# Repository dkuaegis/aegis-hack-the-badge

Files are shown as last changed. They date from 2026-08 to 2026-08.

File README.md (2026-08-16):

# Hack The Badge Ver.3

## Sponsored by

<p align="center">
  <a href="https://easyeda.com/">
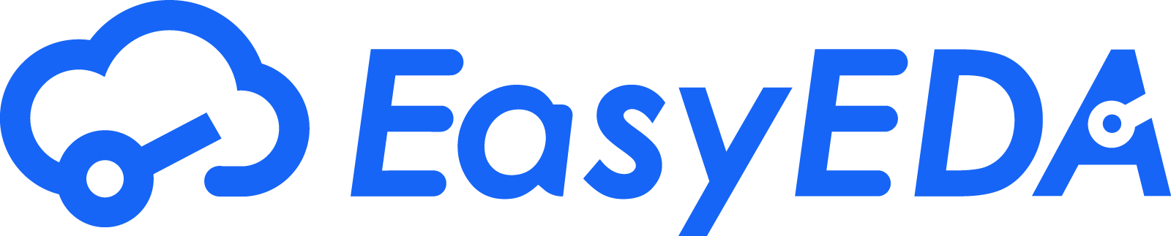
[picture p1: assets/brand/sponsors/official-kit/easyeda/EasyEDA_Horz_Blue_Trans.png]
EasyEDA
    
  </a>
  &nbsp;&nbsp;&nbsp;&nbsp;
  <a href="https://jlcpcb.com/">
    JLCPCB
  </a>
</p>

해당 프로젝트는 EasyEDA로 제작되었고 EasyEDA 측의 제작 지원을 받았습니다. <br>
PCB 제작은 JLCPCB 측의 지원을 받았습니다.

## 프로젝트 소개

`Hack The Badge Ver.3`는 정보보안 동아리 Aegis가 MSG CTF 본선
부스에서 운영하는 체험형 하드웨어 해킹 프로젝트입니다. ESP32-S3를
기반으로 OLED, 버튼, LED, USB Serial, UART, challenge pad, 부저를
하나의 PCB 배지에 구성해, 행사 배지와 해킹 문제 도구로 함께 사용할
수 있도록 제작했습니다.

## 제작 목적

참가자가 일반적인 소프트웨어 CTF를 넘어 실제 PCB의 입출력 장치와
통신 인터페이스를 직접 살펴보며 하드웨어 보안을 체험하도록 하는 것이
목표입니다. 문제 풀이 결과가 화면, LED, 소리로 즉시 반영되는 상호작용을
통해 하드웨어 해킹을 처음 접하는 참가자도 쉽게 몰입할 수 있도록
구성했습니다.

## 체험 활동

참가자는 배지를 USB로 연결한 뒤 다음 활동을 진행합니다.

- Serial 터미널에서 문제를 확인하고 FLAG를 제출합니다.
- OLED와 버튼으로 문제, 힌트, 미니게임을 이용합니다.
- UART와 challenge pad를 분석해 숨겨진 하드웨어 문제를 해결합니다.
- OLED, LED, 부저를 통해 문제 진행 상태와 완료 결과를 확인합니다.

## 현재 제작 리비전

- 리비전: Hack The Badge Ver.3
- MCU: ESP32-S3-WROOM-1-N8R8
- 디스플레이: HS96L03W2C03 0.96 inch I2C OLED, PCBA 이후 수작업 납땜
- 사용자 I/O: USB Serial, 3.3 V UART, 버튼 3개, 상태 LED 5개
- Challenge I/O: 1 kOhm 직렬 저항으로 보호되는 `C0`, `C1`, `C2` GPIO pad
- 관리자/디버그: 복구와 bring-up을 위한 후면 staff test pad
- 오디오: MOSFET으로 구동하는 passive buzzer
- PCB 스타일: 검정 solder mask, 흰색 silkscreen, Aegis 방패 외형

## 저장소 구조

```text
assets/brand/                         Aegis, MSG CTF, EasyEDA, JLCPCB 로고
docs/rev3/                            설계, 제작, 스폰서 관련 문서
hardware/design/rev3/kicad/           KiCad 호환 회로도, PCB, 라이브러리
hardware/design/rev3/reference/       BOM 메모, 데이터시트, 전기적 설계 메모
hardware/releases/rev3/jlcpcb/upload/ JLCPCB 업로드용 Gerber, BOM, CPL
hardware/releases/rev3/easyeda-pro/   EasyEDA Pro 프로젝트 패키지와 체크리스트
hardware/releases/rev3/jlcpcb/        제작 파일, 조립 파일, preview, 검증 리포트
archive/                              이전 설계/제작 이력
tools/                                문서 생성 보조 스크립트
firmware/                             ESP32-S3 문제/UI/관리자 펌웨어
```

펌웨어 빌드, 문제 교체, Serial 명령과 무선 관리자 사용법은
[`firmware/README.md`](firmware/README.md)를 참고하세요.

## 제작 산출물

JLCPCB 업로드 파일:

| 단계 | 파일 |
| --- | --- |
| PCB 제작 | `hardware/releases/rev3/jlcpcb/upload/hacking_badge_v3_jlcpcb_gerbers.zip` |
| PCBA BOM | `hardware/releases/rev3/jlcpcb/upload/hacking_badge_v3_jlcpcb_bom.csv` |
| PCBA CPL | `hardware/releases/rev3/jlcpcb/upload/hacking_badge_v3_jlcpcb_cpl.csv` |

EasyEDA Pro 프로젝트 패키지:

| 용도 | 파일 |
| --- | --- |
| EasyEDA Pro 실크 호환 프로젝트 | `hardware/releases/rev3/easyeda-pro/upload/hacking_badge_v3_easyeda_pro_silk_compat_import.zip` |
| EasyEDA Pro 프로젝트(KiCad 호환) | `hardware/releases/rev3/easyeda-pro/upload/hacking_badge_v3_easyeda_pro_kicad_import.zip` |
| EasyEDA Pro 프로젝트 아카이브 | `hardware/releases/rev3/easyeda-pro/reference/ProPrj_hack_the_badge_rev.3.epro2` |

## 3D Preview

홍보물 제작이나 웹/Blender preview에는 검정 PCB 색상이 보정된 GLB 파일을
사용하는 것을 권장합니다.

| 용도 | 파일 |
| --- | --- |
| 검정 PCB 홍보용 GLB | `hardware/releases/rev3/jlcpcb/preview/3d/hacking_badge_v3_full_assembly_black.glb` |
| 검정 PCB 3D export 묶음 | `hardware/releases/rev3/jlcpcb/preview/3d/hacking_badge_v3_3d_exports_black.zip` |
| 전체 3D export 묶음 | `hardware/releases/rev3/jlcpcb/preview/3d/hacking_badge_v3_3d_exports.zip` |

## 검증 상태

현재 확인된 상태:

- Schematic ERC: 0 errors, 0 warnings
- Schematic-to-PCB validation: PASS
- JLCPCB manufacturing validation: PASS
- Gerber ZIP SHA256:
  `b55b42de45568e995e8cb47bb18cfc09abd5469c50e1fb60852d323a703e96b1`

유용한 검증 명령:

```bash
/Applications/KiCad/KiCad.app/Contents/MacOS/kicad-cli sch erc \
  --format report \
  -o hardware/design/rev3/kicad/reports/erc-final.rpt \
  hardware/design/rev3/kicad/hacking_box_v2.kicad_sch

/Applications/KiCad/KiCad.app/Contents/Frameworks/Python.framework/Versions/3.9/bin/python3.9 \
  hardware/design/rev3/kicad/scripts/validate_schematic_against_pcb.py

/Applications/KiCad/KiCad.app/Contents/Frameworks/Python.framework/Versions/3.9/bin/python3.9 \
  hardware/design/rev3/kicad/scripts/validate_manufacturing.py
```

## 참고 사항

- KiCad 파일명은 초기 프로젝트/라이브러리 이름을 유지하기 위해
  `hacking_box_v2`를 사용합니다. 실제 제작 리비전은 Ver.3입니다.
- `OLED1`은 JLCPCB BOM/CPL에서 제외되어 있으며, 별도 구매 후 수작업으로
  납땜하는 기준입니다.
- JLCPCB SMT viewer에서 자동 placement alignment 알림이 뜨면 취소하고,
  기존 CPL 기준 배치가 유지되는지 확인합니다. 방패 형태의 custom outline
  때문에 false offset warning이 뜰 수 있습니다.
- Challenge pad는 3.3 V GPIO 전용입니다. 회로를 의도적으로 수정하지 않은
  상태에서 `VBUS`, `3V3`, `EN`, `BOOT` 단락을 문제 풀이 요소로 노출하지
  마세요.

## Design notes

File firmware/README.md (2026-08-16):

# Hack The Badge Rev.3 Firmware

ESP32-S3-WROOM-1-N8R8용 펌웨어입니다. 기존
[`Z3r0c0k3/hacking-box`](https://github.com/Z3r0c0k3/hacking-box) 최신
`main` 커밋 `4b0b2cd`의 Serial 문제 흐름과 영구 상태 저장 방식을 Rev.3 PCB에
맞게 다시 구현했습니다.

## 구현 기능

- USB CDC Serial(115200): 문제 설명, FLAG 제출, 상태 확인
- 128x64 OLED: 문제 보기/예시, 3버튼 메뉴, 반응속도 미니게임
- LED1-LED5: 4개 Serial 문제와 `Hidden Access` 풀이 상태
- NVS: 전원을 꺼도 풀이 상태 유지
- `Hidden Access`: 전면 challenge pad의 올바른 두 접점을 1.2초간 쇼트하면 해금
- Wi-Fi 관리자: 부팅 중 `LEFT + RIGHT`를 1.5초간 누른 경우에만 임시 AP/웹/API 활성화

관리자 AP와 웹 비밀번호는 부팅할 때마다 무작위로 생성되어 OLED와 Serial에
표시됩니다. `http://192.168.4.1`에 접속하고 사용자명 `admin`을 사용합니다.
일반 부팅에서는 무선 기능이 켜지지 않습니다.

운영자 확인용 기본 Hidden Access 조합은 **C1을 개방한 상태에서 C0-C2를
1.2초간 연결**하는 것입니다. 조합이나 유지 시간은 `logic.h`와 `main.cpp`의
`HIDDEN_HOLD_MS`에서 변경할 수 있습니다.

## 빌드와 업로드

PlatformIO에서 다음을 실행합니다.

```bash
cd firmware
pio run
pio run -t upload
pio device monitor
```

보드는 ESP32-S3 DevKitC 프로필, 8 MB flash, 8 MB octal PSRAM 설정을
사용합니다. USB CDC가 보이지 않으면 BOOT를 누른 채 리셋해 처음 한 번
업로드한 뒤 다시 연결하세요.

## 문제 교체

[`src/problems.h`](src/problems.h)의 `PROBLEMS` 배열만 수정합니다.

- `title`: OLED와 상태표에 표시할 짧은 ASCII 제목
- `answer`: Serial에서 비교할 정확한 FLAG
- `serialText`: Serial에 출력할 문제 설명
- `oledLines`: OLED에만 출력할 보기/예시 5줄(줄당 ASCII 16자 권장)

Rev.3 상태 LED가 5개이므로 기본 구성은 Serial 문제 4개 + Hidden Access 1개입니다.
문제 개수를 바꾸려면 LED 정책과 `static_assert`도 함께 검토해야 합니다.

미니게임 보상 힌트는 같은 파일의 `MINIGAME_REWARD_LINE_1/2`를 바꾸면 됩니다.

## Serial 명령

| 명령 | 기능 |
| --- | --- |
| `1`~`4` | 문제 선택 |
| `hint` | 선택한 문제의 OLED 보기 다시 표시 |
| `exit` | 문제 풀이 모드 종료 |
| `status` | 전체 풀이 상태 |
| `help` | 사용법 |
| `reset` | 풀이 상태 초기화 |
| `aegis` | 시작 배너 다시 표시 |

## 관리자 API

HTTP Basic 인증이 필요합니다.

| Method | Path | 기능 |
| --- | --- | --- |
| GET | `/api/status` | 풀이 상태 JSON |
| POST | `/api/solve?id=1` | 지정 문제 성공 처리(1~5) |
| POST | `/api/reset` | 전체 상태 초기화 |
| POST | `/api/reboot` | 재부팅 |

## 안전 및 핀 매핑

핀은 [`src/pins.h`](src/pins.h)에 있으며 PCB 회로 문서와 동일합니다. Hidden
Access 감지 중 C0는 LOW로만 구동되고 C1/C2는 pull-up 입력입니다. 펌웨어의
의도된 쇼트 대상은 보호 저항 뒤의 challenge pad뿐입니다. `3V3`, `VBUS`,
`EN`, `BOOT` 또는 GND를 임의로 쇼트하지 마세요.

OLED는 전체 1 KB framebuffer 대신 U8x8 text mode를 사용하고, Serial 입력도
고정 192바이트 버퍼를 사용해 동적 메모리 사용을 줄였습니다.

## 빠른 로직 검사

PlatformIO 없이도 상태 비트와 Hidden Access 판정 로직을 검사할 수 있습니다.

```bash
clang++ -std=c++17 -Ifirmware/src firmware/test/test_logic.cpp -o /tmp/badge-logic-test
/tmp/badge-logic-test
```

## Wokwi 통합 시뮬레이션

VS Code에서 `firmware` 폴더를 열고 PlatformIO로 한 번 빌드한 다음,
Command Palette의 `Wokwi: Start Simulator`를 실행합니다.

```bash
pio run
```

`diagram.json`은 Rev.3의 펌웨어 관찰 가능 회로를 다음과 같이 재현합니다.

- SSD1315와 명령어 호환되는 `board-ssd1306` OLED: GPIO4/5, I2C `0x3c`
- Left/OK/Right active-low 버튼: GPIO9/10/12, 키보드 ←/Space/→
- active-high 상태 LED 5개: GPIO13-17, 실회로와 같은 1k 직렬 저항
- 부저 드라이버 등가 출력: GPIO18
- challenge pad 직렬 저항 1k와 C0-C1/C0-C2 쇼트 스위치

Hidden Access는 `H`를 1.2초 이상 눌러 C0-C2를 연결하면 됩니다. `J`는
C0-C1을 연결하는 오답 조합입니다. 관리자 부팅은 Left와 Right 버튼을
Cmd-click해 둘 다 고정한 뒤 ESP32-S3 보드의 RST 버튼을 누릅니다.

Wokwi는 GPIO, I2C, 버튼, LED, 부저, USB CDC 편의 동작을 검사하며,
USB-C 전기 특성, 3.3V 전원, ESD, MOSFET 부하, RF와 실제 OLED 편차는
실물 보드에서 별도로 검사해야 합니다.

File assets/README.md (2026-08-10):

# Brand Assets

- `brand/aegis/`: Aegis 원본 SVG와 문서용 PNG
- `brand/msg-ctf/`: 후면 음각에 사용하는 MSG CTF 원본 PNG
- `brand/sponsors/jlcpcb-logo.svg`: 전면 실크에 사용하는 단색 sponsor SVG
- `brand/sponsors/official-kit/`: JLCPCB/EasyEDA가 제공한 원본 로고 패키지

PCB 생성 스크립트는 이 폴더의 원본을 직접 참조합니다.

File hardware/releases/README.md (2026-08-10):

# Hardware Releases

- `rev3/jlcpcb/`: 현재 생산에 사용하는 JLCPCB Rev.3 릴리스
- `rev3/jlcpcb/upload/`: JLCPCB 주문 화면에 직접 업로드하는 Gerber ZIP,
  BOM, CPL

다른 제조사 견적과 과거 출력은 `archive/manufacturing/`에 보관합니다.

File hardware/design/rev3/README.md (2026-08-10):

# Hardware Design Rev.3

- `kicad/`: 현재 편집 가능한 KiCad 프로젝트, 로컬 라이브러리와 검증 도구
- `reference/bom/`: BOM 초안과 부품 선정 근거
- `reference/datasheets/`: 설계에 사용한 부품 데이터시트
- `reference/electrical/`: 회로 설명과 넷리스트 문서

제조사 업로드 파일은 `../../releases/rev3/jlcpcb/upload/`에 있습니다.

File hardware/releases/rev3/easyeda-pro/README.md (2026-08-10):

# Hacking Badge Ver.3 EasyEDA Pro Package

This directory contains the EasyEDA Pro preparation package for sponsor/coupon
workflow.

## Upload / Import Files

| Purpose | File |
| --- | --- |
| Recommended EasyEDA Pro import package | `upload/hacking_badge_v3_easyeda_pro_silk_compat_import.zip` |
| Raw KiCad source import package | `upload/hacking_badge_v3_easyeda_pro_kicad_import.zip` |
| Previous EasyEDA Pro archive reference | `reference/ProPrj_hack_the_badge_rev.3.epro2` |

Use the silkscreen-compatible import package first when the goal is sponsor
review or coupon use in EasyEDA Pro. It is derived from the current production
KiCad design, but converts filled silkscreen polygons into dense line artwork
because EasyEDA Pro's KiCad importer can otherwise show complex filled logos as
hollow outlines. The raw KiCad import package is kept only as a reference for
format comparison. The `.epro2` file is kept as a reference/native archive
candidate, but it was generated before the final KiCad release checks and must
not be assumed to be identical without review.

## Import Procedure

1. Open EasyEDA Pro.
2. Use the start page import flow for KiCad files, or use the EasyEDA Pro Format
   Converter if direct import fails.
3. Select `upload/hacking_badge_v3_easyeda_pro_silk_compat_import.zip`.
4. After import, open both schematic and PCB.
5. Rebuild/refill copper zones only if EasyEDA Pro asks for it, then compare
   against the KiCad release previews and Gerbers.
6. Run EasyEDA Pro DRC/ERC before using any generated manufacturing output.

## Required Post-Import Checks

- Board outline remains the Aegis shield shape, approximately 84.05 x 100.05 mm.
- USB-C connector sits on the bottom edge with the intentional edge overhang.
- ESP32-S3 antenna keep-out is still clear.
- Front silkscreen includes `Aegis X MSG CTF`, `HACK THE BADGE Ver.3`,
  `Developed By @Z3r0c0k3_`, full Aegis logo, and sponsor mark.
- Rear silkscreen preserves the filled Aegis silhouette and MSG CTF negative
  mark.
- Filled logo areas may look lightly striped at extreme zoom because the
  EasyEDA-compatible package uses dense silkscreen lines instead of KiCad
  filled polygons.
- `C0`, `C1`, `C2` challenge pads route through 1 kOhm series resistors to
  ESP32-S3 GPIO6, GPIO7, GPIO8.
- OLED pin order remains `GND, VCC, SCL, SDA`.
- J1, U1, U2, D1, Q_BZ, LEDs, buzzer diode, and switches have correct rotation.
- Copper zones and clearances match the KiCad/JLCPCB manufacturing release.

## Important Warning

The routed KiCad project and the JLCPCB release package remain the production
source of truth until the EasyEDA Pro import is manually reviewed. EasyEDA Pro
can import KiCad files, but format conversion can change copper-zone results.
Do not manufacture from newly generated EasyEDA Pro Gerbers until visual review,
DRC/ERC, and pin/net checks pass.

## Checksums

See `SHA256SUMS.txt`.

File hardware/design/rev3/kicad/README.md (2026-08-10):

# Hacking Badge Ver.3 KiCad Project

This directory contains the routed production PCB, connected review
schematic, project-local symbols and footprints, 3D assets, and electrical
verification reports for the ESP32-S3 Hacking Badge Ver.3.

## Directory Layout

- Project root: editable KiCad project and local libraries only.
- `scripts/`: deterministic generation and validation scripts.
- `reports/`: current DRC, ERC, netlist, and validation reports.
- `exports/`: current human-readable schematic and 3D PDF exports.
- Historical PCB revisions, autorouter sessions, rescue files, and superseded
  renders live in `../../../../archive/design/rev3-development/` and are not
  used for production.

## Main Design Files

- `hacking_box_v2.kicad_sch`: connected one-page A3 production schematic.
- `hacking_box_v2.kicad_pcb`: routed two-layer production PCB.
- `hacking_box_v2.kicad_pro`: KiCad project settings.
- `exports/hacking_box_v2_schematic.pdf`: printable schematic.
- `hacking_box_v2-cache.lib`: project-local legacy symbol source.
- `sym-lib-table`: local symbol-library registration.
- `hacking_box_v2.pretty/`: local buzzer and OLED footprints.
- `hacking_box_v2.3dshapes/`: local OLED 3D model.
- `../reference/datasheets/HS96L03W2C03.pdf`: source module datasheet used for the
  OLED outline, mounting holes, pin order, and hand-solder pad review.

The notes-only schematic that preceded the connected capture is archived at
`../../../../archive/design/rev3-development/pcb-revisions/hacking_box_v2_notes_only_2026-07-28.kicad_sch`.

## Schematic Organization

The A3 sheet groups USB-C and power, ESP32-S3, OLED, five status LEDs, three
game controls, challenge pads, player UART, rear staff testpoints, and the
buzzer driver. Global net labels make each PCB net explicit without long
cross-sheet wires.

The schematic was reverse-captured from the finished PCB. It is electrically
equivalent to the PCB, but this revision did not originate through KiCad's
normal schematic-first association flow. Review symbol-footprint associations
before using **Update PCB from Schematic**.

## Verification

- Schematic ERC: 0 errors, 0 warnings.
- Schematic-to-PCB validation: PASS.
- Components: 60 in schematic and PCB.
- Named nets: 37 in schematic and PCB.
- Connected component-pin pairs: 149.
- Intentional no-connect pins: 20.
- PCB DRC: 0 error-level violations and 0 unconnected items.

Reports:

- `reports/erc-final.rpt`
- `reports/schematic-pcb-validation.txt`
- `reports/drc_report_jlcdfm_fixes.txt`

## Regeneration

Run `scripts/generate_production_schematic.py` with KiCad's bundled Python to
recreate the legacy capture and local symbol library from PCB pad/net data.
Open the generated `hacking_box_v2.sch` in KiCad and save it to refresh the
modern `.kicad_sch`.

Run `scripts/add_jlcpcb_sponsor_logo.py` with KiCad's bundled Python to rebuild
the front `Sponsored by` EasyEDA/JLCPCB sponsor mark in the left-center
silkscreen area. The script groups the generated logo polygons and restores the
lower-left decorative border that was previously interrupted by the old
JLCPCB-only mark.

Export an XML netlist, then run
`scripts/validate_schematic_against_pcb.py` with KiCad's bundled Python. The
validator compares references, values, named pin-to-net mappings, and
intentional no-connect pins.

## Manufacturing

The order artifacts are in `hardware/releases/rev3/jlcpcb/`; the three files
uploaded to JLCPCB are isolated in its `upload/` directory. `OLED1` is excluded
from the JLCPCB BOM/CPL and appears in `assembly/` as a separate manual list. Its
footprint uses 2.0 mm pads with a 1.1 mm nominal PTH drill for hand soldering.
The Gerber, drill, BOM, CPL, and validation reports were regenerated after
this change and the supplied JLCDFM findings. The final fabrication package
uses 0.80 mm plated USB-C slots, 0.20 mm minimum drills, 0.15 mm minimum
silkscreen strokes, and mask-subtracted silkscreen output.

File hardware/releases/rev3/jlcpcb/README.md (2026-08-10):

# Hacking Badge Ver.3 Manufacturing Package

This directory is the final revision 3 JLCPCB upload package.

## Upload These Files

| JLCPCB step | File |
| --- | --- |
| PCB fabrication | `upload/hacking_badge_v3_jlcpcb_gerbers.zip` |
| PCBA BOM | `upload/hacking_badge_v3_jlcpcb_bom.csv` |
| PCBA CPL | `upload/hacking_badge_v3_jlcpcb_cpl.csv` |

Recommended order options:

- Quantity: 5
- Layers: 2
- PCB thickness: 1.6 mm
- Solder mask: black
- Silkscreen: white
- PCBA: top side SMT only; `OLED1` is excluded and hand-soldered afterward

## Package Contents

- `upload/`: the three files uploaded directly to JLCPCB.
- `fabrication/gerber/`: uncompressed Gerber, drill, drill-map, and Gerber job files.
- `fabrication/hacking_badge_v3.ipc`: IPC-2581 exchange export.
- `assembly/hacking_badge_v3_assembly.glb`: complete visual assembly model.
- `assembly/hacking_badge_v3_assembly.step`: mechanical assembly export. The custom OLED
  VRML model may not be embedded in this STEP; use the GLB or PNG previews for
  complete visual review.
- `preview/`: top, bottom, and isometric KiCad renders.
- `reports/`: DRC, drill, board statistics, JLCDFM disposition, and automated
  package validation.
- `assembly/hacking_badge_v3_manual_assembly.csv`: locally sourced parts that are not
  uploaded to JLCPCB.

## Verified State

- KiCad electrical DRC: 0 errors and 0 unconnected items. Two source-layout
  warnings remain on the board-scale rear logo by design; the production
  Gerbers subtract solder-mask openings from silkscreen before plotting.
- JLCDFM hardening: 0.20/0.25 mm via drills, at least 0.20 mm via annular
  rings, 0.80 mm USB-C plated slots, 0.15 mm minimum silkscreen strokes,
  0.05 mm global solder-mask expansion, and 0.13 mm minimum mask web.
- Gerber ZIP: exact 12-file fabrication set.
- Board: 2 layers, 1.6 mm, approximately 84.05 x 100.05 mm.
- Assembly: 15 grouped BOM lines and 44 unique top-side placements.
- Buzzer circuit populated: SMD5020-ZK, AO3400A, 1N4148W, gate resistors, and
  local 10 uF capacitor.
- OLED installed manually after PCBA: locally sourced HS96L03W2C03, white
  0.96 inch 128x64 SSD1315 I2C module. The manual list recommends six modules
  for five boards so one spare is available.
- Game controls populated: `<-` on GPIO9, `OK` on GPIO10, and `->` on GPIO12.
- Front logo reproduces the complete circular source logo. Its original white
  regions print on F.SilkS and its black regions show through as black PCB.
- The front sponsor mark appears inside the left-center F.SilkS guide area as
  `Sponsored by`, `EasyEDA`, and `JLCPCB`; the previous lower-left JLCPCB-only
  mark was removed and the decorative border there was restored.
- Rear Aegis silhouette is filled with white B.SilkS at board scale. The
  30 mm MSG CTF mark is negative space that exposes the black solder mask.
- Rear staff testpoints and their labels are shifted 4 mm downward, clear of the
  logo artwork, and their local routes were revalidated after the move.

The detailed disposition of every item in the supplied PCB and SMT DFM reports
is recorded in `reports/jlcdfm_resolution.md`.

## Order Review

The CPL uses KiCad's manufacturing coordinate system, matching the Gerber and
official KiCad position export: X is unchanged and all top-side Y coordinates
are negative. The package validator rejects a CPL generated with the PCB
editor's downward-positive Y axis.

The CPL also contains verified per-package placement corrections for J1
(`C165948`), U1 (`C2913201`), U2 (`C6186`), D1 (`C2827654`), and Q_BZ
(`C20917`). The affected LCSC/EasyEDA origins or rotations do not coincide with
the KiCad footprint anchors. Do not replace these rows with the uncorrected
KiCad position-export values.

When JLCPCB shows the reminder `The system detects component that may be
offset from the PCB, does it try to automatically align it?`, select `Cancel`.
The custom shield outline and the intentional USB-C edge overhang can trigger
this false positive. Selecting `Ok` can translate or mirror the complete
placement set away from the PCB. If that happens, upload the original BOM and
CPL again; do not manually drag the scattered components into place.

Before payment, inspect every polarized or pin-1-sensitive part in the JLCPCB
placement preview, especially `U1`, `J1`, `D1`, `D_BZ`, `Q_BZ`, all LEDs, and
the tactile switches. Recheck LCSC stock because availability and PCBA class
can change.

The similar USB-C STEP model in the KiCad 3D view is visualization-only. The
fabrication footprint and BOM selection remain TYPE-C-31-M-12 (`C165948`).

The OLED module is excluded from both JLCPCB upload files. After PCBA, install
it on the front with pin order `GND, VCC, SCL, SDA` and connect VCC only to
3.3 V. The footprint uses 2.0 mm pads with a 1.1 mm nominal PTH drill for practical
hand soldering. If the module is supplied without pins, use a straight 1x4
2.54 mm male header.

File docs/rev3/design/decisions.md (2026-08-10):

# Hack The Badge / Hacking Box V2 Phase 1 Decision Log

Status: Phase 1 decision log for JLCPCB support preparation. Items marked as
"approved for Phase 1" are approved only as requirements for the next design
step. They are not final PCB fabrication approval.

## Approved For Phase 1

| ID | Decision | Reason |
| --- | --- | --- |
| D-001 | Prepare documentation before schematic and PCB work. | The project needs a clear support package before hardware design proceeds. |
| D-002 | Target a small-run event PCB for Hack The Badge / Hacking Box V2. | The device is for a CTF booth, not mass production. |
| D-003 | Use an ESP32-S3-WROOM module as the recommended MCU baseline. | It provides native USB, optional Wi-Fi/BLE, enough memory, and lower RF risk than a bare chip. |
| D-004 | Use USB-C as the default connector for power, serial, and recovery. | It is convenient for both participants and booth staff. |
| D-005 | Limit participant-facing interfaces to USB Serial, UART, and protected challenge GPIO pads. | This provides an intentional hacking surface while reducing accidental exposure of fragile signals. |
| D-006 | Design exposed digital interfaces for 3.3 V logic. | This matches ESP32-S3 and modern peripheral requirements. |
| D-007 | Include a 128x64 I2C OLED as the baseline display. | It can show logos, status, and challenge messages in a compact area. |
| D-008 | Include multiple status LEDs. | Participants and staff can quickly read challenge progress. |
| D-009 | Include three tactile switches as baseline inputs. | They can support left/OK/right navigation, mini-games, or an admin-unlock gesture. |
| D-010 | Treat Wi-Fi/BLE as staff-only unless separately approved for gameplay. | This helps prevent management features from becoming an unintended bypass. |
| D-011 | Exclude battery charging from Phase 1. | USB-only power is simpler, safer, and easier to review for the first PCB design. |
| D-012 | Prefer a 2-layer PCB and mostly single-side SMT assembly. | This keeps small-run fabrication and assembly cost manageable. |

## V1 Compatibility Decisions

| ID | Decision | Reason |
| --- | --- | --- |
| C-001 | Review V1 firmware before freezing the pin map. | The current repository does not include V1 firmware source, so exact compatibility cannot be verified yet. |
| C-002 | Plan V2 firmware as an ESP32-S3 port or rewrite. | Arduino Nano/ATmega328P binaries cannot run directly on ESP32-S3. |
| C-003 | Preserve participant-facing USB Serial behavior by default. | This is likely the main continuity point from the existing challenge flow. |
| C-004 | Preserve or port UART challenge behavior at 3.3 V. | UART is part of the intended hacking surface, but ESP32-S3 pins are not 5 V tolerant. |
| C-005 | Keep challenge state visible through LEDs and/or OLED. | Event staff and participants need quick visual state confirmation. |

## Open Decisions Requiring Approval

The following items must be resolved after V1 firmware review and before
schematic capture.

| ID | Area | Decision needed | Why it matters |
| --- | --- | --- | --- |
| O-001 | V1 firmware | Provide the actual V1 source, archive, or pin documentation. | Compatibility should be verified from code, not assumptions. |
| O-002 | MCU | Confirm the exact ESP32-S3-WROOM part number, flash size, and PSRAM size. | This affects BOM, firmware partitioning, price, and availability. |
| O-003 | Quantity | Confirm whether the first build is 5 units, 10 units, or another quantity. | Quantity affects unit price, spare strategy, and assembly choices. |
| O-004 | OLED assembly | Decide whether the OLED is included in PCBA or hand-soldered after assembly. | This affects BOM/CPL, footprint choice, manual work, and replacement strategy. |
| O-005 | Buzzer | Approve or remove the buzzer circuit. | It adds useful feedback but increases board area, BOM lines, and firmware work. |
| O-006 | Challenge pads | Finalize pad count, labels, protection, and intended solve path. | This defines the core hardware hacking experience. |
| O-007 | Button roles | Decide whether buttons are player controls, admin unlock, mini-game inputs, or a mix. | This affects labeling, placement, and firmware behavior. |
| O-008 | Wireless management | Define Wi-Fi/BLE mode, authentication, provisioning, and whether wireless remains enabled during attempts. | Management access must not become an unintended challenge bypass. |
| O-009 | Power budget | Confirm worst-case current for ESP32-S3 radio, OLED, LEDs, and buzzer. | This determines regulator choice and thermal margin. |
| O-010 | Protection | Decide whether USB fuse/PTC, extra ESD, or stronger GPIO protection is required. | The board will be handled directly by participants. |
| O-011 | Shape and artwork | Approve final outline, logo placement, silkscreen text, and event branding. | These affect manufacturability and sponsor-facing presentation. |
| O-012 | Staff recovery | Decide whether EN/BOOT are pads only or physical buttons. | This balances event recovery convenience against accidental participant access. |
| O-013 | Assembly vendor | Confirm JLCPCB as the first-run assembly vendor or select an alternative. | Part availability, PCBA process, and output formats depend on the vendor. |
| O-014 | Distribution model | Decide whether boards are reused, collected, or given to participants. | This affects durability expectations, labeling, and acceptable cost. |

## Risks To Resolve Before Schematic Capture

- V1 firmware is missing from this repository, so hardware compatibility
  requirements are not yet verified.
- ESP32-S3 uses 3.3 V logic; any V1 dependency on Arduino Nano 5 V behavior
  requires redesign, level shifting, or explicit removal.
- Participant-accessible pads need protection resistors and clear voltage
  labeling.
- Wi-Fi/BLE management requires authentication and a physical or procedural
  unlock policy.
- The exact OLED module pin order and availability must be confirmed before
  final footprint approval.
- Live JLCPCB stock, PCBA part class, and assembly cost should be rechecked
  immediately before final BOM approval.

## Phase 1 Exit Criteria

Phase 1 is complete when:

- The project owner has reviewed this decision log.
- The availability or absence of V1 firmware source has been explicitly
  acknowledged.
- The open decisions required for schematic capture have been approved.
- The proposed pin map has been accepted as a firmware-port target or revised
  based on V1 firmware evidence.

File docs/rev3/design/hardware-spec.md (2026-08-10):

# Hack The Badge / Hacking Box V2 Phase 1 Hardware Specification

Status: Phase 1 project description and hardware requirements draft. This
document is prepared for JLCPCB fabrication and PCBA support review. It is not a
schematic, PCB layout, Gerber package, BOM/CPL release, or production approval.

## Project Overview

Hack The Badge is a hardware hacking badge project for the Aegis booth at the
MSG CTF event. The board should look and feel like an event badge while also
serving as a small interactive challenge device. Participants connect to and
interact with the badge through USB Serial, UART, exposed challenge pads,
buttons, LEDs, and a small OLED display.

The goal of Hacking Box V2 Phase 1 is to define a manufacturable PCB baseline
that can replace or extend the existing V1 prototype while preserving the
participant-facing challenge flow as much as possible. This phase documents the
requirements and open questions that must be approved before schematic capture
and PCB layout begin.

## Why JLCPCB Support Is Needed

The project is moving from a prototype-style build toward a repeatable
small-run PCB suitable for event use. We are preparing to request support from
JLCPCB for:

- Reviewing the proposed hardware architecture before schematic capture.
- Selecting parts suitable for low-volume JLCPCB SMT assembly.
- Checking whether the participant-accessible interfaces are electrically safe.
- Reducing manual wiring and assembly errors compared with the V1 prototype.
- Confirming whether the planned OLED, USB-C, buttons, LEDs, and buzzer are
  practical for PCBA or should be handled as manual assembly.
- Preparing a clear requirements package before generating Gerbers, BOM, and
  CPL files.

Phase 1 does not create a schematic, PCB layout, Gerber ZIP, BOM, or CPL. These
documents are intended to align the project scope and approval items before the
next hardware design phase.

## Target Use Case

| Item | Requirement |
| --- | --- |
| Event role | CTF booth hardware hacking badge / Hacking Box |
| Users | Participants, booth staff, firmware maintainers |
| Expected quantity | Small run, assumed 5-10 units unless approved otherwise |
| Power | USB-powered by default |
| Participant interfaces | USB Serial, 3.3 V UART, intentional GPIO challenge pads |
| Staff interfaces | USB recovery/flashing, optional Wi-Fi/BLE management |
| Visual identity | Aegis / MSG CTF branding, OLED status, PCB silkscreen |
| Manufacturing target | 2-layer PCB, mostly single-side SMT assembly where practical |

## Recommended Hardware Architecture

| Function | Phase 1 baseline | Reason |
| --- | --- | --- |
| MCU | ESP32-S3-WROOM module | Native USB, optional Wi-Fi/BLE, enough memory, lower RF layout risk than a bare chip |
| Logic voltage | 3.3 V | Matches ESP32-S3 and modern OLED modules |
| USB | USB-C device port | Power, serial console, firmware upload, staff recovery |
| Display | 0.96 inch 128x64 I2C OLED | Compact logo, status, and challenge text display |
| Input | Three tactile switches | Left/OK/right controls, mini-game input, or admin-unlock gesture |
| Output | Five status LEDs | Clear challenge progress and solved-state indication |
| Audio | Passive buzzer with MOSFET driver, if approved | Audible feedback without directly loading an MCU GPIO |
| Challenge I/O | UART plus three protected GPIO pads | Intentional hardware hacking surface |
| Wireless | Staff-only Wi-Fi/BLE, if used | Reset, provisioning, and status monitoring without exposing management functions to players |

## Electrical Requirements

### USB And Power

- USB-C should be configured as a USB 2.0 device port.
- VBUS should feed a 3.3 V regulator with enough current and thermal margin for
  the ESP32-S3, OLED, LEDs, and optional buzzer.
- USB D+ and D- should include ESD protection and follow ESP32-S3 native USB
  routing recommendations.
- Staff recovery access for EN/reset and BOOT mode must be available.
- Battery charging is out of scope unless separately approved.

### Controller

- Prefer an ESP32-S3-WROOM module variant that is available through the selected
  assembly flow.
- Respect the ESP32-S3 module antenna keep-out area.
- Avoid using boot strapping pins for participant-facing challenge signals.
- Select a module with enough firmware headroom for the OLED UI, challenge
  logic, and optional staff management features.

### Display

- Use an SSD1306/SSD1315-compatible 128x64 I2C OLED.
- Treat the default I2C address as `0x3C` until the exact module datasheet is
  confirmed.
- If the OLED module is not suitable or economical for JLCPCB assembly, it may
  be hand-soldered after PCBA.
- Firmware should be able to show the Aegis / MSG CTF logo and challenge status
  on the display.

### Participant-Accessible Interfaces

- USB Serial remains the primary participant interface.
- Provide a separate 3.3 V UART TX/RX interface through labeled pads or a small
  header.
- Add series resistors or equivalent protection to exposed challenge GPIO pads.
- All exposed digital signals must be documented as 3.3 V only and not
  5 V tolerant.
- Keep I2C internal by default unless the final challenge design explicitly
  requires exposing it.

### Feedback Devices

- Status LEDs should be active-high unless V1 firmware review requires a
  different polarity.
- Buttons should be active-low with firmware pull-ups or hardware pull-ups.
- If a passive buzzer is used, it must be driven with PWM rather than a static
  high level.
- The buzzer should be driven through a MOSFET or transistor driver instead of
  directly from an MCU GPIO.

## V1 Firmware Compatibility Review

This repository does not currently include V1 firmware source files such as
Arduino `.ino`, C/C++ source, PlatformIO configuration, or a documented V1 pin
map. Therefore, Phase 1 cannot claim binary compatibility or source-level
compatibility with V1.

The inferred compatibility requirements are:

- Preserve the participant-facing USB Serial challenge workflow.
- If V1 used a UART challenge, port that behavior to a 3.3 V UART interface.
- Preserve visible challenge progress through multiple status LEDs.
- If V1 used physical button input, preserve the same participant-facing
  interaction using ESP32-S3 GPIO inputs.
- If V1 used a display, port the logo/status behavior to a 128x64 I2C OLED.
- Staff must be able to recover boards at the event using USB flashing, reset,
  and BOOT mode access.
- Because ESP32-S3 cannot run ATmega328P/Arduino Nano binaries, V2 firmware
  should be treated as a port or rewrite.

Before schematic capture, the actual V1 firmware repository or source archive
should be reviewed for:

- V1 pin assignments.
- Serial baud rate and command protocol.
- Startup, reset, and challenge state behavior.
- Timing-sensitive GPIO behavior.
- Display library and resolution assumptions.
- Any dependency on Arduino Nano 5 V electrical behavior.

## Mechanical And Visual Requirements

- Use a badge-like PCB outline, preferably inspired by the Aegis shield.
- Preferred visual direction: black solder mask with white silkscreen.
- The front side should clearly show the Hack The Badge, Aegis, and MSG CTF
  identity.
- USB-C should be placed on an accessible board edge with cable clearance.
- Participant pads should be reachable and identifiable, but the labeling
  should not reveal the complete challenge solution.
- Staff-only recovery pads should be separated from the primary participant
  interaction area.

## JLCPCB Review Questions

- Which ESP32-S3-WROOM module variant is recommended for availability and PCBA
  cost?
- Should the OLED module be included in PCBA or handled as manual assembly?
- Are the proposed USB-C receptacle, tactile switches, LEDs, and buzzer suitable
  for single-side SMT assembly?
- Is an input fuse/PTC recommended for a participant-handled USB-powered board?
- Are additional ESD or protection components recommended for exposed UART and
  challenge pads?
- Are there any design-for-manufacturing concerns with a shield-shaped outline
  and decorative silkscreen artwork?

## Phase 1 Deliverables

- `docs/rev3/design/hardware-spec.md`: project description and hardware requirements.
- `docs/rev3/design/decisions.md`: approved decisions, deferred decisions, and open items.
- `docs/rev3/design/pin-map.md`: proposed pin map and V1 firmware compatibility notes.

## Out Of Scope For Phase 1

- KiCad schematic creation.
- PCB layout.
- Gerber, BOM, or CPL generation.
- Final component purchase.
- Production order placement.
- Firmware port implementation.

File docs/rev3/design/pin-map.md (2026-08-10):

# Hack The Badge / Hacking Box V2 Phase 1 Pin Map

Status: Proposed firmware-facing pin map for review. This is not a frozen PCB
pinout. It must be checked against the V1 firmware before schematic capture.

## Pin Map Goals

- Keep USB Serial available for participants and firmware flashing.
- Provide UART and challenge GPIO pads as intentional hacking interfaces.
- Avoid ESP32-S3 boot strapping pins for normal participant challenge signals.
- Keep OLED, LEDs, buttons, and buzzer simple to port in firmware.
- Leave EN and BOOT access available for staff recovery.

## Proposed ESP32-S3 Assignment

| Function | Proposed ESP32-S3 signal | Direction | Electrical behavior | Notes |
| --- | --- | --- | --- | --- |
| USB D- | `GPIO19` | USB | Native USB | Effectively fixed for ESP32-S3 native USB |
| USB D+ | `GPIO20` | USB | Native USB | Effectively fixed for ESP32-S3 native USB |
| OLED SDA | `GPIO4` | I/O | 3.3 V I2C with pull-up | Confirm final OLED module pull-ups |
| OLED SCL | `GPIO5` | Output | 3.3 V I2C with pull-up | Assumed display address: `0x3C` |
| Challenge pad 0 | `GPIO6` | I/O | 3.3 V through series resistor | Expose only after challenge design approval |
| Challenge pad 1 | `GPIO7` | I/O | 3.3 V through series resistor | Expose only after challenge design approval |
| Challenge pad 2 | `GPIO8` | I/O | 3.3 V through series resistor | Expose only after challenge design approval |
| Left button | `GPIO9` | Input | Active-low with pull-up | Player control or menu navigation |
| OK button | `GPIO10` | Input | Active-low with pull-up | Confirm/action input |
| Right button | `GPIO12` | Input | Active-low with pull-up | Player control or admin-chord candidate |
| Status LED 1 | `GPIO13` | Output | Active-high | Initialize low at boot |
| Status LED 2 | `GPIO14` | Output | Active-high | Initialize low at boot |
| Status LED 3 | `GPIO15` | Output | Active-high | Initialize low at boot |
| Status LED 4 | `GPIO16` | Output | Active-high | Initialize low at boot |
| Status LED 5 | `GPIO17` | Output | Active-high | Initialize low at boot |
| Buzzer PWM | `GPIO18` | Output | MOSFET-driven PWM | Use only if buzzer is approved |
| Player UART TX | `GPIO43` | Output | 3.3 V through series resistor | Board transmits to participant equipment |
| Player UART RX | `GPIO44` | Input | 3.3 V through series resistor | Not 5 V tolerant |
| Boot mode | `GPIO0` | Input | Pull-up, staff access | Do not use as challenge GPIO |
| Reset / enable | `EN` | Input | Pull-up, staff access | Recovery/reset only |

## Participant-Facing Interfaces

| Interface | Signals | Voltage | Compatibility requirement |
| --- | --- | --- | --- |
| USB Serial | USB D+, USB D-, VBUS, GND | USB 5 V power, native USB data | Preserve the same user experience if V1 used a Serial command flow |
| UART pads | TX, RX, GND, optional 3V3 reference | 3.3 V logic | Port V1 UART challenge behavior to ESP32-S3 |
| Challenge pads | `GPIO6`, `GPIO7`, `GPIO8`, GND reference | 3.3 V GPIO | Final behavior must match the approved challenge design |
| Buttons | Left, OK, Right | Active-low 3.3 V | Preserve V1 physical interactions if present |

## Internal Interfaces

| Interface | Signals | Notes |
| --- | --- | --- |
| OLED | SDA, SCL, 3V3, GND | SSD1306/SSD1315-compatible 128x64 I2C OLED |
| Status LEDs | LED1-LED5 | Active-high recommended for simpler firmware logic |
| Buzzer | PWM output to driver | Passive buzzer requires PWM, not a static output |
| Wi-Fi/BLE | ESP32-S3 radio | Staff-only unless separately approved |

## Staff Recovery Interfaces

| Interface | Signals | Placement requirement |
| --- | --- | --- |
| USB flashing | USB-C | Accessible board edge with cable clearance |
| Boot mode | `GPIO0`, GND | Pad or button away from easy participant access |
| Reset | `EN`, GND | Staff-accessible pad or button |
| Debug bring-up | 3V3, GND, UART TX/RX | Useful for firmware porting and event repair |

## V1 Firmware Compatibility Notes

This repository does not currently include V1 firmware source. Once the V1
source or pin documentation is provided, review:

- Whether V1 assumes an Arduino Nano / ATmega328P pin map.
- Whether V1 depends on 5 V GPIO, analog input, EEPROM, timers, or interrupt
  pins.
- Whether V1 Serial behavior depends on USB CDC, UART baud rate, or both.
- Whether LEDs are active-high or active-low.
- Whether buttons require hardware pull-ups, pull-downs, or specific debounce
  timing.
- Whether any challenge depends on timing that may change on ESP32-S3.
- Whether display code assumes SSD1306, SSD1315, address `0x3C`, or a specific
  OLED module.

Because ESP32-S3 cannot run ATmega328P binaries, compatibility means preserving
the participant-visible behavior and challenge flow through a firmware port, not
reusing the old binary.

## Firmware Bring-Up Checklist

- Confirm USB CDC Serial connection.
- Initialize all LED pins low before showing state.
- Configure button pull-ups and debounce.
- Initialize I2C and scan for the OLED address.
- Confirm UART TX/RX orientation from the participant's perspective.
- Keep challenge GPIOs in a safe input state until firmware intentionally uses
  them.
- Keep the buzzer pin low until PWM is intentionally started.
- Confirm EN/BOOT recovery before event deployment.

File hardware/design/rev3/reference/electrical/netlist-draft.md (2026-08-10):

# Hacking Badge Ver.3 Netlist Record

Status: Human-readable summary of the final PCB nets. The KiCad PCB remains the
machine-readable source of truth.

## Power

| Net | Members |
| --- | --- |
| `VBUS` | USB-C VBUS, AMS1117 input, USB-side bulk/decoupling, VBUS test pad |
| `3V3` | AMS1117 output, ESP32-S3 supply, OLED supply, pull-ups, buzzer positive, 3V3 test pad |
| `GND` | USB shield/ground, ESP32 grounds, regulator ground, capacitor returns, switches, LEDs, UART ground, MOSFET source |

## USB

| Net | Members |
| --- | --- |
| `USB_D_N` | `J1.D-`, `D1`, `U1.GPIO19` |
| `USB_D_P` | `J1.D+`, `D1`, `U1.GPIO20` |
| `USB_CC1` | `J1.CC1`, `R1`; opposite resistor end to GND |
| `USB_CC2` | `J1.CC2`, `R2`; opposite resistor end to GND |

## Control And Display

| Net | Members |
| --- | --- |
| `EN` | `U1.EN`, `R_EN`, `C_EN`, EN test pad |
| `BOOT_GPIO0` | `U1.GPIO0`, `R_BOOT`, BOOT test pad |
| `GAME_LEFT` | `U1.GPIO9`, `SW_EN.1`; `SW_EN.2` to GND |
| `GAME_OK` | `U1.GPIO10`, `SW_BOOT.1`; `SW_BOOT.2` to GND |
| `GAME_RIGHT` | `U1.GPIO12`, `SW_ADMIN.1`; `SW_ADMIN.2` to GND |
| `OLED_SDA` | `U1.GPIO4`, OLED SDA, `R_SDA` |
| `OLED_SCL` | `U1.GPIO5`, OLED SCL, `R_SCL` |

## Status LEDs

| MCU net | GPIO | Series path |
| --- | --- | --- |
| `STATUS_LED_1_MCU` | `GPIO13` | `R_LED1` -> `STATUS_LED_1_A` -> `LED1` -> GND |
| `STATUS_LED_2_MCU` | `GPIO14` | `R_LED2` -> `STATUS_LED_2_A` -> `LED2` -> GND |
| `STATUS_LED_3_MCU` | `GPIO15` | `R_LED3` -> `STATUS_LED_3_A` -> `LED3` -> GND |
| `STATUS_LED_4_MCU` | `GPIO16` | `R_LED4` -> `STATUS_LED_4_A` -> `LED4` -> GND |
| `STATUS_LED_5_MCU` | `GPIO17` | `R_LED5` -> `STATUS_LED_5_A` -> `LED5` -> GND |

## UART And Challenge

| MCU net | GPIO | Series path |
| --- | --- | --- |
| `UART_TX_MCU` | `GPIO43` | `R_UART_TX` -> `PLAYER_UART_TX` |
| `UART_RX_MCU` | `GPIO44` | `R_UART_RX` -> `PLAYER_UART_RX` |
| `CHAL_0_MCU` | `GPIO6` | `R_CHAL0` -> `CHAL_0` |
| `CHAL_1_MCU` | `GPIO7` | `R_CHAL1` -> `CHAL_1` |
| `CHAL_2_MCU` | `GPIO8` | `R_CHAL2` -> `CHAL_2` |

## Buzzer

| Net | Members |
| --- | --- |
| `BUZZER_GPIO` | `U1.GPIO18`, `R_BZ.1` |
| `BUZZER_GATE` | `R_BZ.2`, `Q_BZ.G`, `R_BZ_PD.1`; `R_BZ_PD.2` to GND |
| `BUZZER_SW` | `BZ1.-`, `Q_BZ.D`, `D_BZ.A` |
| `3V3` | `BZ1.+`, `D_BZ.K`, `C9.1`; `C9.2` to GND |

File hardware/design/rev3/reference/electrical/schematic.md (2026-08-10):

# Hacking Badge Ver.3 Production Schematic

Status: Connected KiCad schematic reverse-captured from the routed production
PCB on 2026-07-28.

The editable schematic is
`hardware/design/rev3/kicad/hacking_box_v2.kicad_sch`. A printable A3 PDF is
available under `hardware/design/rev3/kicad/exports/` as
`hacking_box_v2_schematic.pdf`. The schematic contains
all 60 PCB references, all 37 named nets, and every intentional no-connect.

The routed and DRC-clean `hacking_box_v2.kicad_pcb` remains the manufacturing
source of truth for this revision. The schematic and PCB are checked by the
repository validator, but they were not created through KiCad's normal
schematic-first symbol-to-footprint association flow. Review associations
before using **Update PCB from Schematic**.

## USB And Power

| Ref | Part | Connection |
| --- | --- | --- |
| `J1` | TYPE-C-31-M-12, `C165948` | USB-C VBUS, GND, D+, D-, CC1, CC2 |
| `R1`, `R2` | 5.1 kohm, `C23186` | CC1/CC2 pulldown to GND |
| `D1` | USBLC6-2SC6, `C2827654` | ESD protection for D+ and D- |
| `U2` | AMS1117-3.3, `C6186` | VBUS to regulated 3V3 |
| `C1`, `C3`, `C4`, `C5`, `C7` | 10 uF, `C15850` | USB, regulator, and module bulk capacitance |
| `C2`, `C6`, `C8` | 100 nF, `C14663` | High-frequency decoupling |

USB data connects to the ESP32-S3 native USB pins:

- `USB_D_N` -> `GPIO19`
- `USB_D_P` -> `GPIO20`

The board is USB-powered. Battery charging and a battery power path are not
included.

## Controller

| Ref | Part | Notes |
| --- | --- | --- |
| `U1` | ESP32-S3-WROOM-1-N8R8, `C2913201` | Native USB, Wi-Fi/BLE, 8 MB flash and 8 MB PSRAM variant |
| `R_EN` | 10 kohm | EN pull-up |
| `C_EN` | 1 uF | EN reset timing |
| `R_BOOT` | 10 kohm | GPIO0 pull-up |

The ESP32-S3 module antenna faces the board edge. Its antenna keep-out excludes
copper, vias, and components.

## OLED

`OLED1` is the locally sourced `HS96L03W2C03`, a white 0.96 inch 128x64 I2C
module with an SSD1315 controller. It is excluded from the JLCPCB BOM/CPL and
hand-soldered after PCBA. The footprint follows the manufacturer datasheet and
uses 2.0 mm pads with a 1.1 mm nominal PTH drill for the four-pin header. The
default address is `0x3C`.

| Signal | ESP32-S3 pin | Supporting parts |
| --- | --- | --- |
| `OLED_SDA` | `GPIO4` | 10 kohm pull-up `R_SDA` |
| `OLED_SCL` | `GPIO5` | 10 kohm pull-up `R_SCL` |
| `3V3` | Power | Local 100 nF `C_OLED` |
| `GND` | Ground | Common ground plane |

## Status LEDs

All five indicators use `KT-0603R` red LEDs (`C2286`) and 1 kohm series
resistors (`C21190`). They are active high.

| LED | GPIO | MCU-side net | LED anode net |
| --- | --- | --- | --- |
| `LED1` | `GPIO13` | `STATUS_LED_1_MCU` | `STATUS_LED_1_A` |
| `LED2` | `GPIO14` | `STATUS_LED_2_MCU` | `STATUS_LED_2_A` |
| `LED3` | `GPIO15` | `STATUS_LED_3_MCU` | `STATUS_LED_3_A` |
| `LED4` | `GPIO16` | `STATUS_LED_4_MCU` | `STATUS_LED_4_A` |
| `LED5` | `GPIO17` | `STATUS_LED_5_MCU` | `STATUS_LED_5_A` |

Each path is `GPIO -> R_LEDn -> LEDn anode`; every LED cathode returns to GND.

## Buttons

| Ref | Signal | ESP32-S3 pin | Behavior |
| --- | --- | --- | --- |
| `SW_EN` | `GAME_LEFT` / `<-` | `GPIO9` | Active low, firmware pull-up |
| `SW_BOOT` | `GAME_OK` / `OK` | `GPIO10` | Active low, firmware pull-up |
| `SW_ADMIN` | `GAME_RIGHT` / `->` | `GPIO12` | Active low, firmware pull-up |

EN and GPIO0 are available on rear staff test pads for reset and boot recovery.
The three front buttons are normal GPIO inputs for post-solve mini-games.

## Buzzer Driver

The buzzer circuit is populated in the production BOM.

| Ref | Part | Connection |
| --- | --- | --- |
| `BZ1` | SMD5020-ZK, `C49246955` | Positive to 3V3, negative to `BUZZER_SW` |
| `Q_BZ` | AO3400A, `C20917` | N-channel low-side switch |
| `R_BZ` | 1 kohm | `BUZZER_GPIO` to `BUZZER_GATE` |
| `R_BZ_PD` | 10 kohm | Gate pulldown to GND |
| `D_BZ` | 1N4148W, `C917030` | Flyback clamp from `BUZZER_SW` to 3V3 |
| `C9` | 10 uF | Local 3V3 buzzer bulk capacitor |

`GPIO18` drives `BUZZER_GPIO`. Firmware should initialize it low, then use PWM
near the buzzer's nominal resonant frequency for tones.

## Player UART And Challenge Pads

| External net | ESP32-S3 pin | Protection |
| --- | --- | --- |
| `PLAYER_UART_TX` | `GPIO43` | 1 kohm `R_UART_TX` |
| `PLAYER_UART_RX` | `GPIO44` | 1 kohm `R_UART_RX` |
| `CHAL_0` | `GPIO6` | 1 kohm `R_CHAL0` |
| `CHAL_1` | `GPIO7` | 1 kohm `R_CHAL1` |
| `CHAL_2` | `GPIO8` | 1 kohm `R_CHAL2` |

All exposed logic is 3.3 V only.

## Verification

- KiCad schematic ERC: 0 errors, 0 warnings.
- Schematic-to-PCB validation: PASS.
- Components compared: 60.
- Named nets compared: 37.
- Connected component-pin pairs compared: 149.
- Intentional no-connect pins compared: 20.
- KiCad error-level DRC: 0 violations.
- KiCad unconnected check: 0 items.
- PCB stackup: two copper layers, 1.6 mm.
- JLCPCB BOM: 15 grouped lines.
- JLCPCB CPL: 44 unique top-side placements.
- Manual assembly list: `OLED1` only.
- Gerber package: 12 required fabrication files.

Validation artifacts:

- `hardware/design/rev3/kicad/reports/erc-final.rpt`
- `hardware/design/rev3/kicad/reports/schematic-pcb-validation.txt`
- `hardware/design/rev3/kicad/reports/hacking_box_v2_schematic.xml`

Regeneration tools:

- `hardware/design/rev3/kicad/scripts/generate_production_schematic.py`
  recreates the legacy capture and
  project-local symbol library from the PCB pad/net data.
- `hardware/design/rev3/kicad/scripts/validate_schematic_against_pcb.py`
  compares references, values,
  connected pins, net names, and intentional no-connects.

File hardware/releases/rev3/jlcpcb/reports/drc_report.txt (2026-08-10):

** Drc report for hacking_box_v2.kicad_pcb **
** Created on 2026-08-10T11:52:12 **
** Report includes: Errors, Warnings, Exclusions **

** Found 2 DRC violations **
[silk_edge_clearance]: Silkscreen clipped by board edge
    Rule: 기판 구성 제약 실크; warning
    @(24.3439 mm, 86.8013 mm): 세그먼트 (Edge.Cuts)
    @(72.7746 mm, 25.8337 mm): 다각형 (B.Silkscreen)
[silk_over_copper]: Silkscreen clipped by solder mask
    Local override; warning
    @(72.7746 mm, 25.8337 mm): 다각형 (B.Silkscreen)

** Found 0 unconnected pads **

** Found 0 Footprint errors **

** Ignored checks **
    - Footprint has no courtyard defined
    - Track endpoint not centered on via
    - Tuning profile track geometries
    - Footprint doesn't match symbol's footprint filters
    - Footprint component type doesn't match footprint pads

** End of Report **

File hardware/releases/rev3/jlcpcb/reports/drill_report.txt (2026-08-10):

Drill report for hacking_box_v2.kicad_pcb
Created on 2026-08-10T11:25:36

Copper Layer Stackup:
    =============================================================
    L1 :  F.Cu                      front
    L2 :  B.Cu                      back

Drill file 'hacking_box_v2-PTH.drl' contains
    plated through holes:
    =============================================================
    T1  0.200mm  0.0079"  (43 holes))
    T2  0.200mm  0.0079"  (12 holes))
    T3  0.250mm  0.0098"  (22 holes))
    T4  0.800mm  0.0315"  (4 holes)  (with 4 slots)
    T5  1.000mm  0.0394"  (4 holes))
    T6  1.100mm  0.0433"  (4 holes))

    Total plated holes count 89

Drill file 'hacking_box_v2-NPTH.drl' contains
    unplated through holes:
    =============================================================
    T1  0.900mm  0.0354"  (2 holes))
    T2  2.200mm  0.0866"  (4 holes))
    T3  2.700mm  0.1063"  (2 holes))

    Total unplated holes count 8

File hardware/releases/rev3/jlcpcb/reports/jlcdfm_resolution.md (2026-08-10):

# JLCDFM Resolution Record

This record maps the supplied PCB and SMT DFM reports to the final Rev.3 board
and manufacturing package generated on 2026-08-02.

## PCB Fabrication Checks

| Report item | Final disposition |
| --- | --- |
| Three sharp B.Cu trace corners | Replaced with short orthogonal/45-degree transitions. |
| 0.15 mm annular-ring warnings | Standard vias now use 0.60/0.20 mm or 0.65/0.25 mm copper/drill pairs. U1 thermal holes use 0.60/0.20 mm pads/drills. |
| Solder-mask openings split into multiple shapes | Duplicate USB-C mask/paste geometry was removed from pads B1, B4, B9, and B12. U1 thermal holes are tented. |
| Negative solder-mask expansion | Board-wide expansion is +0.05 mm. J1 has a -0.05 mm local correction, producing a net 1:1 opening for its fine-pitch pads rather than a negative opening. |
| Silkscreen-to-pad/hole danger and warnings | Gerber plotting subtracts solder-mask openings from both silkscreen layers. The C1 border was rerouted and nonessential J1/BZ1 outlines were moved to Fab. |
| 0.11 mm silkscreen lines | All plotted nonzero silkscreen apertures are at least 0.15 mm. |
| Four 0.60 mm plated-slot dangers | USB-C shell slots are now 0.80 mm wide and 1.70 mm long. |

## SMT Assembly Checks

| Report item | Final disposition |
| --- | --- |
| Through-hole alignment warning | USB-C locating pegs were enlarged from 0.65 mm to 0.90 mm; shell slots were widened to 0.80 mm. |
| Component clipped by board outline | Intentional for J1. The USB-C receptacle must overhang the lower edge for cable access. Do not auto-align the complete placement set in the JLCPCB viewer. |
| 0.02 mm pin-edge and lead/pad model findings | These are JLC component-model-to-footprint comparisons, not KiCad copper-clearance failures. The production footprints were retained because enlarging every flagged pad causes real copper-clearance violations. Recheck orientation and model alignment in the JLCPCB 3D viewer after upload. |

## Final Verification

- KiCad DRC: 0 errors, 0 unconnected pads.
- Remaining source warnings: two intentional rear-logo silkscreen checks.
- Production silkscreen: plotted with solder-mask subtraction enabled.
- Gerber archive: exactly 12 fabrication files.
- Drill output: minimum finished drill 0.20 mm; USB-C plated slots 0.80 mm.
- Schematic-to-PCB validation: PASS for 60 components, 37 nets, 149 connected pins, and 20 intentional no-connect pins.
- BOM/CPL validation: 15 grouped BOM lines and 44 unique top-side placements.

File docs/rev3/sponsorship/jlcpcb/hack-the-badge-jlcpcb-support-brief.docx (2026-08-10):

JLCPCB SUPPORT BRIEF

Hack The Badge / Hacking Box V2

Phase 1 hardware requirements based on the existing Arduino Hacking Badge project

Prepared for: JLCPCB fabrication and PCBA support review

Prepared by: Aegis / MSG CTF project team

Date: August 4, 2026

Status: Requirements draft; schematic and PCB layout are out of scope for Phase 1

Reference project: https://github.com/Z3r0c0k3/hacking-box

# Executive Summary

Hack The Badge is a CTF booth hardware hacking badge for the Aegis / MSG CTF event. The requested JLCPCB support is focused on reviewing the hardware concept before schematic capture, confirming PCBA feasibility, and identifying manufacturability or component-selection risks early.

This V2 effort is based on the existing Z3r0c0k3/hacking-box Arduino Hacking Badge project. The original project provides a serial shell-style challenge, multiple independent puzzles, LED feedback, and persistent solve state. V2 is intended to preserve the participant-visible challenge flow while moving to a repeatable ESP32-S3-based PCB suitable for a small event run.

## Visual Reference

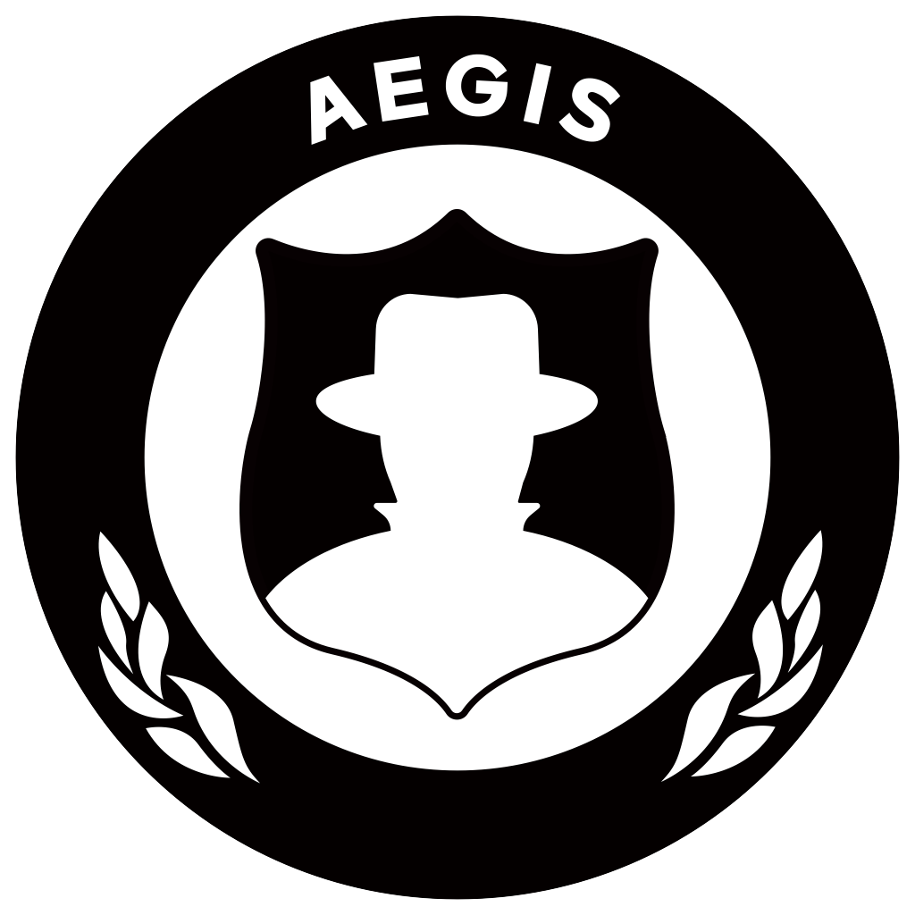
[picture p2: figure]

Figure 1. Example Aegis ring artwork rendered from black-white-ring.svg for badge identity reference.

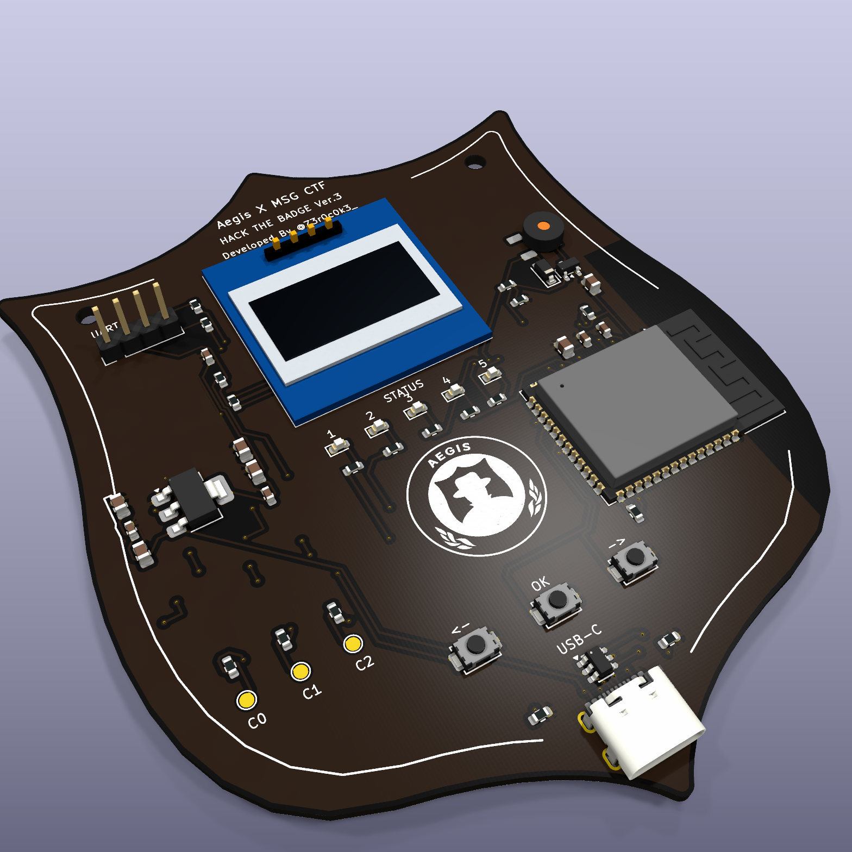
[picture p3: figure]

Figure 2. Existing local badge render used as a visual direction reference only; this brief does not release a new PCB design.

# Based On The Existing Hacking Box Project

The public reference project is Z3r0c0k3/hacking-box on GitHub. Its README describes an Arduino Hacking Badge that mimics the kind of badge hacking experience distributed at larger CTF finals. The repository contains example, old, and template badge firmware folders, and the README identifies Arduino IDE, C/C++, EEPROM, and PROGMEM as the technical foundation.

- Four independent puzzle slots are described in the reference project.
- Each solved puzzle maps to LED feedback, with additional LED animation when all puzzles are solved.
- A shell-like serial monitor interface lets participants start the game, select problems, check status, reset progress, clear the screen, and exit a problem.
- The README documents 4800 baud serial monitor setup and an Arduino Uno/Nano-style hardware baseline.
- Large challenge text and ASCII art are stored in program memory using PROGMEM, while solve state is persisted using EEPROM.

# Support Requested From JLCPCB

- Review the proposed architecture before schematic capture and PCB layout.
- Recommend JLCPCB-available parts for low-volume SMT assembly.
- Advise whether the OLED module should be assembled by JLCPCB or hand-soldered after PCBA.
- Review USB-C, ESD, input protection, exposed UART/GPIO pads, buttons, LEDs, and optional buzzer for PCBA practicality.
- Identify DFM issues related to a badge-shaped PCB outline and decorative silkscreen artwork.
- Help confirm which decisions must be frozen before Gerber, BOM, and CPL generation.

# Target Hardware Baseline

Function | Phase 1 baseline | Reason
MCU | ESP32-S3-WROOM module | Native USB, optional Wi-Fi/BLE, more memory, and lower RF risk than a bare chip.
Logic voltage | 3.3 V | Matches ESP32-S3 and modern peripheral modules.
USB | USB-C device port | Power, serial console, firmware upload, and staff recovery.
Display | 0.96 inch 128x64 I2C OLED | Compact logo, status, and challenge text display.
Input | Three tactile switches | Left/OK/right controls, mini-game input, or admin-unlock gesture.
Output | Five status LEDs | Clear challenge progress and solved-state indication.
Audio | Passive buzzer with driver, if approved | Optional audible feedback without directly loading MCU GPIO.
Challenge I/O | UART plus protected GPIO pads | Intentional hardware hacking surface for participants.

# Compatibility Requirements

V2 should be treated as a firmware port or rewrite, not as a direct binary-compatible replacement for the Arduino Nano / ATmega328P reference implementation. The participant-visible behavior should remain familiar.

- Preserve the USB Serial shell-style challenge workflow.
- Preserve the puzzle selection model and status commands where practical.
- Map solved-state feedback to multiple LEDs, with room for an all-solved animation.
- Replace EEPROM persistence with ESP32-S3 non-volatile storage while preserving visible behavior.
- Review any V1 dependency on 5 V Arduino electrical behavior before exposing signals on a 3.3 V board.
- Keep staff recovery practical through USB flashing plus EN/reset and BOOT access.

# Proposed ESP32-S3 Pin Map

Function | Signal | Behavior | Notes
USB D- | GPIO19 | Native USB | Fixed for ESP32-S3 USB use.
USB D+ | GPIO20 | Native USB | Fixed for ESP32-S3 USB use.
OLED SDA | GPIO4 | 3.3 V I2C | Confirm final OLED pull-ups.
OLED SCL | GPIO5 | 3.3 V I2C | Assume display address 0x3C until confirmed.
Challenge 0 | GPIO6 | 3.3 V through series resistor | Expose only after challenge approval.
Challenge 1 | GPIO7 | 3.3 V through series resistor | Expose only after challenge approval.
Challenge 2 | GPIO8 | 3.3 V through series resistor | Expose only after challenge approval.
Left / OK / Right | GPIO9 / GPIO10 / GPIO12 | Active-low inputs | Use pull-ups and debounce.
Status LEDs | GPIO13-GPIO17 | Active-high outputs | Initialize low at boot.
Buzzer PWM | GPIO18 | MOSFET-driven PWM | Only if buzzer is approved.
Player UART TX/RX | GPIO43 / GPIO44 | 3.3 V through series resistors | Not 5 V tolerant.
Boot / reset | GPIO0 / EN | Staff recovery | Do not use as challenge GPIO.

# Open Decisions Before Schematic Capture

ID | Decision needed | Why it matters
O-001 | Confirm exact ESP32-S3-WROOM module variant. | Affects BOM, firmware partitioning, availability, and price.
O-002 | Confirm first-run quantity. | Affects unit price, spare strategy, and assembly options.
O-003 | Decide whether OLED is PCBA-installed or hand-soldered. | Affects BOM/CPL, footprint, and replacement workflow.
O-004 | Approve or remove the buzzer. | Adds feedback but increases board area and firmware work.
O-005 | Finalize challenge pad behavior and labels. | Defines the core hardware hacking experience.
O-006 | Define Wi-Fi/BLE management policy. | Management access must not become an unintended bypass.
O-007 | Decide protection level for USB and exposed GPIO/UART. | Participant handling increases electrical abuse risk.
O-008 | Approve badge shape and silkscreen artwork. | Impacts DFM, branding, and support review.

# Questions For JLCPCB Review

- Which ESP32-S3-WROOM module variant is recommended for current PCBA availability and cost?
- Should the OLED module be included in PCBA or handled as manual assembly?
- Are the proposed USB-C receptacle, tactile switches, LEDs, and passive buzzer suitable for single-side SMT assembly?
- Is an input fuse/PTC recommended for a participant-handled USB-powered board?
- Are additional ESD or protection components recommended for exposed UART and challenge pads?
- Are there DFM concerns with a shield-shaped outline and decorative black/white silkscreen artwork?

# Phase 1 Scope Boundary

This brief intentionally stops before schematic capture. The next phase should begin only after the open decisions above are approved and the V1 firmware behavior has been reviewed against the proposed ESP32-S3 pin map.

- No new schematic is released by this document.
- No new PCB layout is released by this document.
- No Gerber, BOM, CPL, or production order package is released by this document.
- No firmware port is implemented by this document.

# References

Existing project: https://github.com/Z3r0c0k3/hacking-box

Artwork source: black-white-ring.svg, provided Aegis ring artwork source

Local planning documents: docs/hardware-spec.md, docs/decisions.md, docs/pin-map.md

Phase 1 requirements draft

Hack The Badge / Hacking Box V2 - JLCPCB Support Brief

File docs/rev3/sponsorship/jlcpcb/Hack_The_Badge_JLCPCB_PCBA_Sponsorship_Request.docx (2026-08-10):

PCBA SPONSORSHIP REQUEST

Hack The Badge

Request for JLCPCB sponsorship of approximately 10 fully assembled PCBA units for MSG CTF

Requester: Aegis Security Team / MSG CTF

Request type: PCB fabrication, component procurement, SMT assembly, and delivery support

Requested quantity: Approximately 10 completed units

Delivery destination: Republic of Korea

Schedule request: Preferably within 7 days; absolute maximum 14 days after production approval

Design status: Circuit and PCB design completed; production files are available for review

# Request Summary

Hack The Badge is an interactive cybersecurity badge project operated by the Aegis Security Team for the MSG CTF finals booth. Participants connect to the badge over USB Serial and solve cybersecurity challenges embedded in the badge experience.

We are requesting JLCPCB sponsorship support for approximately 10 fully assembled PCBA units. In this document, completed units means assembled PCBA boards ready for project-side firmware loading and event preparation. This request does not ask JLCPCB to provide an enclosure, retail packaging, or firmware programming unless those services are separately offered and confirmed.

Item | Request / current status
Requested support | PCB fabrication, parts, component procurement, SMT assembly, and delivery support as available from JLCPCB.
Quantity | Approximately 10 completed PCBA units.
Timing | Please confirm whether completion and delivery to South Korea is possible within 7 days if feasible, or within 14 days at the latest.
Design status | Circuit and PCB design are completed. This is a production feasibility and urgent schedule request, not a pre-design review.
Destination | Republic of Korea.

## Project Visuals


Visual references: Aegis badge artwork and current Hack The Badge PCB render.

# Production Files Available For Review

The current project folder includes JLCPCB-oriented manufacturing outputs. These files can be provided for immediate review. The attached manufacturing package is available for immediate review. The requested sponsorship production quantity is approximately 10 units.

File / artifact | Status | Notes
Gerber ZIP | Available for immediate review | JLCPCB fabrication package is present in the project folder.
JLCPCB BOM CSV | Available for immediate review | Current SMT assembly BOM is present; live stock and pricing should be rechecked by JLCPCB.
JLCPCB CPL CSV | Available for immediate review | Current component placement file is present for review.
Manufacturing validation | Available for immediate review | Local validation report is present and records the available package state.
Manual assembly list | Available for immediate review | OLED1 is listed separately in the current package; please confirm whether JLCPCB can support it for completed PCBA units.

# Hardware Scope

The badge is based on an ESP32-S3-WROOM class MCU and is designed as a USB-powered interactive CTF device. The main participant interface is USB Serial, with additional intentional challenge pads for UART/GPIO interaction.

Subsystem | Included in the design
Controller | ESP32-S3-WROOM series module
USB and power | USB-C device connector and required power/protection circuitry.
User interface | OLED display, tactile switches, and LEDs.
Challenge interface | UART/GPIO challenge pads and required protection components.
Assembly target | Fully assembled PCBA boards. Please confirm whether OLED sourcing/placement can be included by JLCPCB.

# Requested Sponsorship Scope Confirmation

Please confirm which parts of the production and delivery scope JLCPCB may be able to sponsor or discount. Partial sponsorship is still useful if full coverage is not available.

Scope area | Confirmation requested from JLCPCB
PCB fabrication | Can JLCPCB sponsor or discount the PCB fabrication cost for approximately 10 units?
Component cost | Can JLCPCB sponsor or discount the electronic component cost?
Component procurement | Can JLCPCB procure all listed PCBA components, or identify parts requiring substitution/approval?
SMT assembly | Can JLCPCB sponsor or discount SMT assembly for the requested quantity?
OLED / non-SMT handling | Can JLCPCB support the OLED as part of completed PCBA units, or should it remain outside JLCPCB assembly?
Shipping | Can JLCPCB sponsor, discount, or expedite shipping of the completed PCBA units to South Korea?

# Urgent Schedule Confirmation

The project is intended for use at the MSG CTF finals booth. Please confirm the fastest realistic schedule after file review and production approval. We are specifically asking whether completed PCBA units can be fabricated, assembled, and shipped to South Korea within the following windows.

Schedule window | Requested confirmation
Preferred | Completion and delivery to South Korea within 7 days if feasible.
Maximum acceptable | Completion and delivery to South Korea within 14 days at the latest.
If not feasible | Please provide the earliest realistic production and delivery schedule and identify the bottleneck.

# Review Questions For JLCPCB

- Can JLCPCB support approximately 10 completed PCBA units for this Hack The Badge project?
- Can the available Gerber, BOM, and CPL files be reviewed immediately for production feasibility?
- Which cost areas can JLCPCB sponsor or discount: PCB fabrication, parts, procurement, SMT assembly, or shipping?
- Is the 7-day preferred schedule possible, including shipment to South Korea? If not, is 14 days possible?
- Are there any components that require substitution, stock confirmation, or special handling before production approval?
- Can JLCPCB include the OLED in the completed PCBA scope, or should the OLED remain a separate project-side assembly step?

# References

Existing project background: https://github.com/Z3r0c0k3/hacking-box

Attached manufacturing package: Gerber, BOM, CPL, and manufacturing validation files

Primary files for review: hacking_badge_v3_jlcpcb_gerbers.zip, hacking_badge_v3_jlcpcb_bom.csv, hacking_badge_v3_jlcpcb_cpl.csv

PCBA sponsorship request

Hack The Badge - JLCPCB PCBA Sponsorship Request

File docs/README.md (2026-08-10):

# Documentation

- `rev3/design/`: 현재 하드웨어 요구사항, 결정 기록과 핀맵
- `rev3/manufacturing/`: Rev.3 조립 및 주문 계획
- `rev3/sponsorship/jlcpcb/`: JLCPCB 후원 요청 DOCX/PDF
- `archive/rev2/`: 생산에 사용하지 않는 Ver.2 초기 설계안

실제 생산 파일은 `hardware/releases/rev3/jlcpcb/`에 있습니다.

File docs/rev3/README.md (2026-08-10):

# Rev.3 Documentation

- `design/`: 현재 사양, 결정 기록과 핀맵
- `manufacturing/`: JLCPCB 조립 및 주문 계획
- `sponsorship/jlcpcb/`: JLCPCB 후원 요청 문서

과거 Ver.2 문서는 `../archive/rev2/`에 있습니다.

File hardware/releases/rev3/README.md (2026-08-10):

# Hardware Release Rev.3

`jlcpcb/`가 현재 생산 릴리스입니다. 주문에 직접 사용하는 파일은
`jlcpcb/upload/`에만 있으며 나머지 하위 폴더는 fabrication 원본, 조립
자료, 프리뷰와 검증 보고서입니다.

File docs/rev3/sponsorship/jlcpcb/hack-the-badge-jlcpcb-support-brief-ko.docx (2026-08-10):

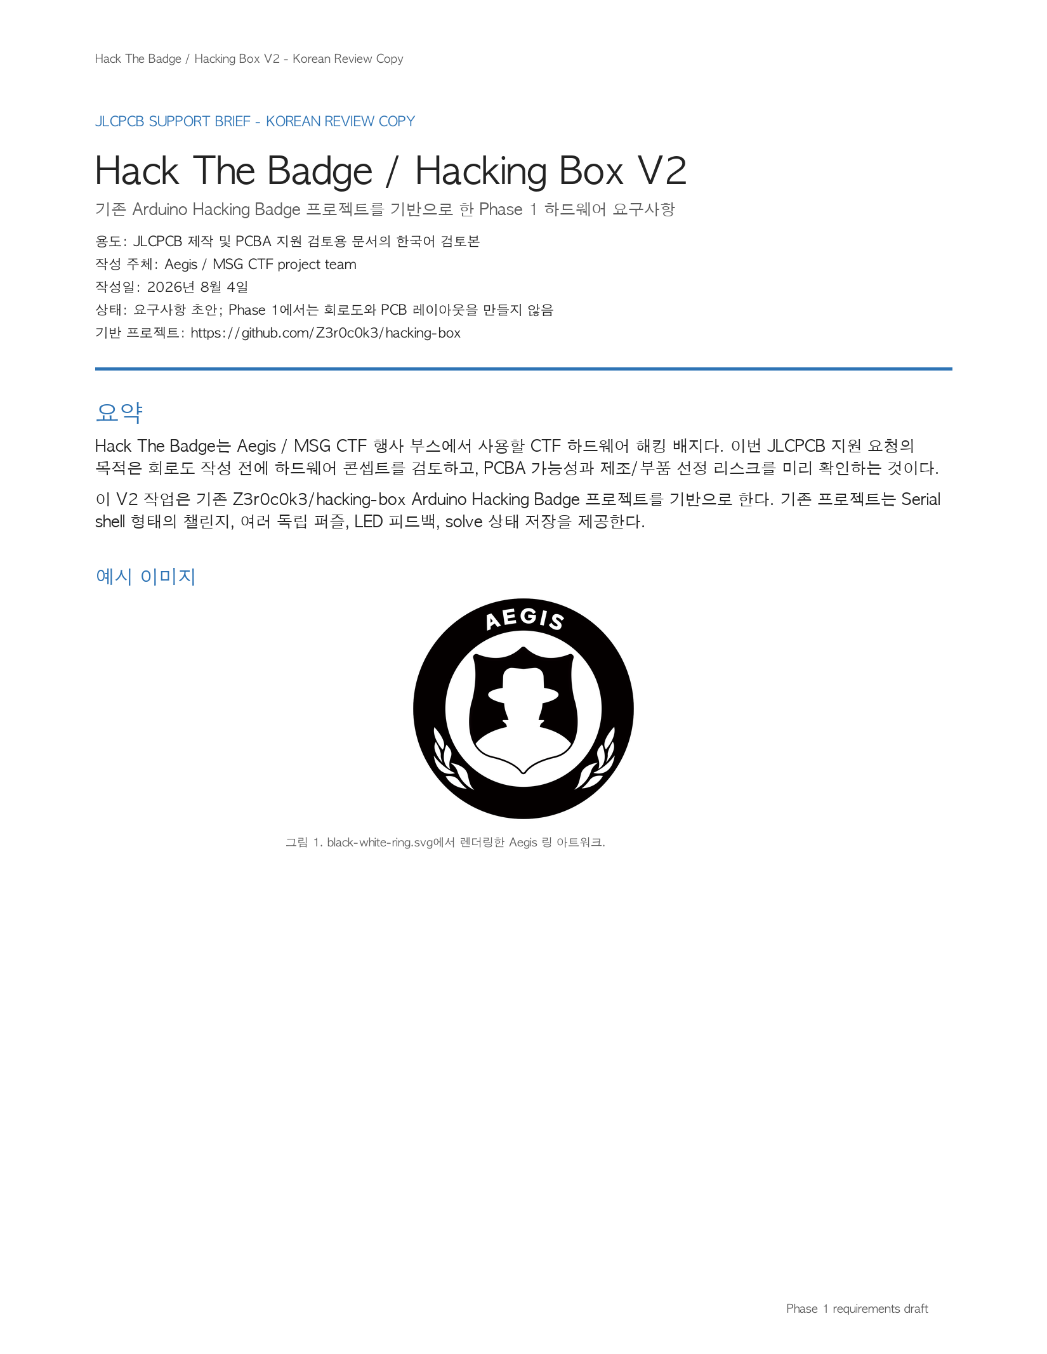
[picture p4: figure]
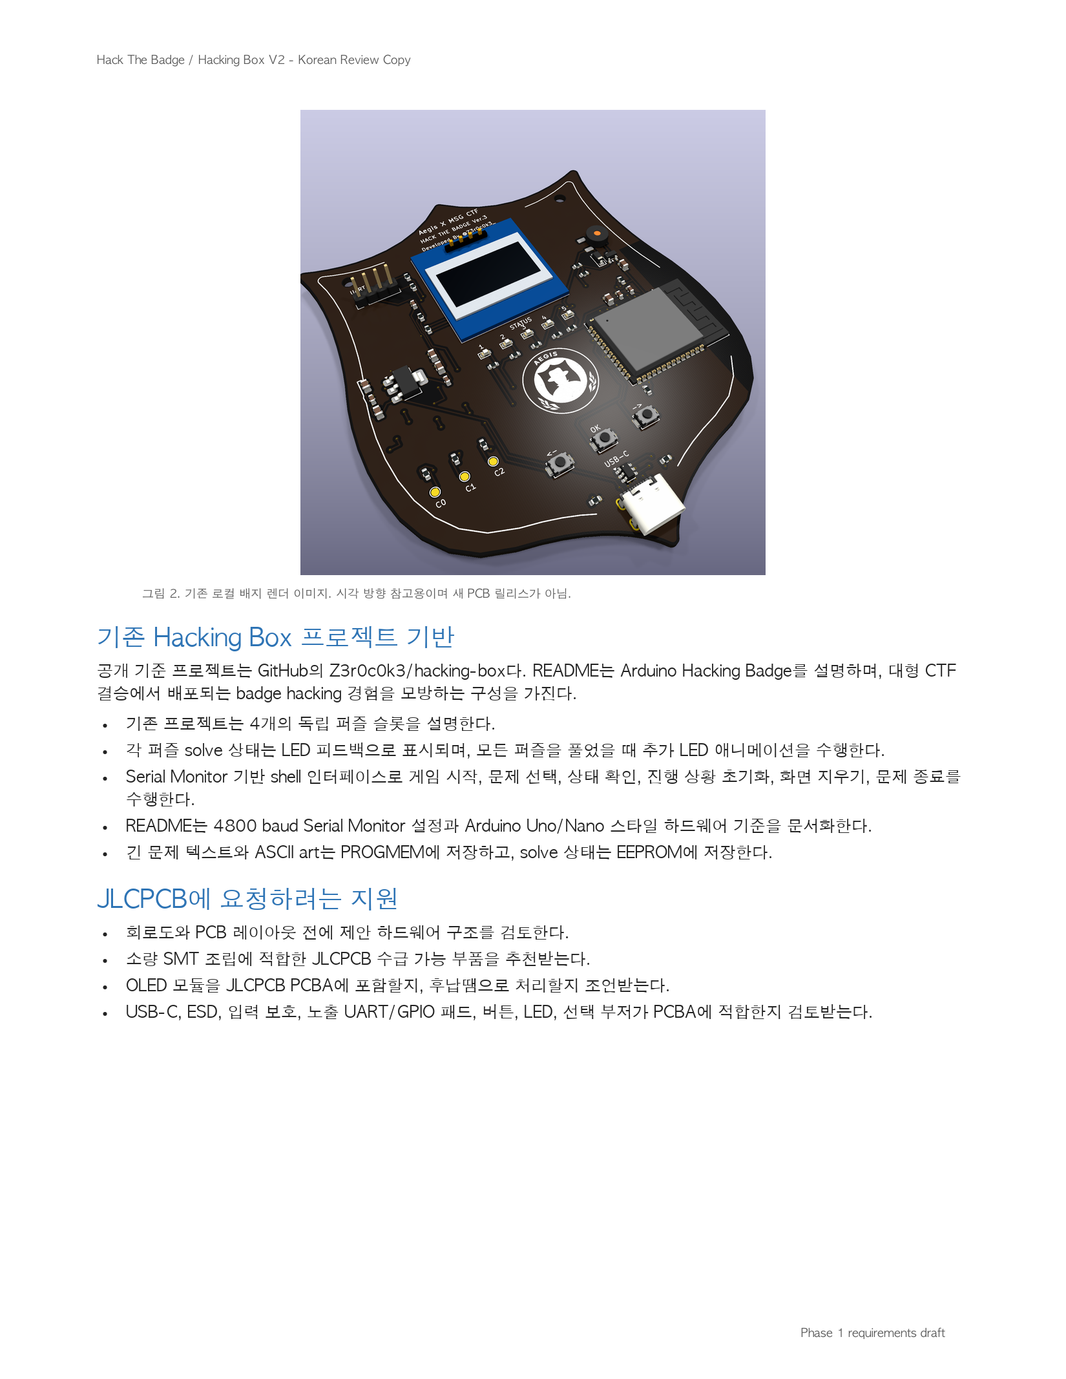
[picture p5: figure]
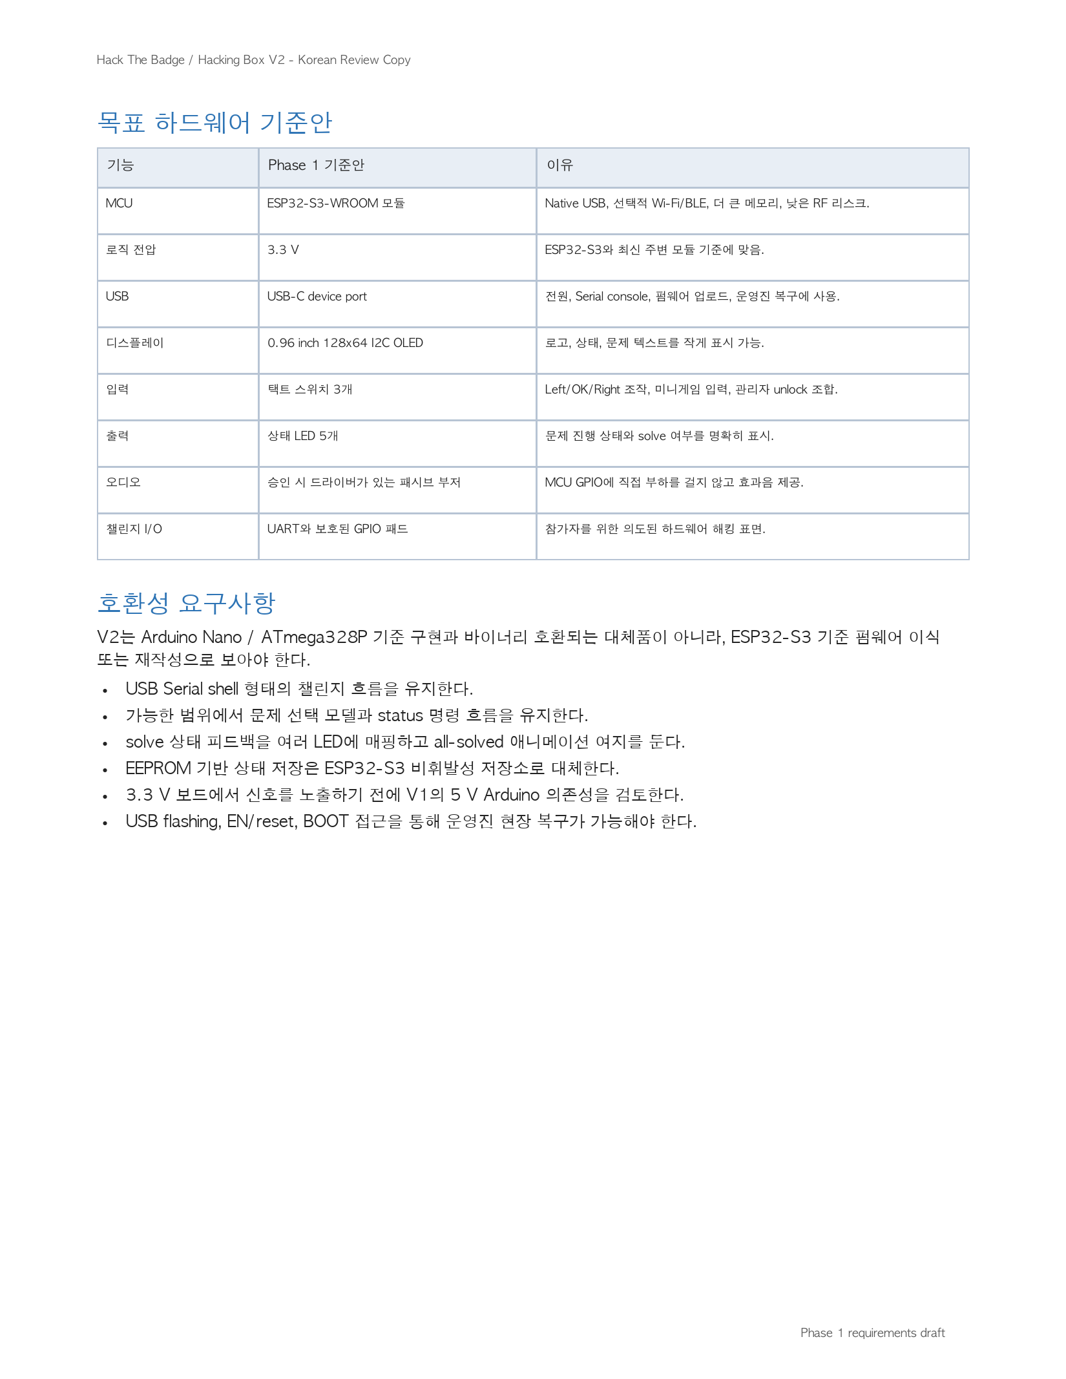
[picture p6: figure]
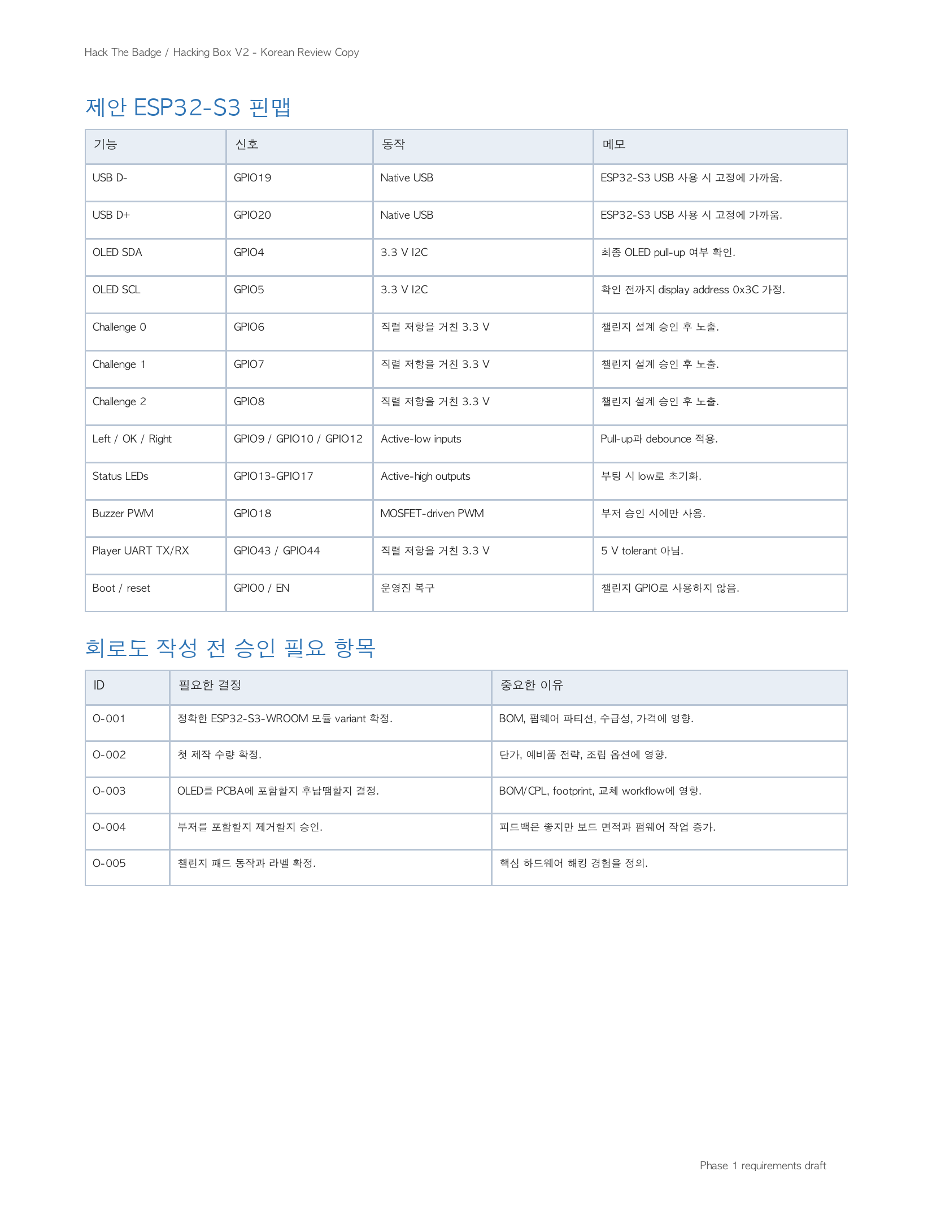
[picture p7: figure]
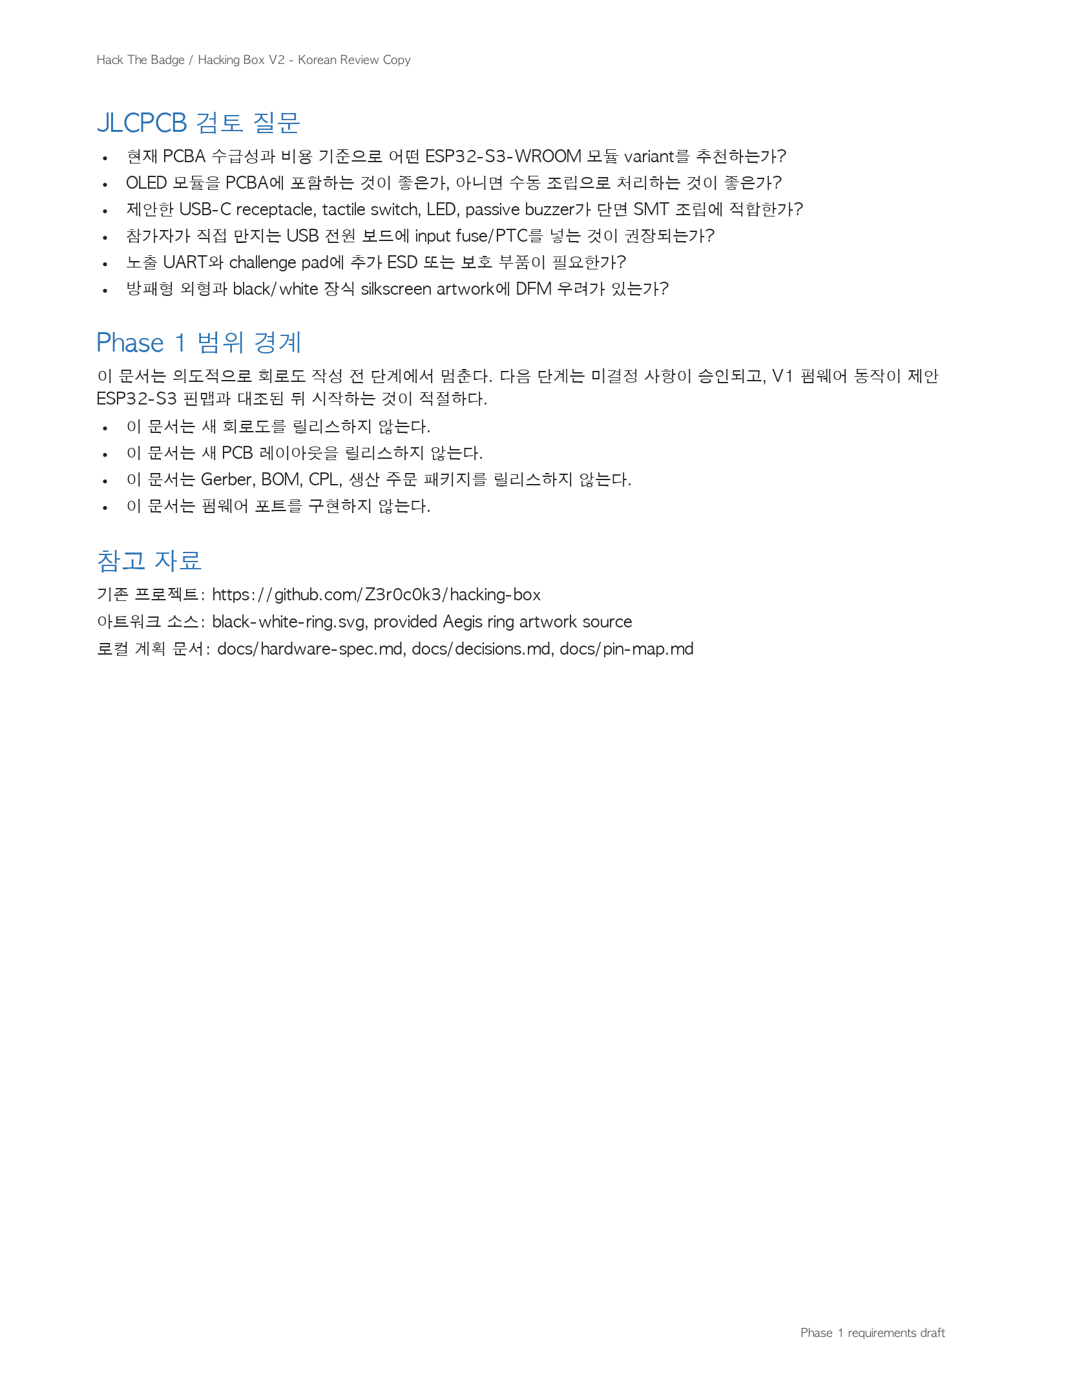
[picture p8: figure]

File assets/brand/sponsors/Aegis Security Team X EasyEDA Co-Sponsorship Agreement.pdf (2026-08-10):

## Co-Sponsorship Agreement

Party B’s Institution Name: __________________________________________

Party B’s Address: __________________________________________________

Contact Email: _____________________________________________________

Campaign Project: __________________________________________________

Campaign Period: _________________________________________________

Party A: EasyEDA

Party A’s Address: Futian District, Shenzhen, Guangdong, China

Contact Email: dom@easyeda.com

Party A agrees to provide sponsorship for Party B's campaign project as stated above, in accordance

with the terms and conditions set forth herein.

The specific amount of sponsorship will be evaluated based on the innovation, difficulty,

and practical significance of the project (a schematic diagram and PCB design are

required).

The sponsorship will be in the form of PCB coupons; no cash support will be provided.

## 1. Sponsorship Description

## 3. TERM

## 5. PartyB’s Obligations

## 4. PartyA's Obligations

## 2. CONFIRMATION AND EFFECTIVENESS

Provide the PCB design tool EasyEDA to address software usage issues.

Provide 100 USD JLCPCB coupons

The term of the sponsorship is for the duration of the event as stated above, unless otherwise

extended or terminated in writing by mutual agreement.

This Agreement shall become effective upon receipt of a written confirmation from Party B

through WhatsApp or email, acknowledging acceptance of the terms outlined herein. The lack of

a physical signature shall not affect the validity and enforce ability of this Agreement.

PCB Silkscreen Logo: Add both the EasyEDA and JLCPCB logos on the PCB badge silkscreen

layer.

GitHub README: Add our logos to your GitHub project's README.md file along with

hyperlinks to our official websites.

Photos & Event Feedback: Share high-resolution photos of the physical PCB badges and

around 10 event photos with us, authorizing us to use them for social media promotion.

OSHWLab Article Post: After the event, write and publish a recap article in the Article section

on OSHWLab.

7.

## 6. Notes

## INTELLECTUAL PROPERTY

## 8. Liability for Breach of Contract

## 9. GOVERNING LAW AND DISPUTE RESOLUTION

1. Party B will promote EasyEDA as a sponsor but retains the right to provide honest opinions and

educational comparisons.

2. The team leader confirms that all photos provided have been legally obtained with proper

portrait rights authorization. Should any disputes arise due to authorization defects, the team

leader shall bear all legal responsibilities and compensations.

If Party B fails to fulfill the obligations agreed upon in the contract, and fails to cure such breach

within [ 7 ] days of receiving notice from Party A, Party A has the right to terminate this

Agreement and cancel the sponsorship at any time. In the event of termination due to Party B's

breach, Party A reserves the right to publicize such breach and consider Party B for inclusion in its

internal blacklist. Any losses incurred will be borne by Party B. If Party A suffers losses as a result,

Party B shall bear the corresponding compensation liability, provided that Party B's total cumulative

liability under this Agreement shall not exceed USD 100 (the total value of the sponsorship coupon),

except in cases of fraud or willful misconduct. It is expressly agreed that the team leader signs solely

as an authorized representative of Party B and shall bear no personal liability.

This Agreement shall be governed by and construed in accordance with the laws of the People's

Republic of China. Any matters not covered in this contract or any disputes arising during the

All intellectual property rights related to Party A's software, branding, logos, documents, or

materials provided shall remain the property of Party A. Party B is granted a limited, non-exclusive,

non-transferable license to use such intellectual properties solely for the purpose of this

sponsorship.

performance of this contract shall be resolved through friendly negotiation between the two parties.

If negotiation fails, both parties agree to submit the case to the jurisdiction of the People's Court in

the location of Party A.

This Agreement constitutes the entire understanding between the parties and supersedes all prior

negotiations, understandings, and agreements between them. This Agreement may only be

amended in writing form like WhatsApp or email by both parties.

## 10. ENTIRE AGREEMENT

This Agreement will take effect after Party B replies and confirms.

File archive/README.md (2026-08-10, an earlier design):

# Archive

현재 생산에 사용하지 않는 개발 기록과 제조사 견적을 보관합니다.

- `design/rev3-development/`: 과거 PCB 리비전, autorouter 세션, 구조 복구
  파일, 구형 렌더와 검사 보고서
- `manufacturing/rev3/nextpcb-quote-20260802/`: 2026-08-02 NextPCB 견적용
  BOM과 Centroid 출력

최종 주문에는 이 폴더의 파일을 사용하지 않습니다. 현재 JLCPCB 릴리스는
`hardware/releases/rev3/jlcpcb/`에 있습니다.

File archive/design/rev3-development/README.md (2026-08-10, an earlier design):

# Rev.3 Development Archive

현재 생산에 사용하지 않는 Rev.3 개발 중간 산출물입니다.

- `pcb-revisions/`: 날짜와 작업 단계별 PCB 스냅샷
- `autoroute/`: Specctra DSN/SES와 중간 DRC 보고서
- `placement/`: 초기 배치 및 centroid 초안
- `legacy-exports/`: 구형 렌더와 3D 출력
- `legacy-reports/`: 과거 DRC 보고서
- `legacy-schematic/`, `rescue-backup/`: KiCad 구조 복구 자료
- `kicad-history/`: KiCad 내부 history의 마지막 작업 트리
- `kicad-history.bundle`: 중첩 저장소를 제거하기 전에 보존한 전체 Git 이력

이력 복원 예시:

```sh
git clone kicad-history.bundle restored-kicad-history
```

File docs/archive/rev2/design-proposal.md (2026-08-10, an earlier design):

# Hacking Box V2-A Design Proposal

> Historical proposal: superseded by the ESP32-S3 Hacking Badge Ver.3
> production files in `hardware/releases/rev3/jlcpcb/`. Do not use the tentative
> GPIO, regulator, or buzzer-DNP entries below for fabrication or firmware.

Status: Pre-schematic design proposal. No schematic or PCB file has been
created.

## Goal

Design a small assembled booth board for the MSG CTF finals Aegis experience
zone. The board should support the "badge hacking" concept, show Aegis branding
on a small display or PCB artwork, and be practical to build as about 10 units
through JLCPCB assembly.

## Recommended Baseline

V2-A should move from an Arduino Nano-compatible ATmega328P design to an
ESP32-S3-WROOM module based design.

Rationale:

- More SRAM and CPU headroom for display UI and challenge logic.
- Native USB Serial/JTAG on `GPIO19` and `GPIO20`, reducing the need for a
  separate USB-to-serial bridge.
- Wi-Fi/BLE can support booth reset, scoring, hints, or hidden challenge paths.
- A module reduces RF layout risk compared with a bare ESP32-S3 chip.
- For 10 assembled boards, the ESP32-S3 module cost is noticeable but feasible
  if the design actually uses USB, display, and/or wireless features.

The fallback architecture is RP2350 if wireless is not useful. ATmega328P should
remain a compatibility reference for the old Hacking-Box firmware, not the
preferred V2-A target.

## Proposed Feature Set

| Feature | V2-A Proposal | Notes |
| --- | --- | --- |
| MCU | ESP32-S3-WROOM module | Prefer JLCPCB/LCSC stocked module variant. |
| Logic voltage | 3.3 V | Native for ESP32-S3 and most modern displays. |
| USB | USB-C device port | Power, firmware upload, serial console, and staff recovery. |
| Display | 128x64 I2C OLED connector or module footprint | Start with logo/status UI; avoid color TFT in first spin. |
| User input | 2-3 tactile buttons | Menu/action/reset-like challenge interactions. |
| Status output | 3-5 challenge status LEDs plus optional RGB LED | Show problem progress, solve state, and booth-visible feedback. |
| Audio | Optional small buzzer footprint | Useful for feedback; can be DNP if budget/space is tight. |
| Player interface | USB Serial plus exposed UART pads | Player-facing access should stay wired and challenge-scoped. |
| Admin interface | Wi-Fi/BLE management channel | Staff-only status, reset, provisioning, and event control. |
| Challenge pads | Exposed labeled UART/GPIO/test pads | Intentional hacking surface with series resistors where useful. |
| Recovery | USB boot/reflash plus EN and BOOT buttons/pads | Staff must be able to recover boards quickly. |
| Artwork | Aegis shield outline plus `Aegis x MSG CTF` | Black solder mask with white silkscreen as the first-spin visual direction. |
| Power | USB 5 V input to 3.3 V regulator | Battery is not included in V2-A unless separately approved. |

## Block Diagram

```mermaid
flowchart LR
  USB["USB-C\npower + native USB"] --> ESD["USB ESD\nand CC resistors"]
  ESD --> ESP["ESP32-S3-WROOM\nmodule"]
  USB --> REG["3.3 V regulator"]
  REG --> ESP
  REG --> OLED["I2C OLED\nlogo/status"]
  ESP --> OLED
  ESP --> BTN["Buttons"]
  ESP --> LED["3-5 status LEDs\noptional RGB"]
  ESP --> BUZ["Optional buzzer"]
  ESP --> PAD["Player access\nUSB Serial + UART"]
  ESP --> ADM["Admin access\nWi-Fi / BLE"]
  ESP --> ART["Aegis x MSG CTF\nPCB artwork"]
```

## Board Concept

- Aegis shield-inspired board outline, roughly palm size.
- Black solder mask and white silkscreen are the target visual stackup.
- Top side: OLED near upper center, Aegis logo/artwork visible, buttons reachable
  with one hand.
- USB-C on an edge with enough mechanical clearance for repeated cable use.
- ESP32-S3-WROOM placed near a board edge with antenna keep-out respected.
- Challenge pads grouped and labeled clearly enough for participants, but not so
  verbose that the board gives away the solution.
- Staff recovery pads/buttons placed away from the main participant interaction
  area.
- Prefer single-sided SMT assembly for cost control.
- Keep the shield outline manufacturable with straight or gently segmented
  edges; avoid overly detailed logo curves on the first spin.

## Proposed Electrical Architecture

### USB And Power

- USB-C receptacle configured as a USB 2.0 device.
- `VBUS` feeds a 3.3 V regulator.
- USB D- and D+ connect to ESP32-S3 `GPIO19` and `GPIO20`.
- Add USB ESD protection and follow Espressif USB routing guidance.
- Include `EN` reset and `GPIO0` boot access for recovery.

### ESP32-S3 Module

- Use ESP32-S3-WROOM module rather than bare ESP32-S3 chip.
- Avoid assigning normal features to strapping pins unless deliberately designed:
  `GPIO0`, `GPIO3`, `GPIO45`, and `GPIO46`.
- Avoid flash/PSRAM-reserved pins for module variants that use embedded
  flash/PSRAM.
- Respect module antenna keep-out.

### Display

- First-spin recommendation: 128x64 I2C OLED.
- Put the Aegis logo bitmap in firmware assets.
- If using a connector, make it easy to hand-solder the OLED after JLCPCB
  assembly.
- If using an assembled module/part, confirm JLCPCB availability before locking
  the footprint.

### Challenge Interface

- Expose a small set of intentional challenge pads:
  - UART TX/RX or alternate serial challenge port.
  - Several GPIO pads with current-limiting or series resistors.
  - Ground and 3.3 V reference pads.
- Do not expose raw USB, regulator feedback, or fragile module pins as the main
  challenge surface.
- Player-facing firmware should expose only the intended USB Serial and UART
  challenge commands.
- I2C should remain internal by default because the OLED shares that bus; expose
  it only if the challenge explicitly needs I2C.

### Admin Wireless Management

- ESP32-S3 Wi-Fi/BLE can provide a staff-only management path.
- Candidate admin actions:
  - Read board ID, firmware version, power state if available, and current
    challenge state.
  - Reset challenge progress.
  - Put a board into demo, idle, or player mode.
  - Push simple hints/status messages to the OLED.
  - Trigger a staff recovery mode before USB reflashing.
- Keep admin commands separate from the USB Serial/UART command parser.
- Require an admin unlock mechanism, such as a per-board token, shared event
  secret, or physical staff button long-press.
- Prefer disabling or hiding wireless management during active player attempts
  unless the event flow needs live monitoring.
- OTA updates are possible but should not be required for first-spin booth
  recovery; USB recovery should remain available.

## Tentative V2-A Pin Plan

This is not final. It is a starting point for schematic capture after approval.

| Signal | ESP32-S3 GPIO | Purpose | Notes |
| --- | --- | --- | --- |
| `USB_D-` | `GPIO19` | Native USB D- | Fixed by ESP32-S3 USB guidance. |
| `USB_D+` | `GPIO20` | Native USB D+ | Fixed by ESP32-S3 USB guidance. |
| `BOOT` | `GPIO0` | Download boot strap | Button or pad; do not use as challenge GPIO. |
| `EN` | `EN` | Reset/chip enable | Button or pad for staff recovery. |
| `OLED_SDA` | `GPIO4` | I2C display data | 3.3 V pull-ups. |
| `OLED_SCL` | `GPIO5` | I2C display clock | 3.3 V pull-ups. |
| `BTN_A` | `GPIO10` | Deferred user/challenge button | DNP in cost-first first spin unless V1 requires it. |
| `BTN_B` | `GPIO11` | Deferred user/challenge button | DNP in cost-first first spin unless V1 requires it. |
| `STATUS_LED_0` | `GPIO13` | Challenge status LED | Current-limited; stage/progress indicator. |
| `STATUS_LED_1` | `GPIO14` | Challenge status LED | Current-limited; stage/progress indicator. |
| `STATUS_LED_2` | `GPIO15` | Challenge status LED | Current-limited; stage/progress indicator. |
| `STATUS_LED_3` | `GPIO16` | Challenge status LED | Current-limited; stage/progress indicator. |
| `STATUS_LED_4` | `GPIO17` | Challenge status LED | Current-limited; stage/progress indicator. |
| `BUZZER` | `GPIO18` | Deferred PWM output | DNP in cost-first first spin. |
| `CHAL_0` | `GPIO6` | Challenge pad | Add 1 kOhm series resistor. |
| `CHAL_1` | `GPIO7` | Challenge pad | Add 1 kOhm series resistor. |
| `CHAL_2` | `GPIO8` | Challenge pad | Add 1 kOhm series resistor. |
| `UART_TX` | `GPIO43` | Player serial TX | Exposed pad through 1 kOhm series resistor. |
| `UART_RX` | `GPIO44` | Player serial RX | Exposed pad through 1 kOhm series resistor. |
| `ADMIN_UNLOCK` | `GPIO12` | Physical admin unlock | Hidden active-low button. |

## Cost Control Rules

- Use single-sided SMT unless the board outline or display forces otherwise.
- Keep unique Extended parts low.
- Prefer JLCPCB Basic resistors/capacitors.
- Consider hand-soldering the display module and any large decorative connector.
- Avoid unnecessary USB-to-serial bridge if native USB is used.
- Avoid battery charging in the first spin unless the event flow requires it.

## Remaining Items Before Final Schematic/PCB Release

- ESP32-S3-WROOM-1-N8R8 (`C2913201`) is the current cost-first controller
  baseline.
- USB-only power is the current first-spin baseline.
- OLED is a hand-soldered 0.96 inch SSD1306-compatible I2C module via 4-pin
  connector/pads.
- Wi-Fi/BLE is staff/admin management only by default.
- Decide challenge pad count and intended solve path.
- Status LED count is approved as 5 indicators.
- Approximate board outline is now a rounder Aegis shield draft; final outline
  still needs review after real footprints are placed.
- Confirm whether the old Hacking-Box firmware will be ported or rewritten.

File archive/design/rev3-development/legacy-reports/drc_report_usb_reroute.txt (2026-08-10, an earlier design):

** Drc report for hacking_box_v2.kicad_pcb **
** Created on 2026-08-02T21:22:35 **
** Report includes: Errors, Warnings, Exclusions **

** Found 45 DRC violations **
[silk_edge_clearance]: Silkscreen clipped by board edge
    Rule: 기판 구성 제약 실크; warning
    @(24.3439 mm, 86.8013 mm): 세그먼트 (Edge.Cuts)
    @(72.7746 mm, 25.8337 mm): 다각형 (B.Silkscreen)
[silk_edge_clearance]: Silkscreen clipped by board edge
    Rule: 기판 구성 제약 실크; warning
    @(56.7933 mm, 104.7603 mm): 세그먼트 (Edge.Cuts)
    @(57.8000 mm, 104.5000 mm): 세그먼트 of J1 on F.Silkscreen
[silk_edge_clearance]: Silkscreen clipped by board edge
    Rule: 기판 구성 제약 실크; warning
    @(58.4273 mm, 106.0771 mm): 세그먼트 (Edge.Cuts)
    @(57.8000 mm, 106.4000 mm): 세그먼트 of J1 on F.Silkscreen
[silk_edge_clearance]: Silkscreen clipped by board edge
    Rule: 기판 구성 제약 실크; warning
    @(66.5665 mm, 106.0733 mm): 세그먼트 (Edge.Cuts)
    @(67.2000 mm, 104.5000 mm): 세그먼트 of J1 on F.Silkscreen
[text_height]: 텍스트 높이가 범위를 벗어남 (보드의 최대 실크 텍스트 높이 제한 최소 높이 0.8000 mm; 실제 0.5800 mm)
    Rule: 보드의 최대 실크 텍스트 높이 제한; warning
    @(30.0000 mm, 83.0000 mm): PCB 텍스트 'C0' (F.Silkscreen)
[text_height]: 텍스트 높이가 범위를 벗어남 (보드의 최대 실크 텍스트 높이 제한 최소 높이 0.8000 mm; 실제 0.5800 mm)
    Rule: 보드의 최대 실크 텍스트 높이 제한; warning
    @(36.0000 mm, 83.0000 mm): PCB 텍스트 'C1' (F.Silkscreen)
[text_height]: 텍스트 높이가 범위를 벗어남 (보드의 최대 실크 텍스트 높이 제한 최소 높이 0.8000 mm; 실제 0.5800 mm)
    Rule: 보드의 최대 실크 텍스트 높이 제한; warning
    @(42.0000 mm, 83.0000 mm): PCB 텍스트 'C2' (F.Silkscreen)
[text_height]: 텍스트 높이가 범위를 벗어남 (보드의 최대 실크 텍스트 높이 제한 최소 높이 0.8000 mm; 실제 0.5800 mm)
    Rule: 보드의 최대 실크 텍스트 높이 제한; warning
    @(52.0000 mm, 55.9000 mm): PCB 텍스트 '1' (F.Silkscreen)
[text_height]: 텍스트 높이가 범위를 벗어남 (보드의 최대 실크 텍스트 높이 제한 최소 높이 0.8000 mm; 실제 0.5800 mm)
    Rule: 보드의 최대 실크 텍스트 높이 제한; warning
    @(57.2500 mm, 55.9000 mm): PCB 텍스트 '2' (F.Silkscreen)
[text_height]: 텍스트 높이가 범위를 벗어남 (보드의 최대 실크 텍스트 높이 제한 최소 높이 0.8000 mm; 실제 0.5800 mm)
    Rule: 보드의 최대 실크 텍스트 높이 제한; warning
    @(62.5000 mm, 55.9000 mm): PCB 텍스트 '3' (F.Silkscreen)
[text_height]: 텍스트 높이가 범위를 벗어남 (보드의 최대 실크 텍스트 높이 제한 최소 높이 0.8000 mm; 실제 0.5800 mm)
    Rule: 보드의 최대 실크 텍스트 높이 제한; warning
    @(67.7500 mm, 55.9000 mm): PCB 텍스트 '4' (F.Silkscreen)
[text_height]: 텍스트 높이가 범위를 벗어남 (보드의 최대 실크 텍스트 높이 제한 최소 높이 0.8000 mm; 실제 0.5800 mm)
    Rule: 보드의 최대 실크 텍스트 높이 제한; warning
    @(73.0000 mm, 55.9000 mm): PCB 텍스트 '5' (F.Silkscreen)
[text_height]: 텍스트 높이가 범위를 벗어남 (보드의 최대 실크 텍스트 높이 제한 최소 높이 0.8000 mm; 실제 0.5800 mm)
    Rule: 보드의 최대 실크 텍스트 높이 제한; warning
    @(62.5000 mm, 23.2000 mm): PCB 텍스트 'Developed By @Z3r0c0k3_' (F.Silkscreen)
[text_height]: 텍스트 높이가 범위를 벗어남 (보드의 최대 실크 텍스트 높이 제한 최소 높이 0.8000 mm; 실제 0.7200 mm)
    Rule: 보드의 최대 실크 텍스트 높이 제한; warning
    @(34.5000 mm, 27.5000 mm): PCB 텍스트 'UART' (F.Silkscreen)
[text_height]: 텍스트 높이가 범위를 벗어남 (보드의 최대 실크 텍스트 높이 제한 최소 높이 0.8000 mm; 실제 0.7200 mm)
    Rule: 보드의 최대 실크 텍스트 높이 제한; warning
    @(62.5000 mm, 54.7000 mm): PCB 텍스트 'STATUS' (F.Silkscreen)
[text_height]: 텍스트 높이가 범위를 벗어남 (보드의 최대 실크 텍스트 높이 제한 최소 높이 0.8000 mm; 실제 0.7200 mm)
    Rule: 보드의 최대 실크 텍스트 높이 제한; warning
    @(62.5000 mm, 91.8000 mm): PCB 텍스트 'USB-C' (F.Silkscreen)
[text_height]: 텍스트 높이가 범위를 벗어남 (보드의 최대 실크 텍스트 높이 제한 최소 높이 0.8000 mm; 실제 0.5400 mm)
    Rule: 보드의 최대 실크 텍스트 높이 제한; warning
    @(28.0000 mm, 54.7000 mm): PCB 텍스트 '3V3' (B.Silkscreen)
[text_height]: 텍스트 높이가 범위를 벗어남 (보드의 최대 실크 텍스트 높이 제한 최소 높이 0.8000 mm; 실제 0.5400 mm)
    Rule: 보드의 최대 실크 텍스트 높이 제한; warning
    @(28.0000 mm, 61.7000 mm): PCB 텍스트 'EN' (B.Silkscreen)
[text_height]: 텍스트 높이가 범위를 벗어남 (보드의 최대 실크 텍스트 높이 제한 최소 높이 0.8000 mm; 실제 0.5400 mm)
    Rule: 보드의 최대 실크 텍스트 높이 제한; warning
    @(28.0000 mm, 68.7000 mm): PCB 텍스트 'RX' (B.Silkscreen)
[text_height]: 텍스트 높이가 범위를 벗어남 (보드의 최대 실크 텍스트 높이 제한 최소 높이 0.8000 mm; 실제 0.5400 mm)
    Rule: 보드의 최대 실크 텍스트 높이 제한; warning
    @(34.0000 mm, 54.7000 mm): PCB 텍스트 'GND' (B.Silkscreen)
[text_height]: 텍스트 높이가 범위를 벗어남 (보드의 최대 실크 텍스트 높이 제한 최소 높이 0.8000 mm; 실제 0.5400 mm)
    Rule: 보드의 최대 실크 텍스트 높이 제한; warning
    @(34.0000 mm, 61.7000 mm): PCB 텍스트 'BOOT' (B.Silkscreen)
[text_height]: 텍스트 높이가 범위를 벗어남 (보드의 최대 실크 텍스트 높이 제한 최소 높이 0.8000 mm; 실제 0.5400 mm)
    Rule: 보드의 최대 실크 텍스트 높이 제한; warning
    @(34.0000 mm, 68.7000 mm): PCB 텍스트 'SCL' (B.Silkscreen)
[text_height]: 텍스트 높이가 범위를 벗어남 (보드의 최대 실크 텍스트 높이 제한 최소 높이 0.8000 mm; 실제 0.5400 mm)
    Rule: 보드의 최대 실크 텍스트 높이 제한; warning
    @(40.0000 mm, 54.7000 mm): PCB 텍스트 '5V' (B.Silkscreen)
[text_height]: 텍스트 높이가 범위를 벗어남 (보드의 최대 실크 텍스트 높이 제한 최소 높이 0.8000 mm; 실제 0.5400 mm)
    Rule: 보드의 최대 실크 텍스트 높이 제한; warning
    @(40.0000 mm, 61.7000 mm): PCB 텍스트 'TX' (B.Silkscreen)
[text_height]: 텍스트 높이가 범위를 벗어남 (보드의 최대 실크 텍스트 높이 제한 최소 높이 0.8000 mm; 실제 0.5400 mm)
    Rule: 보드의 최대 실크 텍스트 높이 제한; warning
    @(40.0000 mm, 68.7000 mm): PCB 텍스트 'SDA' (B.Silkscreen)
[silk_over_copper]: Silkscreen clipped by solder mask
    Local override; warning
    @(27.0073 mm, 51.3192 mm): 세그먼트 (F.Silkscreen)
    @(27.0000 mm, 52.0500 mm): 패드 2 [GND]의 C1 위F.Cu
[silk_over_copper]: Silkscreen clipped by solder mask
    Local override; warning
    @(27.0073 mm, 51.3192 mm): 세그먼트 (F.Silkscreen)
    @(27.0000 mm, 53.9500 mm): 패드 1 [VBUS]의 C1 위F.Cu
[silk_over_copper]: Silkscreen clipped by solder mask
    Local override; warning
    @(26.3802 mm, 53.7190 mm): 세그먼트 (F.Silkscreen)
    @(27.0000 mm, 53.9500 mm): 패드 1 [VBUS]의 C1 위F.Cu
[silk_over_copper]: Silkscreen clipped by solder mask
    Local override; warning
    @(87.3750 mm, 38.8750 mm): 직사각형 of BZ1 on F.Silkscreen
    @(91.9475 mm, 43.2500 mm): 패드 2 [BUZZER_SW]의 BZ1 위F.Cu
[silk_over_copper]: Silkscreen clipped by solder mask
    Local override; warning
    @(87.3750 mm, 38.8750 mm): 직사각형 of BZ1 on F.Silkscreen
    @(88.0525 mm, 43.2500 mm): 패드 1 [3V3]의 BZ1 위F.Cu
[silk_over_copper]: Silkscreen clipped by solder mask
    Local override; warning
    @(87.3750 mm, 38.8750 mm): 직사각형 of BZ1 on F.Silkscreen
    @(88.0525 mm, 39.7500 mm): 패드 3 [<no net>]의 BZ1 위F.Cu
[silk_over_copper]: Silkscreen clipped by solder mask
    Local override; warning
    @(72.7746 mm, 25.8337 mm): 다각형 (B.Silkscreen)
    @(50.8500 mm, 50.9000 mm): OLED1의 NPTH 패드
[silk_over_copper]: Silkscreen clipped by solder mask
    Local override; warning
    @(72.7746 mm, 25.8337 mm): 다각형 (B.Silkscreen)
    @(50.8500 mm, 27.1000 mm): OLED1의 NPTH 패드
[silk_over_copper]: Silkscreen clipped by solder mask
    Local override; warning
    @(72.7746 mm, 25.8337 mm): 다각형 (B.Silkscreen)
    @(58.6900 mm, 27.6400 mm): 1의 PTH 패드[GND]OLED1
[silk_over_copper]: Silkscreen clipped by solder mask
    Local override; warning
    @(72.7746 mm, 25.8337 mm): 다각형 (B.Silkscreen)
    @(74.1500 mm, 27.1000 mm): OLED1의 NPTH 패드
[silk_over_copper]: Silkscreen clipped by solder mask
    Local override; warning
    @(72.7746 mm, 25.8337 mm): 다각형 (B.Silkscreen)
    @(74.1500 mm, 50.9000 mm): OLED1의 NPTH 패드
[silk_over_copper]: Silkscreen clipped by solder mask
    Local override; warning
    @(72.7746 mm, 25.8337 mm): 다각형 (B.Silkscreen)
    @(61.2300 mm, 27.6400 mm): 2의 PTH 패드[3V3]OLED1
[silk_over_copper]: Silkscreen clipped by solder mask
    Local override; warning
    @(72.7746 mm, 25.8337 mm): 다각형 (B.Silkscreen)
    @(63.7700 mm, 27.6400 mm): 3의 PTH 패드[OLED_SCL]OLED1
[silk_over_copper]: Silkscreen clipped by solder mask
    Local override; warning
    @(72.7746 mm, 25.8337 mm): 다각형 (B.Silkscreen)
    @(66.3100 mm, 27.6400 mm): 4의 PTH 패드[OLED_SDA]OLED1
[silk_over_copper]: Silkscreen clipped by solder mask
    Local override; warning
    @(72.7746 mm, 25.8337 mm): 다각형 (B.Silkscreen)
    @(59.6100 mm, 99.9000 mm): J1의 NPTH 패드
[silk_over_copper]: Silkscreen clipped by solder mask
    Local override; warning
    @(72.7746 mm, 25.8337 mm): 다각형 (B.Silkscreen)
    @(58.1800 mm, 99.3700 mm): SH의 PTH 패드[GND]J1
[silk_over_copper]: Silkscreen clipped by solder mask
    Local override; warning
    @(72.7746 mm, 25.8337 mm): 다각형 (B.Silkscreen)
    @(58.1800 mm, 103.5500 mm): SH의 PTH 패드[GND]J1
[silk_over_copper]: Silkscreen clipped by solder mask
    Local override; warning
    @(72.7746 mm, 25.8337 mm): 다각형 (B.Silkscreen)
    @(65.3900 mm, 99.9000 mm): J1의 NPTH 패드
[silk_over_copper]: Silkscreen clipped by solder mask
    Local override; warning
    @(72.7746 mm, 25.8337 mm): 다각형 (B.Silkscreen)
    @(66.8200 mm, 99.3700 mm): SH의 PTH 패드[GND]J1
[silk_over_copper]: Silkscreen clipped by solder mask
    Local override; warning
    @(72.7746 mm, 25.8337 mm): 다각형 (B.Silkscreen)
    @(66.8200 mm, 103.5500 mm): SH의 PTH 패드[GND]J1

** Found 0 unconnected pads **

** Found 0 Footprint errors **

** Ignored checks **
    - Footprint has no courtyard defined
    - Track endpoint not centered on via
    - Tuning profile track geometries
    - Footprint doesn't match symbol's footprint filters
    - Footprint component type doesn't match footprint pads

** End of Report **

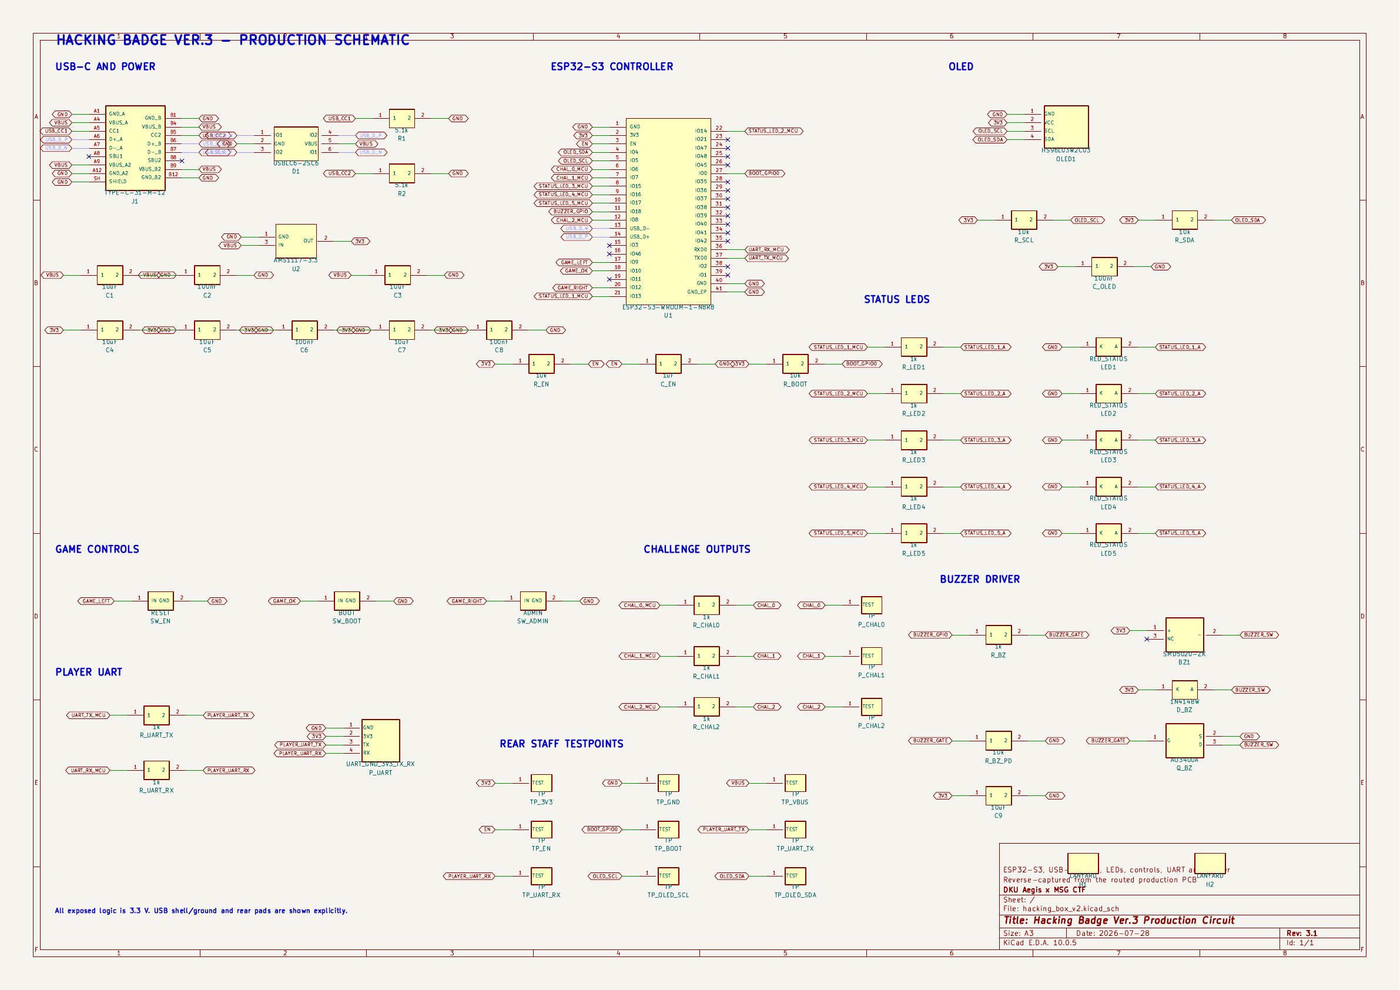
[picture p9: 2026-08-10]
hardware/design/rev3/kicad/exports/hacking_box_v2_schematic.png

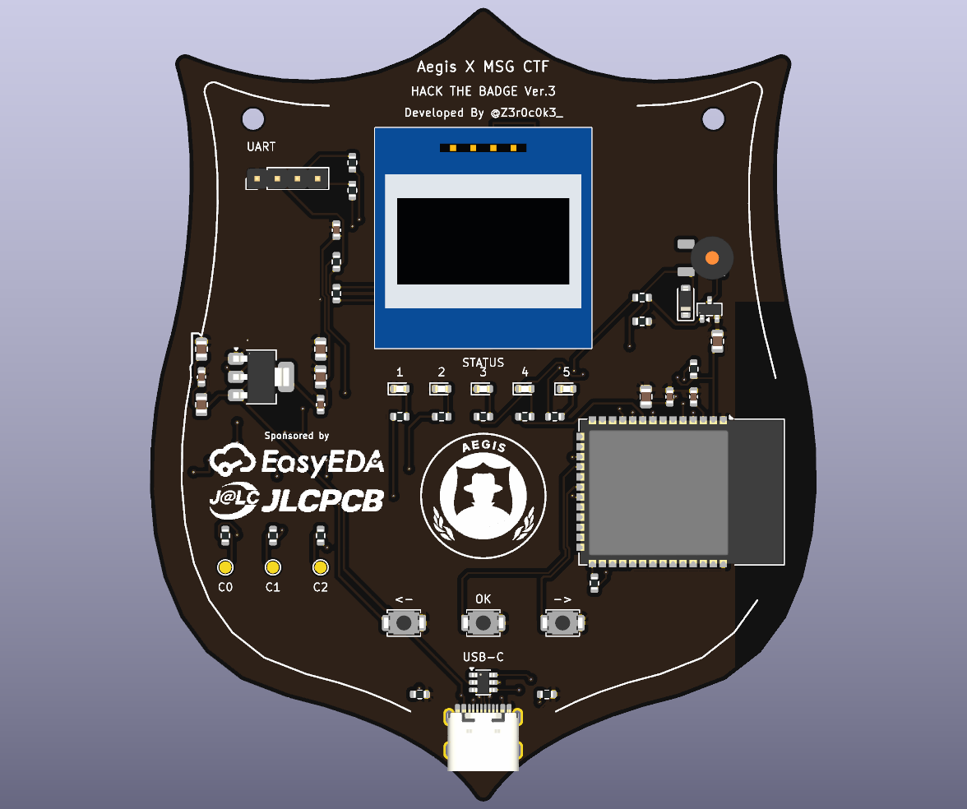
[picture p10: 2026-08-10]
hardware/releases/rev3/jlcpcb/preview/final_preview_top.png

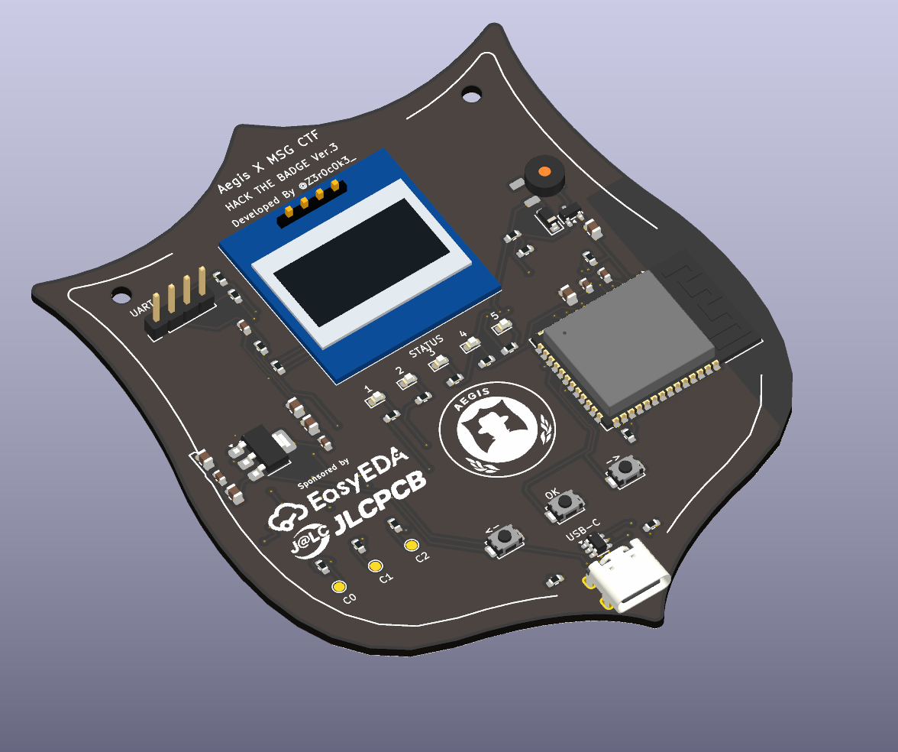
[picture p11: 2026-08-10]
hardware/releases/rev3/jlcpcb/preview/final_preview_iso.png

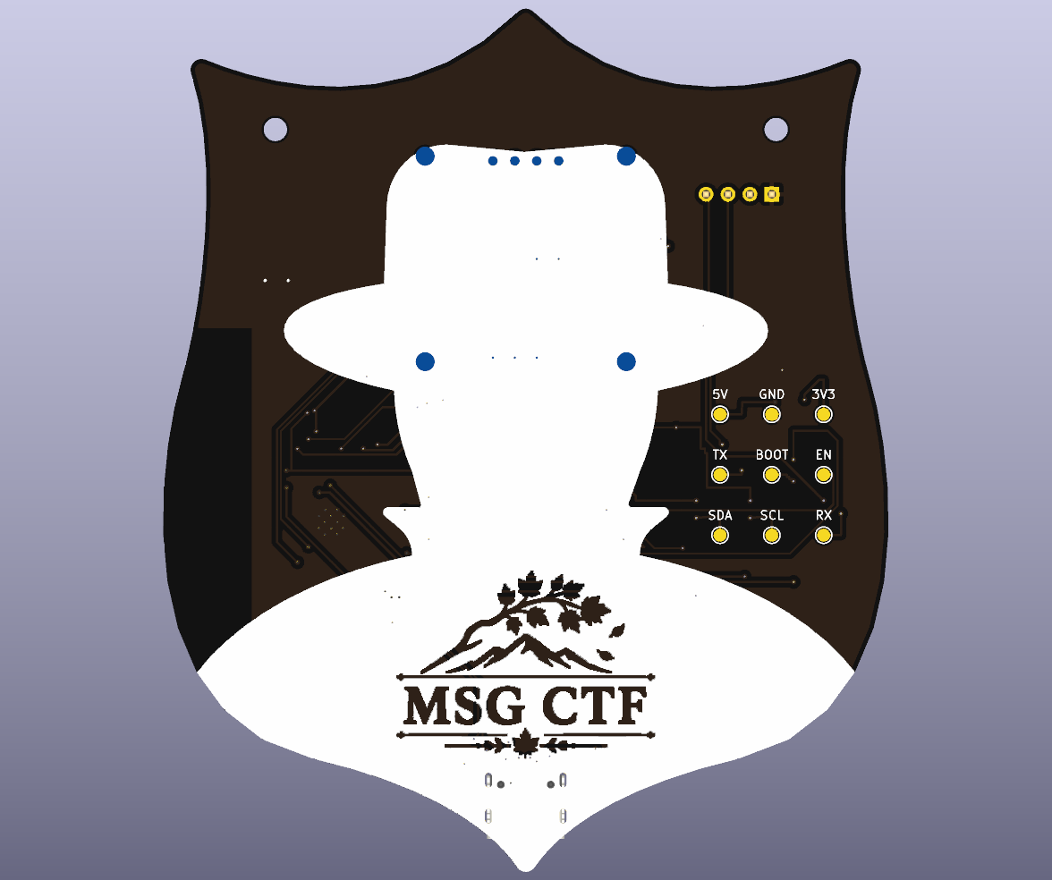
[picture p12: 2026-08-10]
hardware/releases/rev3/jlcpcb/preview/final_preview_bottom.png

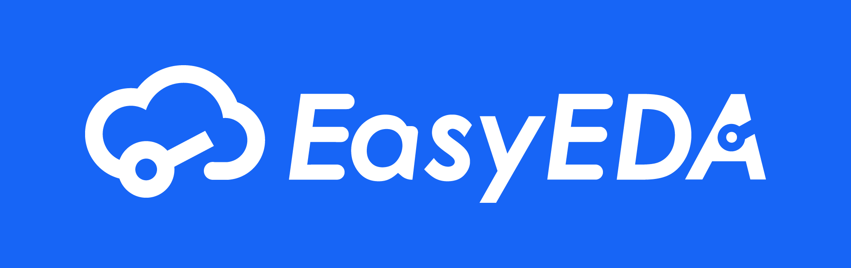
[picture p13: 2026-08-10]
assets/brand/sponsors/official-kit/easyeda/EasyEDA_Horz_W_BlueBG.png

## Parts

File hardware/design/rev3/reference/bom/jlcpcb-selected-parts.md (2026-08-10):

# JLCPCB Selected Parts

Status: Revision 3 production BOM baseline. Recheck stock in the live quote.

| Function | Selected part | LCSC part | Assembly |
| --- | --- | --- | --- |
| MCU/radio | ESP32-S3-WROOM-1-N8R8 | C2913201 | JLCPCB SMT |
| USB-C | TYPE-C-31-M-12 | C165948 | JLCPCB SMT |
| USB ESD | USBLC6-2SC6 | C2827654 | JLCPCB SMT |
| 3.3 V regulator | AMS1117-3.3 | C6186 | JLCPCB SMT |
| Passive buzzer | SMD5020-ZK | C49246955 | JLCPCB SMT |
| Buzzer MOSFET | AO3400A | C20917 | JLCPCB SMT |
| Flyback diode | 1N4148W | C917030 | JLCPCB SMT |
| Status LED | KT-0603R red | C2286 | JLCPCB SMT |
| Tactile switch | TS-1088-AR02016 | C720477 | JLCPCB SMT |
| 5.1 kohm 0603 | 0603WAF5101T5E | C23186 | JLCPCB SMT |
| 10 kohm 0603 | 0603WAF1002T5E | C25804 | JLCPCB SMT |
| 1 kohm 0603 | 0603WAF1001T5E | C21190 | JLCPCB SMT |
| 10 uF 0805 | CL21A106KAYNNNE | C15850 | JLCPCB SMT |
| 100 nF 0603 | CC0603KRX7R9BB104 | C14663 | JLCPCB SMT |
| 1 uF 0603 | CL10A105KB8NNNC | C15849 | JLCPCB SMT |

The production upload BOM is
`hardware/releases/rev3/jlcpcb/upload/hacking_badge_v3_jlcpcb_bom.csv`.

## Manual Assembly

| Function | Selected part | Source | Assembly |
| --- | --- | --- | --- |
| OLED | HS96L03W2C03, 0.96 inch white SSD1315 I2C | DeviceMart item 15963242 | Hand solder after PCBA |

Order five modules for five boards; six are recommended to keep one spare.
Use a straight 1x4 2.54 mm male header if the module is supplied without one.
Install from the front with pin order `GND, VCC, SCL, SDA`; VCC is 3.3 V only.

## Button Use

`SW_EN`, `SW_BOOT`, and `SW_ADMIN` are populated as the `<-`, `OK`, and `->`
game controls. Their legacy reference names are retained only to avoid
unnecessary CPL/reference churn.

## Intentionally Not Populated

- Dedicated reset and boot push buttons; use the rear EN/BOOT test pads.
- USB input PTC/fuse.
The buzzer and its driver are populated, not DNP.

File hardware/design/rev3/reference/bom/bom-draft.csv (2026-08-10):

Reference | Quantity | Value | Package | Assembly | LCSC/JLCPCB Part | Status | Notes
U1 | 1 | ESP32-S3-WROOM-1-N8R8 | ESP32-S3-WROOM-1 | JLCPCB | C2913201 | Production | Keep antenna at board edge
U2 | 1 | AMS1117-3.3 | SOT-223 | JLCPCB | C6186 | Production | 3.3 V regulator
J1 | 1 | TYPE-C-31-M-12 | USB-C 16P | JLCPCB | C165948 | Production | USB2 device port
D1 | 1 | USBLC6-2SC6 | SOT-23-6 | JLCPCB | C2827654 | Production | USB D+/D- ESD
BZ1 | 1 | SMD5020-ZK | SMD 5.3x5.3mm | JLCPCB | C49246955 | Production | 3 V passive buzzer
Q_BZ | 1 | AO3400A | SOT-23 | JLCPCB | C20917 | Production | Buzzer low-side MOSFET
D_BZ | 1 | 1N4148W | SOD-123 | JLCPCB | C917030 | Production | Buzzer flyback diode
C1 C3 C4 C5 C7 C9 | 6 | 10uF | 0805 | JLCPCB | C15850 | Production | Bulk capacitors
C2 C6 C8 C_OLED | 4 | 100nF | 0603 | JLCPCB | C14663 | Production | Decoupling capacitors
C_EN | 1 | 1uF | 0603 | JLCPCB | C15849 | Production | EN timing capacitor
R1 R2 | 2 | 5.1k | 0603 | JLCPCB | C23186 | Production | USB-C CC pulldowns
R_BOOT R_BZ_PD R_EN R_SCL R_SDA | 5 | 10k | 0603 | JLCPCB | C25804 | Production | Pull-up and pulldown resistors
R_BZ R_CHAL0 R_CHAL1 R_CHAL2 R_LED1 R_LED2 R_LED3 R_LED4 R_LED5 R_UART_RX R_UART_TX | 11 | 1k | 0603 | JLCPCB | C21190 | Production | LED and exposed-signal series resistors
LED1 LED2 LED3 LED4 LED5 | 5 | KT-0603R red | LED 0603 | JLCPCB | C2286 | Production | Status indicators
SW_ADMIN SW_BOOT SW_EN | 3 | TS-1088-AR02016 | SMD 4x3mm | JLCPCB | C720477 | Production | Left OK and right game controls
OLED1 | 1 | HS96L03W2C03 0.96in white SSD1315 I2C OLED | 27.3x27.8mm module | Hand solder | DeviceMart 15963242 | Manual | Pin order GND VCC SCL SDA; add straight 1x4 2.54mm header if required

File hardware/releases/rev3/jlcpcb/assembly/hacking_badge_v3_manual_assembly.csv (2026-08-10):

Designator | Qty per board | Qty for 5 boards | Recommended order qty | Part | Supplier | Supplier item | Assembly | Notes
OLED1 | 1 | 5 | 6 | HS96L03W2C03 | DeviceMart | 15963242 | Hand solder | Pin 1 GND, 2 VCC, 3 SCL, 4 SDA; use a straight 1x4 2.54mm male header if the module ships without one

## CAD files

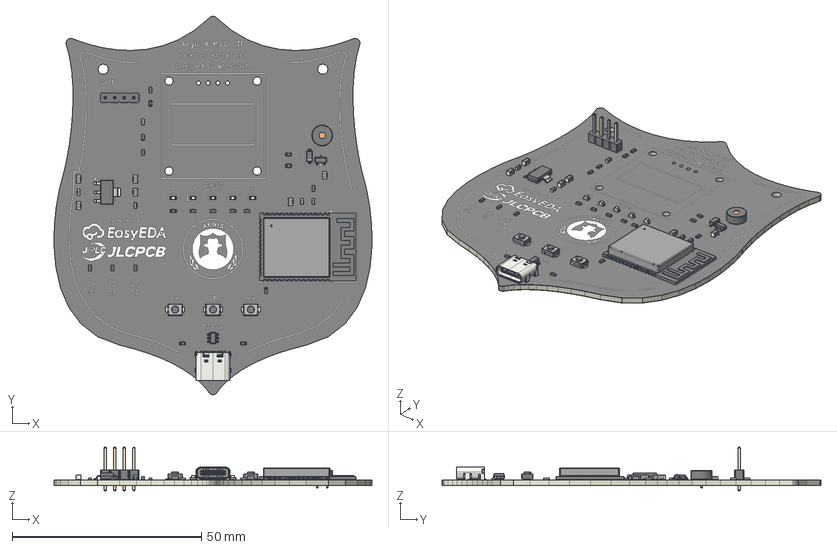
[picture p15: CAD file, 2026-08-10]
hardware/releases/rev3/jlcpcb/assembly/hacking_badge_v3_assembly.step
84.0 x 100.0 x 11.5 mm
PinHeader_1x04_P254mm_Vertical
C_0603_1608Metric x 5
C_0805_2012Metric x 6
SOT-223
R_0603_1608Metric x 18
SW_SPST_TS-1088-xR020 x 3
LED_0603_1608Metric x 5
D_SOD-123
MagneticBuzzer_Kingstate_KCG0601
ESP32-S3-WROOM-1
USB_C_Receptacle_16P_TopMnt_Horizontal_GCT_USB4105-xx-A
SOT-23
SOT-23-6
hacking_box_v2_silkscreen x 2
hacking_box_v2_soldermask x 2
hacking_box_v2_PCB

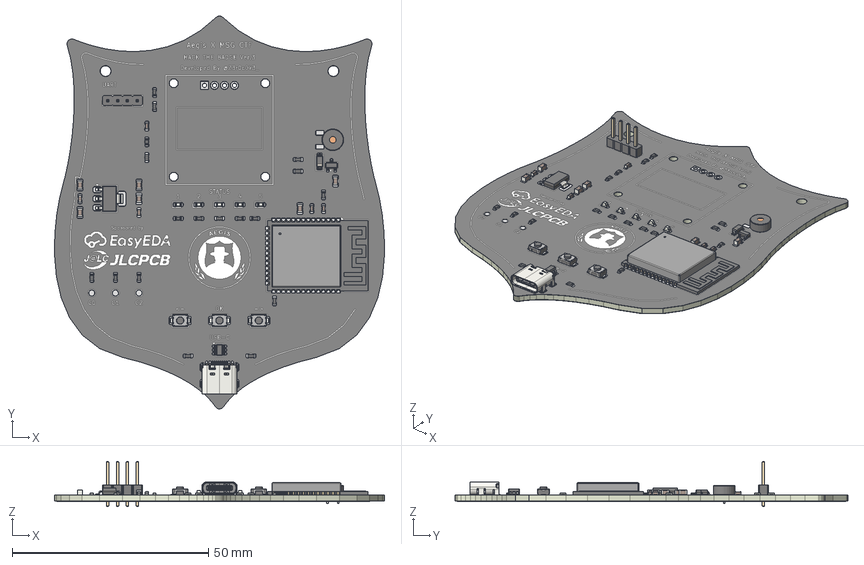
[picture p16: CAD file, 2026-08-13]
hardware/releases/rev3/jlcpcb/preview/3d/hacking_badge_v3_full_assembly.step
84.0 x 100.0 x 11.5 mm
PinHeader_1x04_P254mm_Vertical
C_0603_1608Metric x 5
C_0805_2012Metric x 6
SOT-223
R_0603_1608Metric x 18
SW_SPST_TS-1088-xR020 x 3
LED_0603_1608Metric x 5
D_SOD-123
MagneticBuzzer_Kingstate_KCG0601
ESP32-S3-WROOM-1
USB_C_Receptacle_16P_TopMnt_Horizontal_GCT_USB4105-xx-A
SOT-23
SOT-23-6
hacking_box_v2_copper
hacking_box_v2_pad
hacking_box_v2_via
hacking_box_v2_silkscreen x 2
hacking_box_v2_soldermask x 2
hacking_box_v2_PCB

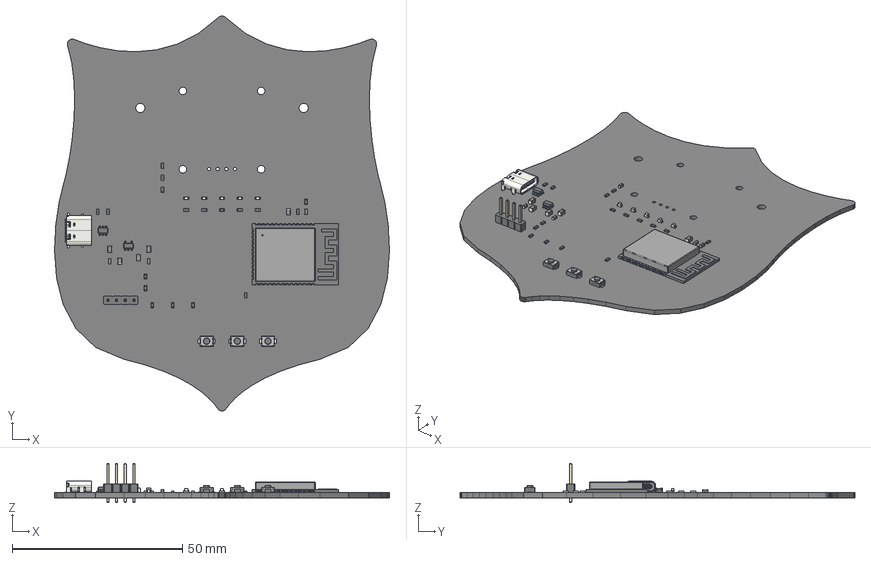
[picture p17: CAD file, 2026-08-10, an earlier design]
archive/design/rev3-development/legacy-exports/hacking_box_v2_assembly_clean.step
98.4 x 116.0 x 11.5 mm
PinHeader_1x04_P254mm_Vertical
C_0603_1608Metric x 5
USB_C_Receptacle_16P_TopMnt_Horizontal_GCT_USB4105-xx-A
R_0603_1608Metric x 16
SW_SPST_TS-1088-xR020 x 3
ESP32-S3-WROOM-1
LED_0603_1608Metric x 5
C_0805_2012Metric x 5
SOT-23-5
SOT-23-6
hacking_box_v2_PCB

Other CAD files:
archive/design/rev3-development/legacy-exports/hacking_box_v2_assembly.step

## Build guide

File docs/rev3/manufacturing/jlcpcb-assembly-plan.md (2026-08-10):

# JLCPCB Assembly Plan

Status: Revision 3 production package prepared for a five-board quote.

## Order Settings

| Setting | Value |
| --- | --- |
| Quantity | 5 |
| Layers | 2 |
| Thickness | 1.6 mm |
| Solder mask | Black |
| Silkscreen | White |
| Assembly side | Top |
| OLED | Excluded from PCBA; DeviceMart `HS96L03W2C03` hand-soldered after assembly |

## Upload Files

- PCB: `hardware/releases/rev3/jlcpcb/upload/hacking_badge_v3_jlcpcb_gerbers.zip`
- BOM: `hardware/releases/rev3/jlcpcb/upload/hacking_badge_v3_jlcpcb_bom.csv`
- CPL: `hardware/releases/rev3/jlcpcb/upload/hacking_badge_v3_jlcpcb_cpl.csv`
- Manual parts list: `hardware/releases/rev3/jlcpcb/assembly/hacking_badge_v3_manual_assembly.csv`

## Assembly Scope

JLCPCB places 44 top-side references, including the ESP32-S3 module, USB-C
connector, ESD device, AMS1117 regulator, five LEDs, three game buttons, the
complete buzzer driver, and all passive support parts. `OLED1` is intentionally
excluded from both assembly uploads and is installed manually after PCBA.

## Pre-Order Review

- Confirm all 44 CPL placements are on the top side.
- Inspect USB-C, diodes, LEDs, MOSFET, ESP32-S3, and buttons for rotation/pin-1.
- Confirm `C2913201`, `C165948`, `C2827654`, `C6186`, `C49246955`, `C20917`,
  and `C917030` are available in the live parts picker.
- Confirm `OLED1` does not appear in the JLCPCB BOM, CPL, or placement preview.
- Source at least five `HS96L03W2C03` modules locally; six are recommended to
  leave one spare. Add a straight 1x4 2.54 mm male header if it is not supplied.
- Verify the ESP32 antenna end faces the board edge.
- Check black solder mask and white silkscreen in the Gerber preview.
- Confirm the rear logo is intentionally interrupted by solder-mask openings
  around pads and holes.
- Review the final quote before ordering; stock and Extended-part fees change.

## Validation

- Electrical DRC: 0 errors, 0 unconnected.
- Gerber archive: exact 12-file fabrication set.
- Stackup metadata: 2 layers, 1.6 mm.
- Board profile: approximately 84.05 x 100.05 mm.
- BOM/CPL reference match: 44 unique top-side placements.
- Manual assembly list: `OLED1` only, one per board.

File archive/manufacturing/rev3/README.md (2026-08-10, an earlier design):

# Rev.3 Manufacturing Archive

- `nextpcb-quote-20260802/`: 2026-08-02 NextPCB 견적 검토 자료

현재 생산에는 `hardware/releases/rev3/jlcpcb/`를 사용합니다.

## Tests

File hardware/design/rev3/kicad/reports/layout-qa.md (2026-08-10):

# Hacking Badge Ver.3 Design QA

Date: 2026-08-02

## PCB Status

- Aegis shield outline: approximately 84.05 x 100.05 mm.
- Stackup: two copper layers, 1.6 mm FR-4.
- Footprints: 60 total, 51 front and 9 rear.
- Routed tracks/vias: 577 board track items.
- Copper zones: 11.
- KiCad error-level DRC: 0 violations.
- Unconnected board items: 0.
- ESP32 antenna keep-out: implemented at the right board edge.
- OLED: `HS96L03W2C03`, four-pin `GND, VCC, SCL, SDA` module; datasheet body
  and mounting pattern retained, with 2.0 mm/1.1 mm hand-solder header pads.
- Production exports: Gerbers, drill, BOM, and CPL validated in
  `hardware/releases/rev3/jlcpcb/`.
- JLCPCB assembly set: 15 grouped BOM lines and 44 top-side placements.
- Manual assembly set: `OLED1` only, one per board.

## Schematic Status

- Connected A3 KiCad schematic generated from the production PCB.
- Functional blocks: USB/power, controller, OLED, status LEDs, controls,
  challenge outputs, UART, testpoints, and buzzer.
- KiCad ERC: 0 errors, 0 warnings.
- PCB/schematic component references: 60/60, exact match.
- PCB/schematic named nets: 37/37, exact match.
- Connected component-pin pairs: 149, exact match.
- Intentional no-connect pins: 20, exact match.
- PDF render inspected after grid and net-label direction corrections.

## Final DRC

- KiCad DRC: 0 errors and 0 unconnected items.
- Remaining source warnings: two intentional clearances from the board-scale
  rear silkscreen logo. Production Gerbers subtract mask openings from silk.
- JLCDFM geometry: 0.20/0.25 mm via drills, 0.20 mm annular rings, 0.80 mm
  plated USB-C slots, and at least 0.15 mm plotted silkscreen strokes.
- Report: `drc_report_jlcdfm_fixes.txt`.

## Workflow Note

The PCB remains the Rev.3 manufacturing source of truth. The schematic is an
electrically exact reverse capture, verified by
`scripts/validate_schematic_against_pcb.py`, but symbol-footprint associations
must be reviewed before pushing schematic changes back into the PCB.

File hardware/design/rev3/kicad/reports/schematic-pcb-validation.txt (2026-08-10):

Hacking Badge V3 schematic-to-PCB validation
================================================
Result: PASS
PCB components: 60
Schematic components: 60
PCB named nets: 37
Schematic named nets: 37
Connected component-pin pairs checked: 149
Intentional no-connect pins checked: 20

Checks
------
Reference set: PASS
Component values: PASS
Named pin-to-net mapping: PASS
Intentional no-connect mapping: PASS

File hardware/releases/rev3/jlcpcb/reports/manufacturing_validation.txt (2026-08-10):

PASS
- Gerber ZIP contains exactly 12 required files.
- Gerber job: 2 layers, 84.05 x 100.05 mm, 1.6 mm thick.
- Board profile Gerber has profile metadata and end marker.
- PTH and NPTH Excellon files contain valid headers/end markers.
- Drill report confirms 0.20 mm minimum drills and four 0.80 mm slots.
- Front and rear plotted silkscreen apertures are at least 0.15 mm.
- Front silkscreen contains the grouped EasyEDA/JLCPCB sponsor mark.
- Final DRC has no electrical, copper, drill, slot, or mask errors.
- J1, U1, U2, D1, and Q_BZ use verified LCSC placement corrections.
- Assembly package: 15 BOM lines, 44 unique top-side placements.
- Manual assembly list contains hand-soldered OLED1.

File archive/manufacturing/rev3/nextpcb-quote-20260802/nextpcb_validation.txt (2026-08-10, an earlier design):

PASS
Board: hardware/kicad/hacking_box_v2/hacking_box_v2.kicad_pcb
BOM rows: 16 total (15 populated groups + 1 OLED DNP)
Assembled designators: 44
Centroid placements: 44
Assembly sides: Top only
BOM/centroid populated designators: exact match
OLED1: BOM DNP; excluded from centroid
Workbook formula errors: none
BOM inspect bytes: 3315
Centroid inspect bytes: 2568
Coordinate units: millimeters
Rotation: degrees counter-clockwise, normalized to 0-359

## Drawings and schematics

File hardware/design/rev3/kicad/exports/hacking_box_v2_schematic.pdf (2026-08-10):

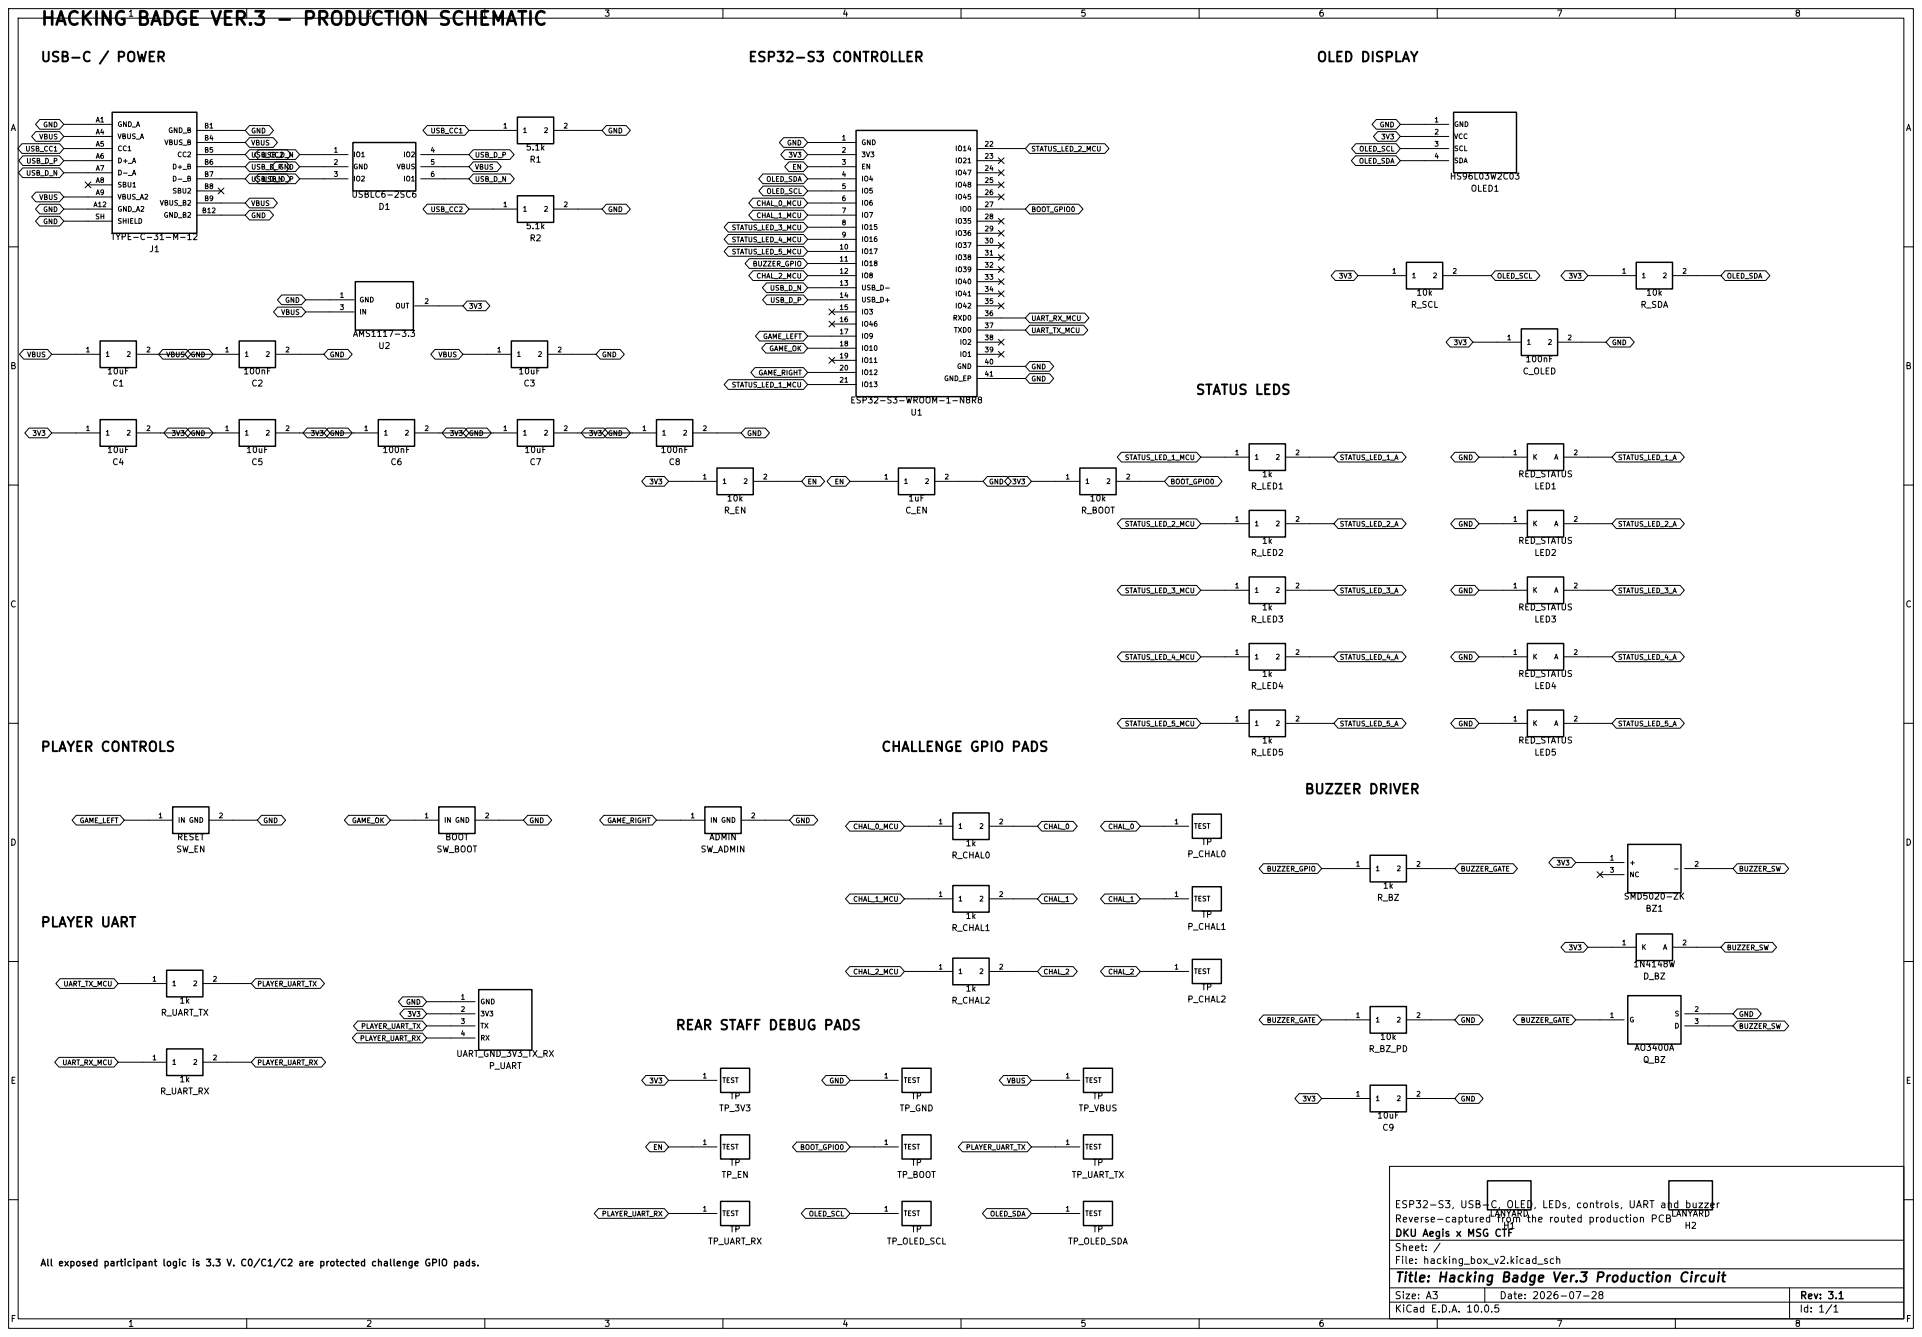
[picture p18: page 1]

HACKING BADGE VER.3 - PRODUCTION SCHEMATIC

ESP32-S3, USB-C, OLED, LEDs, controls, UART and buzzer GND 1
3V3 PLAYER_UART_RX

REAR STAFF DEBUG PADS
BOOT_GPIO0 GND OLED_SCL

Reverse-captured from the routed production PCB
DKU Aegis x MSG CTF
Sheet: /
File: hacking_box_v2.kicad_sch
Title: Hacking Badge Ver.3 Production Circuit

All exposed participant logic is 3.3 V. C0/C1/C2 are protected challenge GPIO pads.

Size: A3 | Rev: 3.1 | F Date: 2026-07-28
KiCad E.D.A. 10.0.5 | Id: 1/1

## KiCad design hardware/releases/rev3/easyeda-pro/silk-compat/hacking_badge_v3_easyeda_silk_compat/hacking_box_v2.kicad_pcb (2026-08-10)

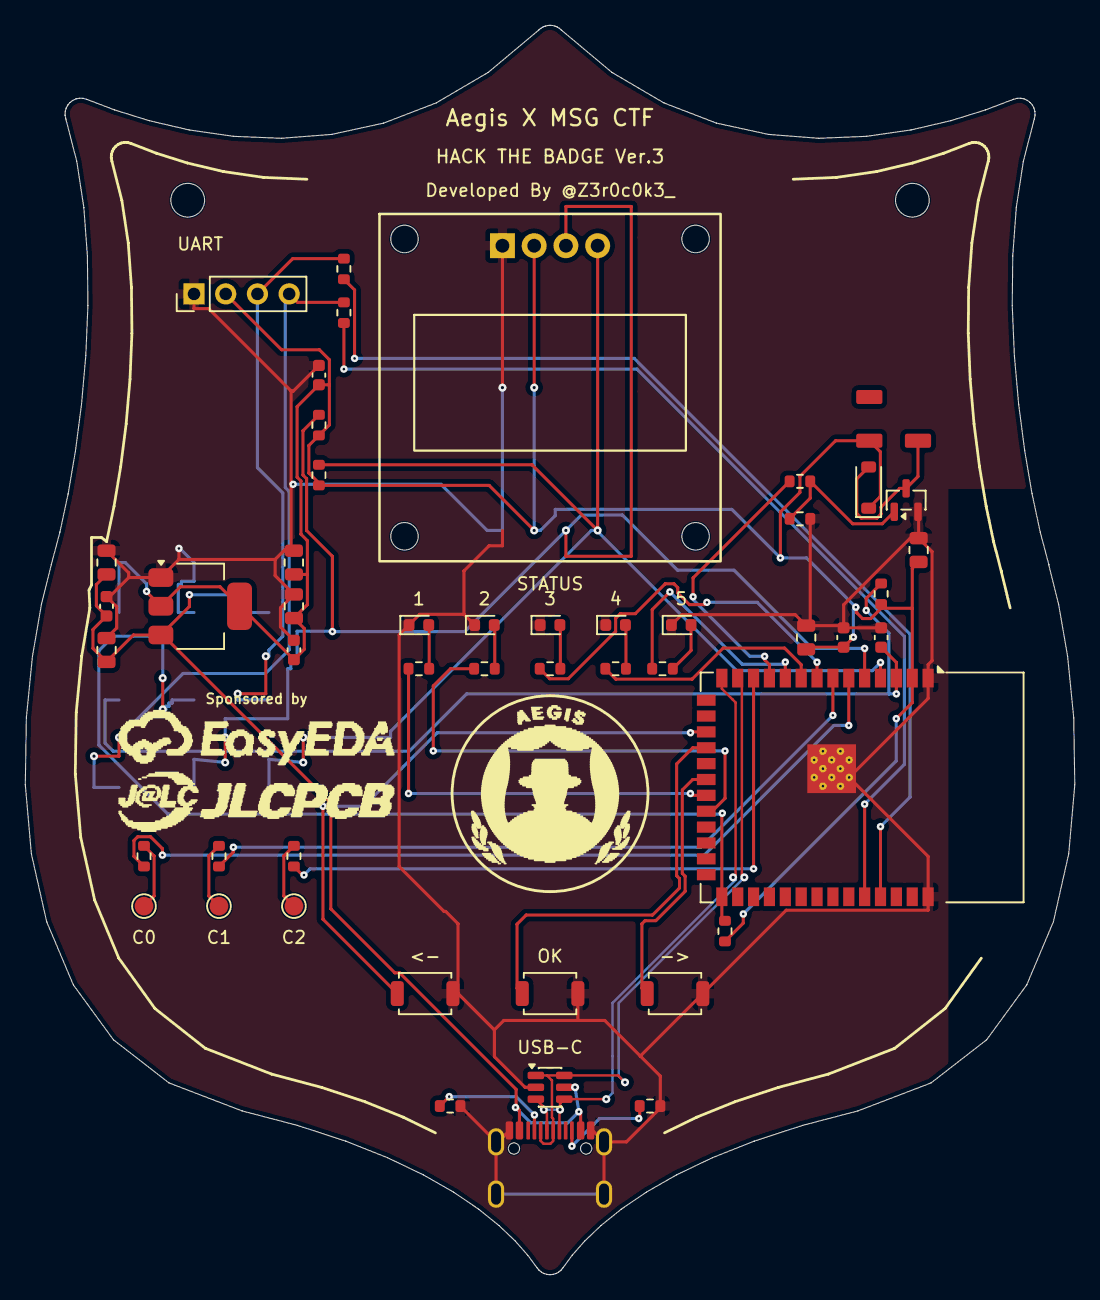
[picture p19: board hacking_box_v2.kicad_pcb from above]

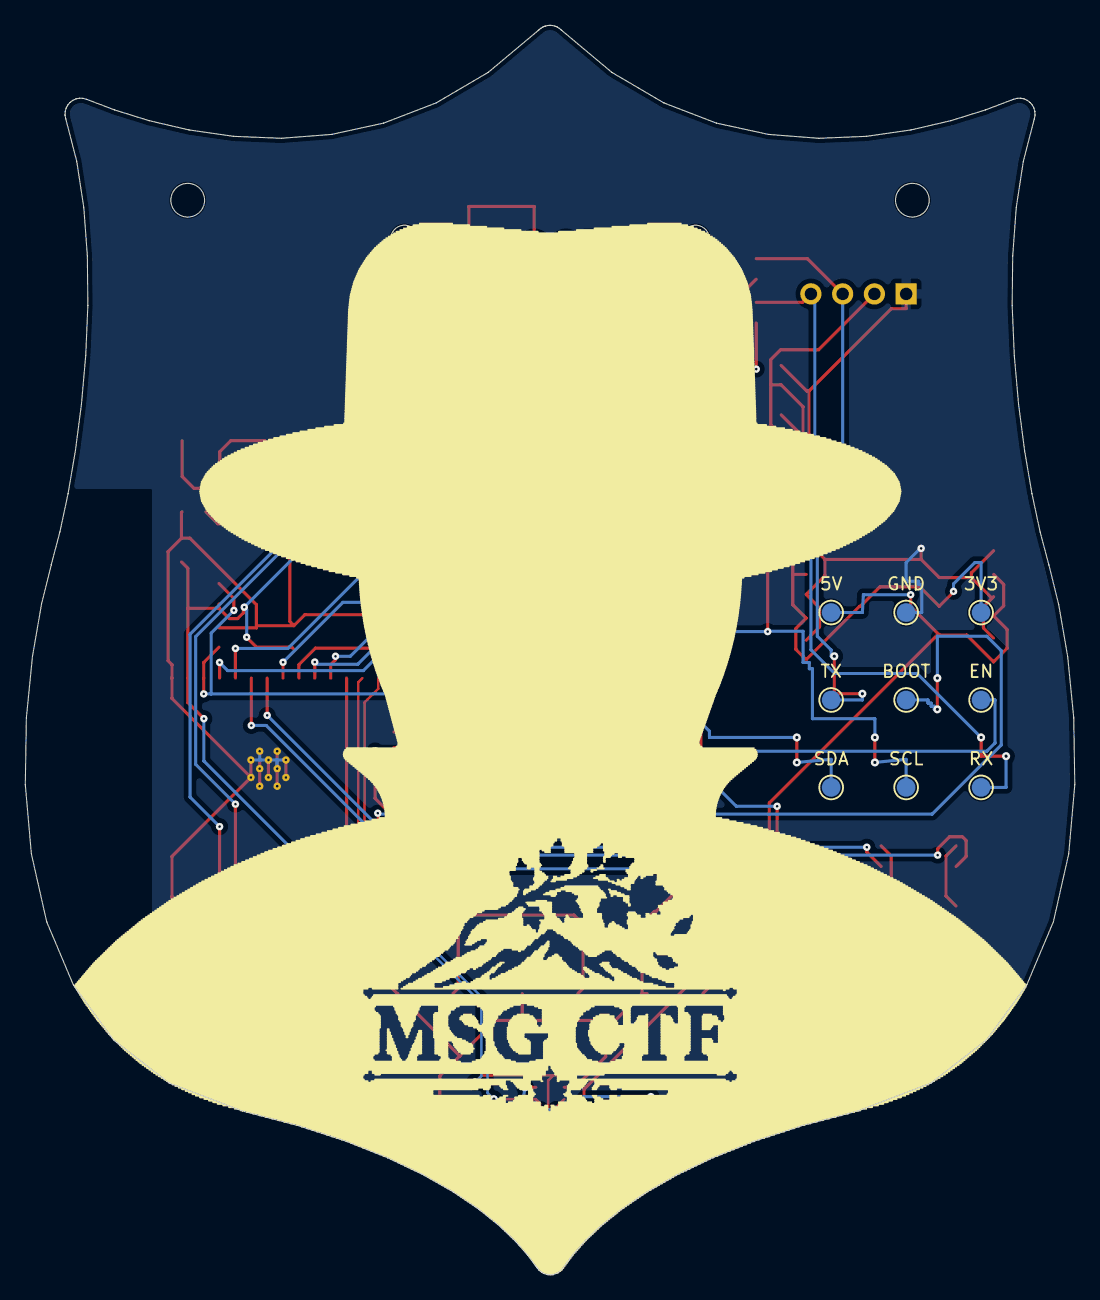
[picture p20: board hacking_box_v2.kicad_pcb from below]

Board: 2 copper layers, 84.0 x 100.0 mm, 60 parts (9 on the bottom side), 37 nets.

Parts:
BZ1: SMD5020-ZK; Buzzer_SMD5020_ZK
C1, C3, C4, C5, C7, C9: 10uF; C_0805_2012Metric
C2, C6, C8: 100nF; C_0603_1608Metric
C_EN: 1uF; C_0603_1608Metric
C_OLED: 100nF; C_0603_1608Metric
D1: USBLC6-2SC6; SOT-23-6
D_BZ: 1N4148W; D_SOD-123
H1, H2: LANYARD; MountingHole_2.7mm
J1: TYPE-C-31-M-12; USB_C_Receptacle_HRO_TYPE-C-31-M-12
LED1, LED2, LED3, LED4, LED5: RED_STATUS; LED_0603_1608Metric
OLED1: HS96L03W2C03; OLED_HS96L03W2C03
P_CHAL0, P_CHAL1, P_CHAL2: TP; TestPoint_Pad_D1.5mm
P_UART: UART_GND_3V3_TX_RX; PinHeader_1x04_P2.54mm_Vertical
Q_BZ: AO3400A; SOT-23
R1, R2: 5.1k; R_0603_1608Metric
R_BOOT: 10k; R_0603_1608Metric
R_BZ: 1k; R_0603_1608Metric
R_BZ_PD: 10k; R_0603_1608Metric
R_CHAL0, R_CHAL1, R_CHAL2: 1k; R_0603_1608Metric
R_EN: 10k; R_0603_1608Metric
R_LED1, R_LED2, R_LED3, R_LED4, R_LED5: 1k; R_0603_1608Metric
R_SCL: 10k; R_0603_1608Metric
R_SDA: 10k; R_0603_1608Metric
R_UART_RX: 1k; R_0603_1608Metric
R_UART_TX: 1k; R_0603_1608Metric
SW_ADMIN: ADMIN; SW_SPST_TS-1088-xR020
SW_BOOT: BOOT; SW_SPST_TS-1088-xR020
SW_EN: RESET; SW_SPST_TS-1088-xR020
TP_3V3: TP; TestPoint_Pad_D1.5mm
TP_BOOT: TP; TestPoint_Pad_D1.5mm
TP_EN: TP; TestPoint_Pad_D1.5mm
TP_GND: TP; TestPoint_Pad_D1.5mm
TP_OLED_SCL: TP; TestPoint_Pad_D1.5mm
TP_OLED_SDA: TP; TestPoint_Pad_D1.5mm
TP_UART_RX: TP; TestPoint_Pad_D1.5mm
TP_UART_TX: TP; TestPoint_Pad_D1.5mm
TP_VBUS: TP; TestPoint_Pad_D1.5mm
U1: ESP32-S3-WROOM-1-N8R8; ESP32-S3-WROOM-1
U2: AMS1117-3.3; SOT-223-3_TabPin2

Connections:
3V3: BZ1.1, C4.1, C5.1, C6.1, C7.1, C8.1, C9.1, C_OLED.1, D_BZ.1, OLED1.2, P_UART.2, R_BOOT.1, R_EN.1, R_SCL.1, R_SDA.1, TP_3V3.1, U1.2, U2.2
BOOT_GPIO0: R_BOOT.2, TP_BOOT.1, U1.27
BUZZER_GATE: Q_BZ.1, R_BZ.2, R_BZ_PD.1
BUZZER_GPIO: R_BZ.1, U1.11
BUZZER_SW: BZ1.2, D_BZ.2, Q_BZ.3
CHAL_0: P_CHAL0.1, R_CHAL0.2
CHAL_0_MCU: R_CHAL0.1, U1.6
CHAL_1: P_CHAL1.1, R_CHAL1.2
CHAL_1_MCU: R_CHAL1.1, U1.7
CHAL_2: P_CHAL2.1, R_CHAL2.2
CHAL_2_MCU: R_CHAL2.1, U1.12
EN: C_EN.1, R_EN.2, TP_EN.1, U1.3
GAME_LEFT: SW_EN.1, U1.17
GAME_OK: SW_BOOT.1, U1.18
GAME_RIGHT: SW_ADMIN.1, U1.20
GND: C1.2, C2.2, C3.2, C4.2, C5.2, C6.2, C7.2, C8.2, C9.2, C_EN.2, C_OLED.2, D1.2, J1.A1, J1.A12, J1.B1, J1.B12, J1.SH, LED1.1, LED2.1, LED3.1, LED4.1, LED5.1, OLED1.1, P_UART.1, Q_BZ.2, R1.2, R2.2, R_BZ_PD.2, SW_ADMIN.2, SW_BOOT.2, SW_EN.2, TP_GND.1, U1.1, U1.40, U1.41, U2.1
OLED_SCL: OLED1.3, R_SCL.2, TP_OLED_SCL.1, U1.5
OLED_SDA: OLED1.4, R_SDA.2, TP_OLED_SDA.1, U1.4
PLAYER_UART_RX: P_UART.4, R_UART_RX.2, TP_UART_RX.1
PLAYER_UART_TX: P_UART.3, R_UART_TX.2, TP_UART_TX.1
STATUS_LED_1_A: LED1.2, R_LED1.2
STATUS_LED_1_MCU: R_LED1.1, U1.21
STATUS_LED_2_A: LED2.2, R_LED2.2
STATUS_LED_2_MCU: R_LED2.1, U1.22
STATUS_LED_3_A: LED3.2, R_LED3.2
STATUS_LED_3_MCU: R_LED3.1, U1.8
STATUS_LED_4_A: LED4.2, R_LED4.2
STATUS_LED_4_MCU: R_LED4.1, U1.9
STATUS_LED_5_A: LED5.2, R_LED5.2
STATUS_LED_5_MCU: R_LED5.1, U1.10
UART_RX_MCU: R_UART_RX.1, U1.36
UART_TX_MCU: R_UART_TX.1, U1.37
USB_CC1: J1.A5, R1.1
USB_CC2: J1.B5, R2.1
USB_D_N: D1.1, D1.6, J1.A7, J1.B7, U1.13
USB_D_P: D1.3, D1.4, J1.A6, J1.B6, U1.14
VBUS: C1.1, C2.1, C3.1, D1.5, J1.A4, J1.A9, J1.B4, J1.B9, TP_VBUS.1, U2.3

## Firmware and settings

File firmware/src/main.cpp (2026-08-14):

#include <Arduino.h>
#include <Preferences.h>
#include <U8x8lib.h>
#include <WebServer.h>
#include <WiFi.h>

#include "logic.h"
#include "pins.h"
#include "problems.h"

namespace {
constexpr uint32_t SERIAL_BAUD = 115200;
constexpr uint32_t BUTTON_DEBOUNCE_MS = 30;
constexpr uint32_t HIDDEN_HOLD_MS = 1200;
constexpr uint32_t ADMIN_BOOT_HOLD_MS = 1500;
constexpr uint16_t REACTION_REWARD_MS = 300;
constexpr char START_COMMAND[] = "aegis";
constexpr char ADMIN_USER[] = "admin";

Preferences preferences;
WebServer server(80);
U8X8_SSD1315_128X64_NONAME_HW_I2C oled(U8X8_PIN_NONE, Pins::OLED_SCL,
                                       Pins::OLED_SDA);

uint8_t solvedMask = 0;
int8_t activeProblem = -1;
uint8_t menuItem = 0;
uint8_t browserProblem = 0;
bool adminEnabled = false;
uint32_t hiddenSince = 0;
char wifiSsid[20] = {};
char wifiPassword[13] = {};
char webPassword[13] = {};
char serialLine[192] = {};
uint8_t serialLength = 0;

enum class Screen : uint8_t { Home, Problems, Hint, Status, Game };
enum class GamePhase : uint8_t { Waiting, Go, Result, TooSoon };
Screen screen = Screen::Home;
GamePhase gamePhase = GamePhase::Waiting;
uint32_t gameAt = 0;
uint16_t lastReactionMs = 0;

struct Button {
  uint8_t pin;
  bool stable = false;
  bool raw = false;
  bool pressed = false;
  uint32_t changedAt = 0;

  explicit Button(uint8_t buttonPin) : pin(buttonPin) {}

  void begin() {
    pinMode(pin, INPUT_PULLUP);
    stable = raw = digitalRead(pin) == LOW;
  }

  void update(uint32_t now) {
    pressed = false;
    const bool next = digitalRead(pin) == LOW;
    if (next != raw) {
      raw = next;
      changedAt = now;
    }
    if (raw != stable && now - changedAt >= BUTTON_DEBOUNCE_MS) {
      stable = raw;
      pressed = stable;
    }
  }
};

Button left{Pins::BUTTON_LEFT};
Button ok{Pins::BUTTON_OK};
Button right{Pins::BUTTON_RIGHT};

void line(uint8_t row, const char *text) {
  oled.clearLine(row);
  oled.drawString(0, row, text);
}

uint8_t solvedCount() {
  uint8_t count = 0;
  for (uint8_t i = 0; i < TOTAL_CHALLENGE_COUNT; ++i) {
    count += isSolved(solvedMask, i);
  }
  return count;
}

bool allSolved() {
  return (solvedMask & solvedMaskFor(TOTAL_CHALLENGE_COUNT)) ==
         solvedMaskFor(TOTAL_CHALLENGE_COUNT);
}

void updateLeds() {
  for (uint8_t i = 0; i < TOTAL_CHALLENGE_COUNT; ++i) {
    digitalWrite(Pins::STATUS_LEDS[i], isSolved(solvedMask, i) ? HIGH : LOW);
  }
}

void saveMask() {
  preferences.putUChar("solved", solvedMask);
  updateLeds();
}

void configureHiddenAccessPins() {
  hiddenSince = 0;
  if (isSolved(solvedMask, HIDDEN_ACCESS_INDEX)) {
    pinMode(Pins::CHALLENGE_0, INPUT);
    pinMode(Pins::CHALLENGE_1, INPUT);
    pinMode(Pins::CHALLENGE_2, INPUT);
    return;
  }
  pinMode(Pins::CHALLENGE_0, OUTPUT);
  digitalWrite(Pins::CHALLENGE_0, LOW);
  pinMode(Pins::CHALLENGE_1, INPUT_PULLUP);
  pinMode(Pins::CHALLENGE_2, INPUT_PULLUP);
}

void beep(uint16_t frequency = 880, uint16_t duration = 70) {
  tone(Pins::BUZZER, frequency, duration);
}

void drawHome() {
  static const char *const items[] = {"Problems", "Mini game", "Status"};
  char progress[17];
  snprintf(progress, sizeof(progress), "Solved %u/%u", solvedCount(),
           static_cast<unsigned>(TOTAL_CHALLENGE_COUNT));
  oled.clearDisplay();
  line(0, "AEGIS HACK BADGE");
  line(2, progress);
  line(4, items[menuItem]);
  line(7, "<      OK      >");
}

void drawProblems() {
  char number[17];
  snprintf(number, sizeof(number), "Problem %u/%u %c",
           static_cast<unsigned>(browserProblem + 1),
           static_cast<unsigned>(SERIAL_PROBLEM_COUNT),
           isSolved(solvedMask, browserProblem) ? 'O' : 'X');
  oled.clearDisplay();
  line(0, "SERIAL PROBLEMS");
  line(2, number);
  line(4, PROBLEMS[browserProblem].title);
  line(7, "<  OK:show   >");
}

void drawHint(uint8_t index) {
  oled.clearDisplay();
  line(0, PROBLEMS[index].title);
  for (uint8_t row = 0; row < 5; ++row) {
    line(row + 2, PROBLEMS[index].oledLines[row]);
  }
  line(7, "OK: menu");
}

void drawStatus() {
  char row[17];
  oled.clearDisplay();
  line(0, allSolved() ? "ALL CLEAR" : "BADGE STATUS");
  for (uint8_t i = 0; i < TOTAL_CHALLENGE_COUNT; ++i) {
    snprintf(row, sizeof(row), "%u:%c %s", i + 1,
             isSolved(solvedMask, i) ? 'O' : 'X',
             i == HIDDEN_ACCESS_INDEX ? "Hidden" : PROBLEMS[i].title);
    line(i + 1, row);
  }
  line(7, "OK: menu");
}

void printBanner() {
  Serial.println();
  Serial.println(F("=== Aegis Hack The Badge / Rev.3 ==="));
  Serial.println(F("문제 본문: Serial / 보기와 예시: OLED"));
  Serial.println(F("명령: 1-4, status, help, hint, exit, clear, reset, aegis"));
  Serial.println(F("Hidden Access는 번호 선택형 문제가 아닙니다."));
}

void printStatus() {
  Serial.println(F("\n[challenge status]"));
  for (uint8_t i = 0; i < TOTAL_CHALLENGE_COUNT; ++i) {
    Serial.printf("%u. %-13s [%c]\n", i + 1,
                  i == HIDDEN_ACCESS_INDEX ? "Hidden Access" : PROBLEMS[i].title,
                  isSolved(solvedMask, i) ? 'O' : 'X');
  }
}

void showProblem(uint8_t index) {
  activeProblem = index;
  screen = Screen::Hint;
  drawHint(index);
  Serial.println();
  Serial.println(PROBLEMS[index].serialText);
  Serial.println(F("\n보기/예시는 OLED를 확인하세요. FLAG 또는 exit를 입력하세요."));
  beep(659);
}

void solved(uint8_t index) {
  const uint8_t next = markSolved(solvedMask, index);
  if (next != solvedMask) {
    solvedMask = next;
    saveMask();
  }
  Serial.printf("정답입니다. 진행도: %u/%u\n", solvedCount(),
                static_cast<unsigned>(TOTAL_CHALLENGE_COUNT));
  beep(1047, 130);
  activeProblem = -1;
  screen = Screen::Status;
  drawStatus();
}

void handleSerialLine(char *input) {
  while (*input == ' ' || *input == '\t') ++input;
  char *end = input + strlen(input);
  while (end > input && (end[-1] == ' ' || end[-1] == '\t')) --end;
  *end = '\0';
  if (*input == '\0') return;

  if (activeProblem >= 0) {
    if (strcmp(input, "exit") == 0) {
      activeProblem = -1;
      screen = Screen::Home;
      drawHome();
      Serial.println(F("문제에서 나왔습니다."));
    } else if (strcmp(input, "hint") == 0) {
      drawHint(activeProblem);
      Serial.println(F("OLED에 보기/예시를 다시 표시했습니다."));
    } else if (strcmp(input, PROBLEMS[activeProblem].answer) == 0) {
      solved(activeProblem);
    } else {
      Serial.println(F("정답이 아닙니다. 다시 시도하거나 exit를 입력하세요."));
      beep(196, 150);
    }
    return;
  }

  if (strlen(input) == 1 && input[0] >= '1' &&
      input[0] < '1' + static_cast<int>(SERIAL_PROBLEM_COUNT)) {
    showProblem(input[0] - '1');
  } else if (strcmp(input, "status") == 0) {
    printStatus();
  } else if (strcmp(input, "help") == 0) {
    Serial.println(F("1-4 중 하나를 선택하고 Serial에 FLAG를 제출하세요."));
    Serial.println(F("문제의 보기/예시는 OLED에만 표시됩니다."));
    Serial.println(F("OLED 미니게임은 하단 3개 버튼으로 플레이합니다."));
  } else if (strcmp(input, "hint") == 0) {
    Serial.println(F("먼저 1-4 중 문제를 선택하세요."));
  } else if (strcmp(input, "clear") == 0) {
    for (uint8_t i = 0; i < 30; ++i) Serial.println();
  } else if (strcmp(input, "reset") == 0) {
    solvedMask = 0;
    saveMask();
    configureHiddenAccessPins();
    activeProblem = -1;
    screen = Screen::Home;
    drawHome();
    Serial.println(F("진행 상태를 초기화했습니다."));
  } else if (strcmp(input, START_COMMAND) == 0) {
    printBanner();
  } else {
    Serial.println(F("알 수 없는 명령입니다. help를 입력하세요."));
  }
}

void pollSerial() {
  while (Serial.available()) {
    const char c = static_cast<char>(Serial.read());
    if (c == '\r') continue;
    if (c == '\n') {
      serialLine[serialLength] = '\0';
      handleSerialLine(serialLine);
      serialLength = 0;
    } else if (serialLength + 1 < sizeof(serialLine)) {
      serialLine[serialLength++] = c;
    } else {
      serialLength = 0;
      Serial.println(F("입력이 너무 깁니다."));
    }
  }
}

void startReactionGame() {
  screen = Screen::Game;
  gamePhase = GamePhase::Waiting;
  gameAt = millis() + random(1200, 3501);
  oled.clearDisplay();
  line(0, "REACTION TEST");
  line(3, "WAIT...");
  line(7, "do not press");
}

void showGameResult() {
  char score[17];
  snprintf(score, sizeof(score), "%u ms", lastReactionMs);
  oled.clearDisplay();
  line(0, "REACTION RESULT");
  line(2, score);
  if (lastReactionMs <= REACTION_REWARD_MS) {
    line(4, MINIGAME_REWARD_LINE_1);
    line(5, MINIGAME_REWARD_LINE_2);
  }
  line(7, "OK:again <>:exit");
}

void updateGame(uint32_t now) {
  if (gamePhase == GamePhase::Waiting) {
    if (left.pressed || ok.pressed || right.pressed) {
      gamePhase = GamePhase::TooSoon;
      gameAt = now;
      oled.clearDisplay();
      line(2, "TOO SOON!");
      line(5, "OK: retry");
      beep(180, 180);
    } else if (static_cast<int32_t>(now - gameAt) >= 0) {
      gamePhase = GamePhase::Go;
      gameAt = now;
      oled.clearDisplay();
      line(2, "PRESS OK NOW!");
      beep(1200, 35);
    }
  } else if (gamePhase == GamePhase::Go && ok.pressed) {
    const uint32_t elapsed = now - gameAt;
    lastReactionMs = static_cast<uint16_t>(elapsed > 9999 ? 9999 : elapsed);
    gamePhase = GamePhase::Result;
    showGameResult();
  } else if ((gamePhase == GamePhase::Result || gamePhase == GamePhase::TooSoon) &&
             ok.pressed) {
    startReactionGame();
  } else if ((gamePhase == GamePhase::Result || gamePhase == GamePhase::TooSoon) &&
             (left.pressed || right.pressed)) {
    screen = Screen::Home;
    drawHome();
  }
}

void updateUi(uint32_t now) {
  left.update(now);
  ok.update(now);
  right.update(now);

  if (screen == Screen::Game) {
    updateGame(now);
    return;
  }

  if (screen == Screen::Home) {
    if (left.pressed) {
      menuItem = (menuItem + 2) % 3;
      drawHome();
    } else if (right.pressed) {
      menuItem = (menuItem + 1) % 3;
      drawHome();
    } else if (ok.pressed) {
      if (menuItem == 0) {
        screen = Screen::Problems;
        drawProblems();
      } else if (menuItem == 1) {
        startReactionGame();
      } else {
        screen = Screen::Status;
        drawStatus();
      }
    }
  } else if (screen == Screen::Problems) {
    if (left.pressed) {
      browserProblem = (browserProblem + SERIAL_PROBLEM_COUNT - 1) % SERIAL_PROBLEM_COUNT;
      drawProblems();
    } else if (right.pressed) {
      browserProblem = (browserProblem + 1) % SERIAL_PROBLEM_COUNT;
      drawProblems();
    } else if (ok.pressed) {
      showProblem(browserProblem);
    }
  } else if (ok.pressed) {
    screen = Screen::Home;
    drawHome();
  }
}

void updateHiddenAccess(uint32_t now) {
  if (isSolved(solvedMask, HIDDEN_ACCESS_INDEX)) return;

  const bool matched = hiddenAccessMatched(digitalRead(Pins::CHALLENGE_1) == LOW,
                                           digitalRead(Pins::CHALLENGE_2) == LOW);
  if (!matched) {
    hiddenSince = 0;
  } else if (hiddenSince == 0) {
    hiddenSince = now;
  } else if (now - hiddenSince >= HIDDEN_HOLD_MS) {
    solvedMask = markSolved(solvedMask, HIDDEN_ACCESS_INDEX);
    saveMask();
    configureHiddenAccessPins();
    Serial.println(F("\n[Hidden Access] unlocked."));
    screen = Screen::Status;
    drawStatus();
    beep(1568, 180);
  }
}

bool adminAuth() {
  if (server.authenticate(ADMIN_USER, webPassword)) return true;
  server.requestAuthentication();
  return false;
}

const char ADMIN_HTML[] PROGMEM = R"HTML(
<!doctype html><meta name=viewport content="width=device-width">
<title>Aegis Badge Admin</title>
<style>body{font:16px system-ui;max-width:36rem;margin:2rem auto;padding:0 1rem}button{padding:.7rem;margin:.25rem}pre{background:#eee;padding:1rem}</style>
<h1>Aegis Badge Admin</h1><pre id=s>loading...</pre>
<div id=b></div><button onclick="post('/api/reset')">Reset all</button>
<button onclick="post('/api/reboot')">Reboot</button>
<script>
async function load(){let r=await fetch('/api/status');let j=await r.json();s.textContent=JSON.stringify(j,null,2);b.innerHTML='';for(let i=1;i<=j.total;i++)b.innerHTML+=`<button onclick="post('/api/solve?id=${i}')">Solve ${i}</button>`}
async function post(u){await fetch(u,{method:'POST'});setTimeout(load,200)}load()
</script>)HTML";

void sendAdminStatus() {
  if (!adminAuth()) return;
  char json[192];
  snprintf(json, sizeof(json),
           "{\"solvedMask\":%u,\"solved\":%u,\"total\":%u,"
           "\"serialProblems\":%u,\"hiddenSolved\":%s}",
           solvedMask, solvedCount(), static_cast<unsigned>(TOTAL_CHALLENGE_COUNT),
           static_cast<unsigned>(SERIAL_PROBLEM_COUNT),
           isSolved(solvedMask, HIDDEN_ACCESS_INDEX) ? "true" : "false");
  server.send(200, "application/json", json);
}

void setupAdminRoutes() {
  server.on("/", HTTP_GET, [] {
    if (adminAuth()) server.send_P(200, "text/html", ADMIN_HTML);
  });
  server.on("/api/status", HTTP_GET, sendAdminStatus);
  server.on("/api/solve", HTTP_POST, [] {
    if (!adminAuth()) return;
    const int id = server.arg("id").toInt();
    if (id < 1 || id > static_cast<int>(TOTAL_CHALLENGE_COUNT)) {
      server.send(400, "application/json", "{\"error\":\"bad id\"}");
      return;
    }
    solvedMask = markSolved(solvedMask, id - 1);
    saveMask();
    configureHiddenAccessPins();
    screen = Screen::Status;
    drawStatus();
    server.send(200, "application/json", "{\"ok\":true}");
  });
  server.on("/api/reset", HTTP_POST, [] {
    if (!adminAuth()) return;
    solvedMask = 0;
    saveMask();
    configureHiddenAccessPins();
    activeProblem = -1;
    screen = Screen::Status;
    drawStatus();
    server.send(200, "application/json", "{\"ok\":true}");
  });
  server.on("/api/reboot", HTTP_POST, [] {
    if (!adminAuth()) return;
    server.send(200, "application/json", "{\"ok\":true}");
    delay(100);
    ESP.restart();
  });
  server.onNotFound([] {
    if (adminAuth()) server.send(404, "text/plain", "not found");
  });
}

void randomCredential(char *output, size_t length) {
  constexpr char alphabet[] = "ABCDEFGHJKLMNPQRSTUVWXYZ23456789";
  for (size_t i = 0; i + 1 < length; ++i) {
    output[i] = alphabet[esp_random() % (sizeof(alphabet) - 1)];
  }
  output[length - 1] = '\0';
}

bool adminChordHeld() {
  const uint32_t start = millis();
  while (millis() - start < ADMIN_BOOT_HOLD_MS) {
    if (digitalRead(Pins::BUTTON_LEFT) != LOW ||
        digitalRead(Pins::BUTTON_RIGHT) != LOW) return false;
    delay(10);
  }
  return true;
}

void startAdmin() {
  const uint64_t mac = ESP.getEfuseMac();
  snprintf(wifiSsid, sizeof(wifiSsid), "AegisBadge-%04X",
           static_cast<unsigned>(mac & 0xffff));
  randomCredential(wifiPassword, sizeof(wifiPassword));
  randomCredential(webPassword, sizeof(webPassword));

  WiFi.mode(WIFI_AP);
  if (!WiFi.softAP(wifiSsid, wifiPassword)) {
    Serial.println(F("Admin AP start failed."));
    return;
  }
  setupAdminRoutes();
  server.begin();
  adminEnabled = true;

  oled.clearDisplay();
  line(0, "ADMIN WIFI ON");
  line(1, wifiSsid);
  line(2, "WiFi password:");
  line(3, wifiPassword);
  line(4, "user: admin");
  line(5, "web password:");
  line(6, webPassword);
  line(7, "192.168.4.1");

  Serial.printf("\nAdmin AP: %s\nWiFi password: %s\n", wifiSsid, wifiPassword);
  Serial.printf("URL: http://192.168.4.1 / user: %s / password: %s\n",
                ADMIN_USER, webPassword);
}
} // namespace

void setup() {
  Serial.begin(SERIAL_BAUD);
  pinMode(Pins::BUZZER, OUTPUT);
  digitalWrite(Pins::BUZZER, LOW);

  for (uint8_t pin : Pins::STATUS_LEDS) {
    pinMode(pin, OUTPUT);
    digitalWrite(pin, LOW);
  }
  left.begin();
  ok.begin();
  right.begin();

  oled.setI2CAddress(0x3c << 1);
  oled.setBusClock(400000);
  oled.begin();
  oled.setFont(u8x8_font_chroma48medium8_r);

  preferences.begin("badge", false);
  solvedMask = preferences.getUChar("solved", 0) &
               solvedMaskFor(TOTAL_CHALLENGE_COUNT);
  updateLeds();

  configureHiddenAccessPins();

  randomSeed(esp_random());
  printBanner();
  if (adminChordHeld()) {
    startAdmin();
  } else {
    drawHome();
  }
  beep(880, 60);
}

void loop() {
  const uint32_t now = millis();
  pollSerial();
  updateUi(now);
  updateHiddenAccess(now);
  if (adminEnabled) server.handleClient();
  delay(1);
}

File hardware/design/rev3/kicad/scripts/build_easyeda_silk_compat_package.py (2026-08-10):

#!/usr/bin/env python3
"""Build an EasyEDA Pro import package with line-hatched silkscreen artwork.

EasyEDA Pro's KiCad importer can preserve complex silkscreen outlines while
dropping the filled area of KiCad graphic polygons.  The manufacturing KiCad
project remains untouched; this script creates a derived import package where
top-level filled silkscreen polygons are replaced by dense graphic lines.
"""

from __future__ import annotations

from dataclasses import dataclass
from pathlib import Path
import math
import re
import shutil
import uuid
import zipfile


ROOT = Path(__file__).resolve().parents[1]
PROJECT_ROOT = ROOT.parents[3]
SOURCE_PCB = ROOT / "hacking_box_v2.kicad_pcb"
RELEASE_ROOT = PROJECT_ROOT / "hardware" / "releases" / "rev3" / "easyeda-pro"
COMPAT_ROOT = RELEASE_ROOT / "silk-compat" / "hacking_badge_v3_easyeda_silk_compat"
UPLOAD_ZIP = RELEASE_ROOT / "upload" / "hacking_badge_v3_easyeda_pro_silk_compat_import.zip"
CHECKSUMS = RELEASE_ROOT / "SHA256SUMS.txt"

HATCH_PITCH_MM = 0.13
HATCH_WIDTH_MM = 0.15
MIN_SEGMENT_MM = 0.08
HATCH_UUID_NAMESPACE = uuid.UUID("d62b73f1-b630-42c5-b4b6-2f33e8aa7e17")

LIB_SYMBOL_FOOTPRINT_DEFAULTS = {
    "HB_BUZZER": "HackingBox_V2:Buzzer_SMD5020_ZK",
    "HB_C": "Capacitor_SMD:C_0603_1608Metric",
    "HB_CONN4": "Connector_PinHeader_2.54mm:PinHeader_1x04_P2.54mm_Vertical",
    "HB_DIODE": "Diode_SMD:D_SOD-123",
    "HB_ESD6": "Package_TO_SOT_SMD:SOT-23-6",
    "HB_ESP32": "RF_Module:ESP32-S3-WROOM-1",
    "HB_FET3": "Package_TO_SOT_SMD:SOT-23",
    "HB_LED": "LED_SMD:LED_0603_1608Metric",
    "HB_MECH": "MountingHole:MountingHole_2.7mm",
    "HB_OLED": "HackingBox_V2:OLED_HS96L03W2C03",
    "HB_R": "Resistor_SMD:R_0603_1608Metric",
    "HB_REG3": "Package_TO_SOT_SMD:SOT-223-3_TabPin2",
    "HB_SW": "Button_Switch_SMD:SW_SPST_TS-1088-xR020",
    "HB_TP": "TestPoint:TestPoint_Pad_D1.5mm",
    "HB_USB": "Connector_USB:USB_C_Receptacle_HRO_TYPE-C-31-M-12",
}


@dataclass(frozen=True)
class PolygonBlock:
    start: int
    end: int
    text: str
    layer: str
    points: tuple[tuple[float, float], ...]


def find_matching_paren(text: str, start: int) -> int:
    depth = 0
    in_string = False
    escaped = False
    for index in range(start, len(text)):
        char = text[index]
        if in_string:
            if escaped:
                escaped = False
            elif char == "\\":
                escaped = True
            elif char == '"':
                in_string = False
            continue
        if char == '"':
            in_string = True
        elif char == "(":
            depth += 1
        elif char == ")":
            depth -= 1
            if depth == 0:
                return index + 1
    raise RuntimeError("Unbalanced KiCad PCB file")


def extract_silk_polygons(text: str) -> list[PolygonBlock]:
    blocks: list[PolygonBlock] = []
    for match in re.finditer(r"\n\t\(gr_poly\b", text):
        start = match.start() + 1
        end = find_matching_paren(text, start + 1)
        block = text[start:end]
        layer_match = re.search(r'\(layer "([FB]\.SilkS)"\)', block)
        if layer_match is None:
            continue
        if "(fill solid)" not in block and "(fill yes)" not in block:
            continue
        points = tuple(
            (float(x), float(y))
            for x, y in re.findall(
                r"\(xy\s+([-+]?\d+(?:\.\d+)?)\s+([-+]?\d+(?:\.\d+)?)\)",
                block,
            )
        )
        if len(points) < 3:
            continue
        blocks.append(
            PolygonBlock(start, end, block, layer_match.group(1), points)
        )
    return blocks


def scanline_segments(
    points: tuple[tuple[float, float], ...],
) -> list[tuple[float, float, float, float]]:
    if points[0] != points[-1]:
        polygon = points + (points[0],)
    else:
        polygon = points

    min_y = min(y for _, y in polygon)
    max_y = max(y for _, y in polygon)
    first_y = math.floor(min_y / HATCH_PITCH_MM) * HATCH_PITCH_MM
    y = first_y
    segments: list[tuple[float, float, float, float]] = []
    while y <= max_y + HATCH_PITCH_MM:
        if y < min_y:
            y += HATCH_PITCH_MM
            continue
        intersections: list[float] = []
        for (x1, y1), (x2, y2) in zip(polygon, polygon[1:]):
            if y1 == y2:
                continue
            low = min(y1, y2)
            high = max(y1, y2)
            if not (low <= y < high):
                continue
            x = x1 + (y - y1) * (x2 - x1) / (y2 - y1)
            intersections.append(x)
        intersections.sort()
        for x1, x2 in zip(intersections[0::2], intersections[1::2]):
            if x2 - x1 >= MIN_SEGMENT_MM:
                segments.append((x1, y, x2, y))
        y += HATCH_PITCH_MM
    return segments


def line_text(
    segment: tuple[float, float, float, float],
    layer: str,
    stable_id: str,
) -> str:
    x1, y1, x2, y2 = segment
    return (
        "\t(gr_line\n"
        f"\t\t(start {x1:.6f} {y1:.6f})\n"
        f"\t\t(end {x2:.6f} {y2:.6f})\n"
        "\t\t(stroke\n"
        f"\t\t\t(width {HATCH_WIDTH_MM:.2f})\n"
        "\t\t\t(type solid)\n"
        "\t\t)\n"
        f"\t\t(layer \"{layer}\")\n"
        f"\t\t(uuid \"{uuid.uuid5(HATCH_UUID_NAMESPACE, stable_id)}\")\n"
        "\t)"
    )


def convert_pcb_silkscreen(text: str) -> tuple[str, int, int]:
    polygons = extract_silk_polygons(text)
    pieces: list[str] = []
    cursor = 0
    line_count = 0
    for polygon_index, polygon in enumerate(polygons):
        pieces.append(text[cursor:polygon.start])
        segments = scanline_segments(polygon.points)
        pieces.append(
            "\n".join(
                line_text(
                    segment,
                    polygon.layer,
                    f"{polygon_index}:{segment_index}:{polygon.layer}:{segment}",
                )
                for segment_index, segment in enumerate(segments)
            )
        )
        line_count += len(segments)
        cursor = polygon.end
    pieces.append(text[cursor:])
    return "".join(pieces), len(polygons), line_count


def remove_editor_groups(text: str) -> tuple[str, int]:
    """Drop KiCad editor-only groups from the derived import board.

    Some logo artwork is grouped in KiCad.  After replacing grouped polygons
    with hatch lines, the old group references can point to deleted UUIDs.
    Groups are not manufacturing data, so removing them keeps the EasyEDA
    import package simple and avoids stale references.
    """

    pieces: list[str] = []
    cursor = 0
    group_count = 0
    for match in re.finditer(r"\n\t\(group\b", text):
        start = match.start() + 1
        end = find_matching_paren(text, start + 1)
        pieces.append(text[cursor:start])
        cursor = end
        group_count += 1
    pieces.append(text[cursor:])
    return "".join(pieces), group_count
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

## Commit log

2026-08-10 Prepare Hacking Badge v3 production release
    [bom-draft.csv, hacking_badge_v3_assembly.step, hacking_badge_v3_jlcpcb_bom.csv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]
2026-08-10 Add EasyEDA silkscreen-compatible package
    [hacking_box_v2.kicad_pcb, hacking_box_v2.kicad_sch]
2026-08-10 Fix EasyEDA import schematic footprints
    [hacking_box_v2.kicad_pcb, hacking_box_v2.kicad_sch]
2026-08-10 Patch EasyEDA cache library footprints
2026-08-13 Add Hacking Badge v3 3D assembly exports
    [hacking_badge_v3_full_assembly.step]
2026-08-13 Add black PCB 3D assembly export
2026-09-14 feat/fix: 플레이어 콘솔, 벳지 버그 수정 및 브릿지 서버 morse link 전송 기능 구현
2026-11-06 feat: 웹 콘솔 안정화 및 펌웨어 수정
